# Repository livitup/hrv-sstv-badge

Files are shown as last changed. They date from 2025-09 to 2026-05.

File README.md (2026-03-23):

# DEFCON SSTV Badge






An open-source SSTV (Slow Scan Television) badge designed for DEFCON and the broader badgelife community. This badge combines amateur radio, digital imaging, and social interaction into a wearable electronic art piece shaped like a Simpsons-style retro TV with rabbit ear antennas.

## Project Overview

The DEFCON SSTV Badge enables users to:
- **Capture photos** with an integrated 2MP OV2640 camera
- **Encode images** into SSTV format with callsign overlay
- **Transmit images** via VHF/UHF radio using the SA818 transceiver
- **Receive SSTV signals** from other badges and stations
- **Store and browse** images on microSD card
- **Interact socially** through visual radio communication

Perfect for ham radio operators, makers, and anyone interested in digital modes and RF experimentation.

## Features

### Hardware Capabilities
- **RP2350B Dual-Core MCU** - QFN-80, 48 GPIOs, dedicated cores for UI and signal processing
- **SA818 VHF/UHF Transceiver** - 1W output on swappable carrier board (see below)
- **OV2640 2MP Camera** - Parallel DVP interface with 15-20 FPS live viewfinder via PIO
- **2.4" ILI9341 TFT Display** - 320x240 landscape, SPI interface
- **PCM5102A DAC + RP2350 ADC** - I2S DAC for TX audio, internal ADC for RX audio
- **MicroSD Storage** - Standalone SD socket (J10), shared SPI bus with display
- **2000mAh LiPo Battery** - 8-10 hours operation with USB-C charging
- **2x SAO Connectors** - Standard Shitty Add-On expansion ports
- **26x WS2812B LEDs** - Animated blinky chain across rabbit ears and display border

### Radio Features
- **Dual-Band Support** - VHF (134-174 MHz) and UHF (400-480 MHz) via carrier board swap
- **Multiple SSTV Modes** - Martin, Scottie, Robot modes with auto-detection
- **Automatic Operation** - No manual PTT required
- **Airplane Mode** - Physical slide switch to disable RF
- **SMA Antenna Port** - On carrier board, right-angle connector with antenna pointing up

### User Interface
- **5-Way D-Pad** - Navigation, menu selection, and photo capture (center button doubles as shutter)
- **Airplane Mode Switch** - Slide switch for RF enable/disable
- **PWR LED** - Traditional RGB LED for battery and system status
- **Blinky LEDs** - 26x WS2812B chain with animated TX/RX/idle patterns
- **Customizable Settings** - Callsign, frequency, SSTV mode, and more

## SA818 Carrier Board System

The SA818 transceiver has 2mm pitch castellated pads that are incompatible with user-swappable sockets. Instead of mounting the SA818 directly on the main badge, the design uses a full-width carrier board system.

### How It Works

The carrier board is a separate PCB (full badge width, ~120mm) that overlays the top portion of the main badge. The SA818 module, SMA connector, and antenna are ALL on the carrier board -- the main badge has zero RF traces.

**Mounting:** 4-point connection via 2x 1x8 signal headers (bottom edge) + 2x 1x3 mechanical headers (top corners, grounded for RF shielding).

**Band detection:** Each carrier has an ID resistor (0 ohm for VHF, DNP for UHF) read by the RP2350B on startup. The firmware automatically detects which carrier is installed and configures frequency limits accordingly. No DIP switches or manual configuration needed.

### Carrier Variants

- **SA818-V Carrier** - VHF (134-174 MHz) with matched VHF stubby antenna
- **SA818-U Carrier** - UHF (400-480 MHz) with matched UHF stubby antenna

### Swapping Carriers

1. Power down the badge
2. Unplug the current carrier board from the headers
3. Plug in the replacement carrier (VHF or UHF)
4. Power on -- firmware auto-detects the band and configures itself

Each carrier includes a band-matched stubby antenna, so users do not need to source separate antennas.

### Design Benefits

- Main badge PCB has no RF routing, simplifying layout and potentially enabling 2-layer PCB
- Carrier board has proper 50-ohm microstrip trace from SA818 to SMA
- Ground stitching around RF trace on carrier for shielding
- SA818 is factory-assembled onto carrier (2mm pitch not user-solderable)

## Power System

The SA818 draws up to 1.7A during TX, which would overwhelm a standard 3.3V regulator. The power system separates the radio from the digital rail:

```
LiPo (3.0-4.2V) --+---> TPS63001 (buck-boost) ---> 3.3V Rail (RP2350B, display, camera, etc.)
                   |
                   +---> TPS22919 (load switch) ---> SA818 (3.5-5.5V direct from LiPo)
```

- **TPS63001**: Buck-boost regulator, 3.3V output, handles full LiPo voltage range (3.0-4.2V)
- **TPS22919**: Load switch controls SA818 power (enables airplane mode and sleep)
- **MCP73871**: Battery charging controller with USB-C input
- **LC709203F**: Battery fuel gauge (I2C)

## Amateur Radio License Verification System

To comply with FCC Part 97 regulations, the badge includes a software-based license verification system.

### Operating Modes

- **Receive-Only Mode**: Default for unlicensed users. Can receive and decode SSTV images but cannot transmit.
- **Licensed Mode**: Full TX/RX for verified amateur radio operators.

### Verification Process

During initial setup, users enter their amateur radio callsign. The badge generates a unique unlock code from the callsign and the device's hardware serial number using SHA-256 hashing. This ensures each unlock code is specific to one badge-callsign combination, preventing casual code sharing between devices.

Licensed operators get full transmit capability with automatic callsign overlay on transmitted images (FCC requirement). Unlicensed users can still receive and view SSTV images -- all reception features work normally.

This system encourages proper amateur radio operation. It is not intended as absolute copy protection.

## Project Status

**Current Phase: PCB Layout**

| Milestone | Status |
|---|---|
| System architecture and block diagram | Complete |
| Schematic design (all sheets) | Complete, ERC clean |
| KiCad schematic entry | Complete (all sheets) |
| SA818 carrier board PCBs (VHF + UHF) | Complete |
| Bill of materials and sourcing | Complete |
| Main badge PCB layout | In progress |
| Firmware development | Not started |
| Prototype assembly and testing | Pending PCB fabrication |

## Repository Structure

```
hrv-sstv-badge/
├── CLAUDE.md                       # AI context file (project specs)
├── CMakeLists.txt                  # Build system
├── CONTRIBUTING.md                 # Contribution guidelines
├── LICENSE                         # MIT license
├── README.md                       # This file
├── docs/                           # Documentation
│   ├── block-diagram.png           # System overview diagram
│   ├── electrical-design.md        # Circuit schematics and component specs
│   ├── firmware-architecture.md    # Detailed software design
│   ├── bom.md                      # Bill of materials with costs
│   ├── bom-raw.md                  # Raw BOM data
│   ├── project-status.md           # Design status tracker
│   └── engineers-notebook/         # Design decisions and rationale
├── firmware/                       # RP2350B embedded firmware (not yet started)
├── hardware/                       # KiCad PCB design files
│   ├── main_badge/                 # Main badge KiCad project
│   ├── sa818-v-carrier/            # VHF carrier board KiCad project
│   ├── sa818-u-carrier/            # UHF carrier board KiCad project
│   ├── footprints.pretty/          # Custom KiCad footprints
│   ├── symbols/                    # Custom KiCad symbols
│   ├── pcb-design.md               # PCB layout guidelines
│   └── README.md                   # Hardware design notes
├── mechanical/                     # Badge accessories and mounting
└── src/                            # Source scaffolding
```

## Technical Specifications

| Parameter | Specification |
|---|---|
| **MCU** | Raspberry Pi RP2350B (QFN-80), Dual ARM Cortex-M33 |
| **Radio** | SA818 VHF/UHF on carrier board, 1W output |
| **Frequency Range** | VHF: 134-174 MHz, UHF: 400-480 MHz |
| **Camera** | OV2640, 2MP, parallel DVP (8-bit), QVGA for SSTV |
| **Display** | 2.4" ILI9341 TFT LCD, 320x240 landscape, SPI |
| **Audio TX** | PCM5102A DAC via I2S |
| **Audio RX** | RP2350B internal ADC with anti-alias filter |
| **Storage** | MicroSD via standalone SD socket J10 (shared SPI bus) |
| **Battery** | 2000mAh LiPo, USB-C charging (MCP73871) |
| **Regulator** | TPS63001 buck-boost, 3.3V output |
| **Operating Time** | 8-10 hours typical use |
| **LEDs** | 26x WS2812B (10x 5050 on ears, 16x 2020 on border) + RGB PWR LED |
| **Expansion** | 2x SAO (Shitty Add-On) connectors |
| **Dimensions** | ~120mm x 120mm body, ~190mm total height with ears and feet |
| **Form Factor** | Retro TV shape with rabbit ear antennas, wearable badge (no enclosure) |

## Software Architecture

The firmware uses a bare-metal dual-core design on the RP2350B for deterministic SSTV timing:

- **Core 0**: User interface, file system, system management, display updates
- **Core 1**: SSTV encoding/decoding, audio DSP, camera control, radio management

PIO state machines handle hardware-timed signals (camera capture, WS2812B data, audio clocking). DMA transfers move data without CPU intervention. No RTOS -- bare metal for microsecond-precision SSTV timing.

### Development Environment
- **Language**: C11 (ISO/IEC 9899:2011)
- **Compiler**: GCC ARM Embedded (arm-none-eabi-gcc)
- **Build System**: CMake with Raspberry Pi Pico SDK
- **Debugger**: OpenOCD + GDB via SWD (Tag-Connect)

## Assembly Model

This badge uses a production kit approach:

- **Factory-assembled**: All SMD components on main badge, SA818 onto carrier boards
- **User-assembled at conference**: Through-hole parts (switches, connectors, pin headers)
- **User-configured**: Plug in VHF or UHF carrier board, insert battery, insert SD card

## Getting Started

### Prerequisites
- **Amateur Radio License** - Required for transmit operation (receive works without)
- **Basic Soldering Skills** - Through-hole soldering for final assembly

### Firmware Installation
1. Download the latest firmware release
2. Connect via USB-C while holding BOOTSEL
3. Copy the UF2 file to the mounted drive
4. Configure callsign, frequency, and SSTV mode

### Build from Source
```bash
mkdir build && cd build
cmake .. -DCMAKE_BUILD_TYPE=Debug
make -j4

# Flash via UF2 bootloader
cp defcon_sstv_badge.uf2 /Volumes/RPI-RP2/

# Or flash via SWD
openocd -f interface/cmsis-dap.cfg -f target/rp2350.cfg
```

## Badgelife Integration

- **SAO Compatibility** - 2x standard Shitty Add-On connectors (I2C + 2 GPIOs each)
- **Badge-to-Badge Communication** - SSTV image exchange over the air
- **Retro TV Aesthetic** - PCB shaped like a classic TV with rabbit ear antennas
- **Animated LEDs** - 26 WS2812B LEDs with TX/RX/idle animations across ears and display border
- **Open Source** - Hardware and software fully open for hacking and modification

## Legal and Compliance

### Amateur Radio Requirements
- Valid amateur radio license required for transmit operation
- Operate only within licensed frequency allocations
- Follow local RF exposure and power limitations
- Respect band plans and operating procedures

### Regulatory
- FCC Part 97 (United States)
- IC RSS (Canada)
- CE marking (Europe)
- Consult local regulations for other countries

### Safety
- RF radiation exposure -- use appropriate antenna and power levels
- LiPo battery safety -- follow proper charging and storage procedures
- ESD precautions during assembly

## Contributing

Contributions from the badgelife and amateur radio communities are welcome.

### How to Contribute
- **Report Issues** - Found a bug? Open a GitHub issue
- **Submit Pull Requests** - Code improvements, documentation fixes
- **Share Ideas** - Feature requests and enhancement suggestions
- **Test Hardware** - Help validate designs and assembly procedures

### Development Areas
- **Hardware**: PCB layout, carrier board design
- **Firmware**: SSTV algorithms, UI, power management
- **Documentation**: Assembly guides, user manuals, tutorials

## License

- **Hardware**: [CERN-OHL-S v2](https://cern-ohl.web.cern.ch/)
- **Software**: [MIT License](LICENSE)
- **Documentation**: [CC BY-SA 4.0](https://creativecommons.org/licenses/by-sa/4.0/)

## Support and Community

- **Documentation** - See the `docs/` directory
- **Issues** - Open a GitHub issue for bugs or questions
- **Discussions** - Use GitHub Discussions for general topics
- **DEFCON** - Hardware Hacking Village and Ham Radio Village

---

**Made for the badgelife and amateur radio communities. See you at DEFCON!**

**73s!**

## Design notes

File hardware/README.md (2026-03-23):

# DEFCON SSTV Badge — Hardware Design

This directory contains all KiCad design files for the DEFCON SSTV Badge.

## Directory Structure

```
hardware/
├── main_badge/                    # Main badge KiCad project
│   ├── defcon-sstv-badge.kicad_pro    # Project file
│   ├── defcon-sstv-badge.kicad_sch    # Top-level schematic
│   ├── defcon-sstv-badge.kicad_pcb    # PCB layout (in progress)
│   ├── power.kicad_sch                # Power: TPS63001, TPS22919, MCP73871, LC709203F
│   ├── audio.kicad_sch                # Audio: PCM5102A DAC, TX/RX filters
│   ├── camera-display.kicad_sch       # Display (ILI9341) + Camera (OV2640)
│   ├── mcu.kicad_sch                  # RP2350B, crystal, flash, USB-C
│   ├── switches.kicad_sch             # D-pad, airplane switch, PWR LED, WS2812B chain
│   └── connectors.kicad_sch           # SAO×2, carrier headers, SD card, Tag-Connect
├── sa818-v-carrier/               # VHF carrier board (134-174 MHz)
│   ├── sa818-v-carrier.kicad_pro
│   ├── sa818-v-carrier.kicad_sch
│   └── sa818-v-carrier.kicad_pcb      # PCB layout complete
├── sa818-u-carrier/               # UHF carrier board (400-480 MHz)
│   ├── sa818-u-carrier.kicad_pro
│   ├── sa818-u-carrier.kicad_sch
│   └── sa818-u-carrier.kicad_pcb      # PCB layout complete
├── symbols/                       # Custom KiCad symbol libraries
├── footprints.pretty/             # Custom KiCad footprint libraries
├── fp-lib-table                   # Footprint library table
├── sym-lib-table                  # Symbol library table
├── pcb-design.md                  # PCB outline, dimensions, and layout zones
└── README.md                      # This file
```

## Design Overview

### Main Badge
- **PCB shape**: Simpsons-style retro TV with rabbit ear antennas and stubby feet
- **Body dimensions**: 120mm × 120mm
- **Total height**: ~190mm (ears + body + feet)
- **Layer count**: Targeting 4-layer (signal/ground/power/signal)
- **Thickness**: 1.6mm standard FR4
- **Soldermask**: Purple with white silkscreen (Simpsons TV aesthetic)

### Carrier Boards
- **Size**: Full badge width (~120mm), overlays top of main badge
- **Purpose**: SA818 module + SMA connector + antenna — all RF on carrier, none on main badge
- **Variants**: VHF (SA818-V) and UHF (SA818-U), identical PCB with different module population
- **PCB layout**: Complete for both variants

### Key Design Decisions
- **No RF on main badge** — all RF routing is on the carrier board
- **Carrier is front-mounted** — overlays the top portion of the main badge, top edges flush
- **4-point mounting** — 2× 1×8 signal headers + 2× 1×3 mechanical headers (GND for RF shielding)
- **Band auto-detect** — carrier ID resistor (0Ω = VHF, DNP = UHF) read by firmware on startup

## KiCad Version

This project uses **KiCad 8**. Custom symbols and footprints are included in the repository.

## Schematic Status

All schematic sheets are complete and ERC clean:
- Power, Audio, Display/Camera, MCU, Switches, Connectors (main badge)
- SA818-V Carrier, SA818-U Carrier

## PCB Layout Status

- **Carrier boards**: Complete (VHF and UHF)
- **Main badge**: Board outline complete (TV shape with ears and feet), component placement and routing in progress

## Related Documentation

- [PCB Design](pcb-design.md) — Board outline, dimensions, component placement zones
- [Electrical Design](../docs/electrical-design.md) — Circuit schematics and component specs
- [BOM](../docs/bom.md) — Bill of materials with costs and sourcing
- [Project Status](../docs/project-status.md) — Design and implementation tracker

---

*73 de HRV*

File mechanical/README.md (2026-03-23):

# DEFCON SSTV Badge Mechanical Design

This directory contains mechanical design files and accessories for the DEFCON SSTV Badge.

## 🎯 Badge Design Philosophy

As a DEFCON badge, this device is designed to be worn **without a traditional enclosure**. The PCB itself is the final product, optimized for:
- **Comfortable neck wearing** - Balanced weight distribution and rounded edges
- **Visual appeal** - Retro TV aesthetic with visible components as art
- **Durability** - Robust PCB design to withstand conference handling
- **Accessibility** - All user controls and connectors easily accessible

## 📐 Physical Specifications

### Dimensions and Weight
| Parameter | Value | Notes |
|---|---|---|
| **PCB Size** | 120mm × 120mm body, ~190mm total height | TV-shaped outline with rabbit ear antennas and stubby feet |
| **Thickness** | ~15mm max | Including tallest components |
| **Weight** | ~150g | Including 2000mAh battery |
| **Balance Point** | Center-bottom | Optimized for comfortable wearing |

### Wearability Features
- **Rounded PCB edges** - No sharp corners that could snag or poke
- **Component placement** - Heavy components (battery, SA818) positioned for balance
- **Smooth back side** - Minimal components on reverse for comfort against clothing
- **Lanyard mounting** - Centered oval slot for easy lanyard attachment

## 📁 Directory Structure

```
mechanical/
└── assembly/              # Assembly-related mechanical files
    ├── alignment-jigs/    # 3D printable assembly aids
    ├── test-fixtures/     # Programming and testing jigs  
    ├── protective-accessories/ # Optional protective items
    └── mounting-solutions/     # Lanyard and wearing accessories
```

## 🛠️ Assembly Considerations

### PCB as Final Product
- **No case required** - The PCB is designed to be worn directly
- **Component protection** - Critical components positioned away from edges
- **Connector accessibility** - USB-C, SMA, and microSD easily accessible
- **Button placement** - Optimized for thumb operation when worn

### Weight Distribution
The badge is designed with weight balance in mind:
- **Battery placement** - Center-bottom for stability when hanging
- **Display position** - Upper area for easy viewing when worn
- **Heavy components** - SA818 and camera positioned to minimize swing

## 🔧 Assembly Aids and Jigs

### Recommended Assembly Tools
While not required, these mechanical aids can improve assembly quality:

#### Soldering Alignment Jig
- **Purpose**: Hold PCB steady during component placement
- **Material**: 3D printed PLA or PETG
- **Features**: Cutouts for component access, stable base

#### Programming Test Fixture  
- **Purpose**: Secure connection for firmware updates
- **Features**: Pogo pin contacts, consistent positioning
- **Benefit**: Reduces wear on debug connectors

#### Component Placement Guide
- **Purpose**: Ensure correct component orientation
- **Material**: Laser-cut acrylic or 3D printed
- **Features**: Component outlines, polarity indicators

*Note: 3D files for these jigs will be added as the design matures and assembly experience is gained.*

## 🎒 Wearing and Transportation

### Lanyard Attachment
- **Mounting**: Single oval slot at top center (~20mm × 5mm)
- **Hardware**: None required - lanyard threads directly through slot
- **Lanyard types**: Standard conference lanyards compatible
- **Load rating**: PCB designed for >2kg static load

### Protective Considerations
While no enclosure is used, consider these protective measures:

#### Display Protection
- **Screen protector**: Standard phone screen protector can be cut to fit
- **Material**: Tempered glass or PET film
- **Application**: Clean installation prevents air bubbles

#### Component Guards (Optional)
- **Button protection**: 3D printed caps prevent accidental activation
- **Antenna guard**: Protective cover for SMA connector during transport
- **Camera lens**: Clear protective cover to prevent scratches

#### Storage and Transport
- **Anti-static bag**: Prevents ESD damage during storage
- **Foam padding**: Custom-cut foam for shipping protection
- **Component covers**: Protect delicate parts during assembly

## 📏 Mechanical Testing

### Durability Requirements
The badge must withstand typical conference conditions:

#### Drop Testing
- **Height**: 1 meter drop onto concrete
- **Orientations**: Face-down, back-down, edge impact
- **Criteria**: No component damage, continued operation

#### Wear Testing  
- **Duration**: 12+ hours continuous wearing
- **Comfort**: No pressure points or sharp edges
- **Balance**: Minimal swinging or rotation when walking

#### Environmental
- **Temperature**: 0°C to 40°C operation
- **Humidity**: Up to 80% relative humidity  
- **Vibration**: Walking, dancing, general conference activity

## 🔄 Design Evolution

### Feedback Integration
As badges are built and worn, mechanical improvements may include:
- **Comfort optimization** - Edge radius adjustments
- **Weight reduction** - Component selection and placement
- **Durability improvements** - Reinforcement of stress points
- **Accessory development** - Community-requested add-ons

### Version Tracking
- **Rev A**: Initial design (current)
- **Rev B+**: Incorporate user feedback and lessons learned

## 🤝 Community Contributions

### Accessory Development
The community is encouraged to develop and share:
- **Custom lanyards** - Themed designs for different cons
- **Mounting solutions** - Belt clips, magnetic mounts, stands
- **Protective gear** - Cases for specific use scenarios
- **Display stands** - For showcasing badges when not worn

### Sharing Guidelines
- **File formats**: STL for 3D printing, DXF for laser cutting
- **Documentation**: Include print settings, material recommendations
- **Testing**: Verify fit and function before sharing
- **Licensing**: Use compatible open-source licenses

## 📚 Reference Documents

For detailed design information, see:
- **[Electrical Design](../docs/electrical-design.md)** - Circuit schematics and component specs
- **[Hardware Design](../hardware/README.md)** - PCB specifications and design files
- **[BOM](../docs/bom.md)** - Complete parts list including mechanical hardware

## ⚠️ Safety Considerations

### Electrical Safety
- **Battery protection** - LiPo safety circuit prevents overcharge
- **RF exposure** - Amateur radio compliance with FCC Part 97
- **Component protection** - ESD precautions during handling

### Mechanical Safety  
- **Sharp edges** - All PCB edges rounded and smooth
- **Component security** - All parts firmly attached, no loose items
- **Lanyard slot** - Centered slot rated for safety loads
- **Material safety** - Lead-free solder, RoHS compliant components

---

**The badge IS the product - no assembly required beyond electronics!** 

*Ready to wear your radio on your sleeve (or around your neck)? 📡*

*73 de [Your Callsign]*

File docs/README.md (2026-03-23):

# Documentation

This directory contains technical documentation for the DEFCON SSTV Badge project.

## System Overview

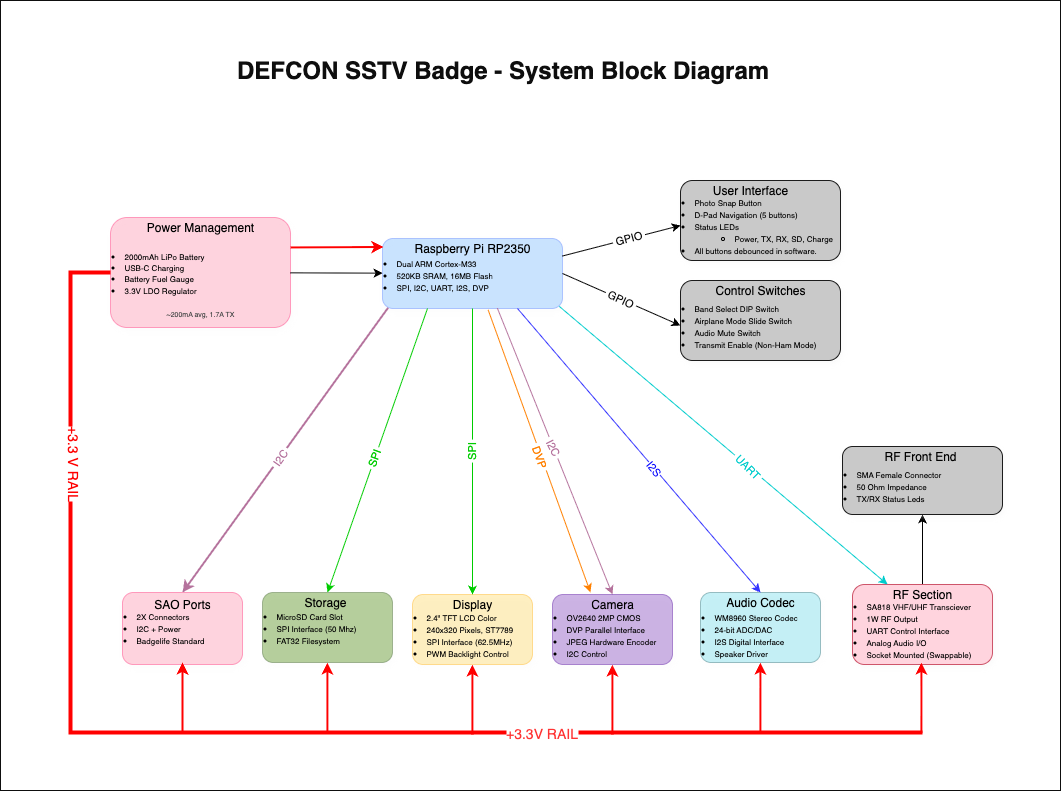
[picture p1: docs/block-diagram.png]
System Block Diagram


The DEFCON SSTV Badge combines amateur radio, digital imaging, and embedded systems into a wearable electronic badge for the badgelife community. The system uses a dual-core RP2350B microcontroller with SA818 radio transceiver to capture, encode, transmit, and receive SSTV (Slow Scan Television) images.

## Documentation Files

### Hardware Design

**[electrical-design.md](electrical-design.md)**
Complete electrical design with circuit schematics, component specifications, GPIO assignments, and pin connections for all subsystems.

**[bom.md](bom.md)**
Bill of materials with part numbers, quantities, cost estimates, and sourcing recommendations.

**[bom-raw.md](bom-raw.md)**
Raw BOM data exported from KiCad.

**[project-status.md](project-status.md)**
Design and implementation status tracker for all subsystems.

### Software Architecture

**[firmware-architecture.md](firmware-architecture.md)**
Dual-core firmware design, real-time constraints, SSTV signal processing, and embedded C API design.

### Engineer's Notebook

**[engineers-notebook/](engineers-notebook/)**
Design decisions, trade-off analyses, and educational background material. These documents explain *why* the design is what it is.

## Technical Specifications

| Parameter | Specification |
|---|---|
| **Microcontroller** | Raspberry Pi RP2350B (Dual ARM Cortex-M33, QFN-80) |
| **Radio** | SA818 VHF/UHF transceiver, 1W output (on carrier board) |
| **Camera** | OV2640 2MP, parallel DVP interface |
| **Display** | 2.4" ILI9341 TFT LCD, 320x240 pixels |
| **Audio** | PCM5102A DAC (TX) + RP2350 ADC (RX) |
| **Storage** | MicroSD card (user supplied) |
| **Power** | 2000mAh LiPo, USB-C charging, TPS63001 buck-boost |
| **Battery Life** | 8-10 hours typical use |
| **Dimensions** | ~120mm x 120mm TV-shaped PCB + rabbit ear antennas with ball tips |
| **Interfaces** | SMA antenna (on carrier), 2x SAO expansion ports |

## Signal Flow

### Transmit Mode
Photo capture → Image processing → Callsign overlay → SSTV encoding → PCM5102A DAC → SA818 radio → Antenna

### Receive Mode
Antenna → SA818 radio → RP2350 ADC → SSTV decoding → Image reconstruction → Display → SD card storage

### User Interface
D-pad controls → RP2350 Core 0 → Menu navigation → Display updates → Status feedback

---

*This documentation is continuously updated as the project evolves. Check the git history for the latest changes and improvements.*

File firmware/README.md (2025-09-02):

# DEFCON SSTV Badge Firmware

This directory contains all firmware source code for the DEFCON SSTV Badge running on the Raspberry Pi RP2350 microcontroller.

## 🏗️ Architecture

The firmware uses a dual-core architecture:
- **Core 0**: User Interface, file system, system management
- **Core 1**: SSTV processing, audio DSP, camera control

See [../docs/firmware-architecture.md](../docs/firmware-architecture.md) for detailed design information.

## 📁 Directory Structure

```
firmware/
├── src/                    # Main source code
│   ├── main.c             # Application entry point
│   ├── core0_main.c       # Core 0 user interface tasks
│   ├── core1_main.c       # Core 1 signal processing tasks
│   ├── hardware/          # Hardware abstraction layer
│   ├── drivers/           # Device drivers
│   ├── sstv/              # SSTV encoding/decoding
│   ├── ui/                # User interface system
│   └── utils/             # Utility functions
├── lib/                    # External libraries
│   ├── pico-sdk/          # Raspberry Pi Pico SDK (submodule)
│   └── third-party/       # Third-party libraries
├── examples/               # Example programs and tests
│   ├── blink/             # Basic LED blink test
│   ├── display/           # Display driver test
│   ├── camera/            # Camera interface test
│   └── sstv/              # SSTV algorithm tests
├── build/                  # Build output directory (auto-generated)
└── CMakeLists.txt         # Build configuration
```

## 🛠️ Development Setup

### Prerequisites

1. **Raspberry Pi Pico SDK**
   ```bash
   git clone https://github.com/raspberrypi/pico-sdk.git
   cd pico-sdk
   git submodule update --init
   export PICO_SDK_PATH=$(pwd)
   ```

2. **Build Tools**
   ```bash
   # Ubuntu/Debian
   sudo apt update
   sudo apt install cmake gcc-arm-none-eabi libnewlib-arm-none-eabi build-essential

   # macOS  
   brew install cmake gcc-arm-embedded

   # Windows - Install via MSYS2 or use WSL
   ```

3. **Optional Tools**
   - **OpenOCD**: For debugging with SWD probe
   - **picotool**: For UF2 file manipulation
   - **minicom/screen**: For serial console debugging

### Building the Firmware

1. **Clone this repository**
   ```bash
   git clone https://github.com/[username]/defcon-sstv-badge.git
   cd defcon-sstv-badge/firmware
   ```

2. **Create build directory**
   ```bash
   mkdir build
   cd build
   ```

3. **Configure build**
   ```bash
   cmake .. -DCMAKE_BUILD_TYPE=Release
   ```

4. **Compile**
   ```bash
   make -j4
   ```

5. **Output files**
   - `defcon_sstv_badge.uf2` - Main firmware for drag-and-drop install
   - `defcon_sstv_badge.elf` - ELF file for debugging
   - `defcon_sstv_badge.bin` - Binary for direct flash programming

### Flashing the Firmware

#### Method 1: UF2 Bootloader (Easiest)
1. Hold BOOTSEL button while connecting USB
2. RP2350 appears as USB drive
3. Drag `defcon_sstv_badge.uf2` to the drive
4. Device automatically reboots with new firmware

#### Method 2: SWD Programming (For Development)
```bash
# Using OpenOCD with Raspberry Pi Debug Probe
openocd -f interface/cmsis-dap.cfg -f target/rp2040.cfg -c "program defcon_sstv_badge.elf verify reset exit"
```

#### Method 3: picotool (Command Line)
```bash
# Put device in bootloader mode, then:
picotool load defcon_sstv_badge.uf2
picotool reboot
```

## 🧪 Testing and Development

### Running Examples

Each example in the `examples/` directory can be built independently:

```bash
cd examples/blink
mkdir build && cd build
cmake .. 
make
# Flash the resulting .uf2 file
```

### Debug Console

The firmware provides a debug console over USB CDC (virtual serial port):

```bash
# Linux/macOS
screen /dev/ttyACM0 115200

# Windows
# Use PuTTY or similar terminal program
# Connect to COMx port at 115200 baud
```

Debug commands available:
- `status` - Show system status
- `test-camera` - Test camera functionality  
- `test-sstv` - Test SSTV encoding/decoding
- `freq <MHz>` - Set radio frequency
- `mem` - Show memory usage

### Debugging with GDB

```bash
# Start OpenOCD in one terminal
openocd -f interface/cmsis-dap.cfg -f target/rp2040.cfg

# In another terminal, start GDB
arm-none-eabi-gdb defcon_sstv_badge.elf
(gdb) target extended-remote localhost:3333
(gdb) load
(gdb) monitor reset init
(gdb) break main
(gdb) continue
```

## ⚙️ Configuration

### Build Options

Configure build options in `CMakeLists.txt` or via command line:

```bash
# Enable debug output
cmake .. -DCMAKE_BUILD_TYPE=Debug -DENABLE_DEBUG=ON

# Disable specific features  
cmake .. -DENABLE_CAMERA=OFF -DENABLE_AUDIO=OFF

# Set frequency band
cmake .. -DDEFAULT_BAND=VHF
```

### Runtime Configuration

The badge stores configuration in `config/settings.ini` on the microSD card:

```ini
[radio]
callsign = N0CALL
frequency = 145500000
mode = martin1
power = 1

[display]
brightness = 128
timeout = 30000

[system]
auto_save = true
debug_log = false
```

## 🐛 Troubleshooting

### Common Issues

**Build Errors:**
- Ensure `PICO_SDK_PATH` environment variable is set
- Check that all git submodules are initialized
- Verify cross-compiler is installed and in PATH

**Flash/Programming Issues:**
- Try different USB cable (data-capable, not power-only)
- Ensure device is in bootloader mode (BOOTSEL button)
- Check permissions on Linux (`sudo usermod -a -G dialout $USER`)

**Runtime Issues:**
- Check debug console for error messages
- Verify all hardware connections match schematic
- Test with minimal configuration (disable non-essential features)

**Radio Issues:**
- Verify amateur radio license and frequency allocations
- Check antenna connection and SWR
- Ensure SA818 module is properly seated

### Getting Help

1. **Check the debug console** for error messages
2. **Review the documentation** in `docs/` directory
3. **Search existing issues** on GitHub
4. **Create a new issue** with:
   - Hardware revision
   - Firmware version
   - Debug console output
   - Steps to reproduce

## 🤝 Contributing

See [../CONTRIBUTING.md](../CONTRIBUTING.md) for detailed contribution guidelines.

### Code Style

- **Indentation**: 4 spaces (no tabs)
- **Naming**: `snake_case` for functions/variables, `UPPER_CASE` for constants
- **Comments**: Doxygen format for functions, inline for complex logic
- **Line length**: Maximum 100 characters

### Testing Requirements

- All new features must include example code
- Hardware-dependent code should have simulation/mock alternatives
- Performance-critical code should include benchmarks
- Breaking changes require migration guide

## 📊 Performance Metrics

Current firmware performance on RP2350 @ 125MHz:

| Function | Execution Time | CPU Usage | Memory |
|---|---|---|---|
| SSTV Line Encode | 15ms | 65% Core 1 | 32KB |
| Display Update | 8ms | 25% Core 0 | 76KB |
| Camera Capture | 200ms | 80% Core 1 | 150KB |
| SD Card Write | Variable | 10% Core 0 | 8KB |

## 📜 License

This firmware is released under the MIT License. See [../LICENSE](../LICENSE) for details.

---

**Ready to start coding? Check out the examples directory and dive in!** 🚀

*73 de [Your Callsign]* 📡

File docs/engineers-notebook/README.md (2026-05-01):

# Engineer's Notebook

This directory contains design decisions, trade-off analyses, and educational background material for the DEFCON SSTV Badge project.

**These documents explain *why* the design is what it is.** The main documentation files describe *what* the design is.

---

## Contents

### Design Decisions

- **[electrical-design-decisions.md](electrical-design-decisions.md)** — Power system redesign rationale, buck-boost regulator selection, audio codec selection (PCM5102A vs WM8960), carrier board rationale, MCU variant selection (RP2350B), display/camera interface decisions, alternate part options

### Trade-Off Analyses

- **[rda1846-vs-sa818-analysis.md](rda1846-vs-sa818-analysis.md)** — Detailed comparison of using the bare RDA1846S transceiver IC vs the SA818 module (which contains the RDA1846S internally). Covers engineering effort, cost, SSTV audio compatibility, assembly, sourcing risk, and carrier board implications. **Decision: Stay with SA818.**

- **[harmonic-filter-design.md](harmonic-filter-design.md)** — Why both SA818 carriers need a low-pass filter for FCC Part 97 compliance, why a discrete 7-pole Chebyshev was chosen over a single ceramic chip filter, calculated component values for VHF (fc=155 MHz) and UHF (fc=470 MHz), component selection rules, layout requirements, and validation strategy for tune-once production runs. **Decision: Add discrete LPF to both VHF and UHF carriers.**

### PCB Layout Optimization

- **[gpio-optimization.md](gpio-optimization.md)** — Complete GPIO reassignment to minimize trace crossings. Maps each peripheral group to one physical side of the QFN-80 package: display+camera on left, controls on bottom, SA818 on right, audio on top. Includes RP2350B pin layout diagram, peripheral mux verification, carrier header matching, and I2S pin-order matching to PCM5102A. Reduced trace crossings from ~8-12 to 1.

- **[gpio-rewiring-checklist.md](gpio-rewiring-checklist.md)** — Step-by-step checklist used to rewire U1 in the KiCad schematic. Groups signals by dependency order to avoid conflicts (especially SA818 which has overlapping old/new GPIOs). Includes post-rewiring verification steps. **Completed 2026-03-31, all 48 GPIOs verified programmatically.**

### Educational Background

- **[audio-concepts-explained.md](audio-concepts-explained.md)** — Beginner-friendly explanation of filtering, bias, DC blocking, anti-aliasing, and other audio concepts used in the badge's RX/TX circuits

---

## How to Use This Notebook

1. **New contributors**: Read these documents to understand *why* design decisions were made
2. **Design changes**: Document new decisions here before implementing them
3. **Troubleshooting**: Understanding the rationale helps diagnose issues

---

*Last updated: 2026-04-30*

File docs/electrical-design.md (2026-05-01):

# Electrical Design

This document describes the electrical design of the DEFCON SSTV Badge, including circuit schematics, component specifications, and pin assignments.

*For design rationale and trade-off analyses, see [Engineer's Notebook: Electrical Design Decisions](engineers-notebook/electrical-design-decisions.md).*

---

## Power System

### Architecture

The SA818 runs directly from the LiPo battery (via load switch), not through the 3.3V regulator. This separates the 1.7A TX current spikes from the main digital rail.

```
                    ┌───────────────────┐
    USB-C 5V ──────►│   MCP73871        │
                    │ Charge Controller │
                    └────────┬──────────┘
                             │
                             ▼
                    ┌─────────────────┐
                    │  2000mAh LiPo   │
                    │   3.0V - 4.2V   │
                    └───────┬─────────┘
                            │
              ┌─────────────┼─────────────┐
              │             │             │
              ▼             ▼             ▼
        ┌──────────┐  ┌──────────┐  ┌──────────┐
        │ LC709203 │  │ TPS63001 │  │ TPS22919 │
        │Fuel Gauge│  │Buck-Boost│  │ Load SW  │
        └──────────┘  └────┬─────┘  └────┬─────┘
                           │             │
                      3.3V Rail      SA818 Direct
                           │         (3.5-5.5V)
                           ▼             │
                    ┌──────────────┐     │
                    │ RP2350       │     │
                    │ Display      │     ▼
                    │ Camera       │  ┌──────────┐
                    │ SD Card      │  │  SA818   │
                    │ Codec        │  │ 1W Radio │
                    └──────────────┘  └──────────┘
```

### Load Analysis

**3.3V Rail loads (excluding SA818):**

| Subsystem | Current | Notes |
|---|---|---|
| RP2350 | ~50mA | Varies with clock/activity |
| Display + backlight | ~50-80mA | Backlight dominates |
| Camera (active) | ~50mA | Only when capturing |
| SD card (active) | ~50mA | Burst during write |
| PCM5102A DAC | ~10mA | |
| Misc (LEDs, etc.) | ~20mA | |
| **Total typical** | **~250mA** | |
| **Peak** | **~400mA** | All subsystems active |

**SA818 power (separate rail):**

| Mode | Current |
|---|---|
| Standby | ~20mA |
| RX active | ~50mA |
| TX (1W) | ~1.5-1.7A |

---

## Buck-Boost Converter (TPS63001)

*See [Engineer's Notebook](engineers-notebook/electrical-design-decisions.md#buck-boost-regulator-selection) for regulator selection rationale.*

### TPS63001 Specifications

| Spec | Value |
|---|---|
| Input | 1.8V - 5.5V |
| Output | Fixed 3.3V |
| Max Current | 1.2A |
| Peak Efficiency | ~93% |
| Package | 3x3mm QFN-10 |

### External Components

| Ref | Value | Package | Notes |
|-----|---|---|---|
| L1 | 1µH | 3x3mm | Coilcraft XAL3030 or similar |
| C_IN1 | 10µF | 0805 | X5R/X7R, 10V |
| C_IN2 | 10µF | 0805 | X5R/X7R, 10V |
| C_OUT1 | 10µF | 0805 | X5R/X7R, 10V |
| C_OUT2 | 10µF | 0805 | X5R/X7R, 10V |
| R_PS | 1MΩ | 0402 | Power save threshold (optional) |

---

## SA818 Load Switch

### Purpose

The TPS22919 load switch provides:
- MCU control over SA818 power (airplane mode, sleep)
- Isolation of 1.7A TX current spikes from main rail
- Clean power sequencing

### TPS22919 Specifications

| Parameter | Value |
|---|---|
| Input voltage | 1.0V - 5.5V |
| Continuous current | 1.5A |
| Peak current | 3A |
| On resistance | 90mΩ typical |
| Package | SOT-23-5 |
| Price | ~$0.50 |

### Implementation

```
    VBAT (from LiPo) ──────┬──────────────────────►  To TPS63001
                           │
                           │
                      ┌────┴────┐
                      │         │
                VIN ──┤ TPS22919├── VOUT ──┬──► To SA818 VCC
                      │         │          │
              GPIO ──►┤ ON/EN   │     C1 ══╪══ 100µF (bulk)
                      │         │          │
                GND ──┤ GND     │     C2 ══╪══ 10µF (bypass)
                      │         │          │
                      └─────────┘         GND
```

### Control Logic

| GPIO State | TPS22919 | SA818 | Mode |
|---|---|---|---|
| HIGH | ON | Powered | Normal operation |
| LOW | OFF | Unpowered | Airplane mode / sleep |

---

## USB-C Interface

### Overview

The USB-C connector provides two functions:
1. **Power input** — 5V from USB to MCP73871 battery charger
2. **Data** — D+/D- to RP2350 for programming and UF2 bootloader

### Circuit Design

```
                                          ┌─────────────────────┐
                                          │   USB-C Receptacle  │
                                          │   (Through-hole)    │
                                          │                     │
    To MCP73871 VBUS ◄────────┬───────────┤ VBUS (A4,B4,A9,B9)  │
                              │           │                     │
                         ┌────┴────┐      │                     │
                         │PESD5V0  │      │                     │
                         │(TVS)    │      │                     │
                         └────┬────┘      │                     │
                              │           │                     │
                             GND          │                     │
                                          │                     │
                         ┌─────────────┐  │                     │
    To RP2350 USB_DP ◄───┤ USBLC6-2SC6 │◄─┤ D+ (A6,B6)          │
    To RP2350 USB_DM ◄───┤ (ESD TVS)   │◄─┤ D- (A7,B7)          │
                         └─────────────┘  │                     │
                                          │                     │
                              ┌───────────┤ CC1 (A5)            │
                              │           │                     │
                         5.1kΩ resistor   │                     │
                              │           │                     │
                              ├───────────┤ CC2 (B5)            │
                              │           │                     │
                         5.1kΩ resistor   │                     │
                              │           │                     │
                             GND          │                     │
                                          │                     │
                             GND ─────────┤ GND (A1,B1,A12,B12) │
                                          │                     │
                                          │ SBU1, SBU2 (NC)     │
                                          │ TX1/RX1 pairs (NC)  │
                                          │ TX2/RX2 pairs (NC)  │
                                          └─────────────────────┘
```

### Component Selection

| Component | Part Number | Package | Purpose | Est. Cost |
|---|---|---|---|---|
| USB-C Receptacle | USB4105-GF-A (GCT) | SMT+TH hybrid | Power + data connector (USB 2.0) | ~$1.00 |
| VBUS TVS | PESD5V0S1BL | SOD-323 | Surge/ESD protection on 5V | ~$0.10 |
| Data ESD | USBLC6-2SC6 | SOT-23-6 | TVS array for D+/D- | ~$0.20 |
| CC Resistors | 2× 5.1kΩ | 0402 | UFP (sink) identification | ~$0.02 |
| Bulk Capacitor | 10µF ceramic | 0603 | VBUS decoupling | ~$0.05 |
| **Total** | | | | **~$1.17** |

### Design Notes

**CC Resistors (5.1kΩ):**
- Required on both CC1 and CC2 to identify as a USB sink (UFP)
- Tells USB-C sources to provide 5V at up to 1.5A (default USB-C power)
- No USB-PD negotiation needed — simple 5V charging is sufficient

**ESD Protection:**
- USBLC6-2SC6 protects D+/D- with fast TVS diodes
- PESD5V0S1BL on VBUS protects against surges from cheap chargers and ESD
- Both are cheap insurance for a badge that gets plugged into random USB ports

**RP2350 USB Connection:**
- RP2350 has dedicated USB_DP and USB_DM pins (not GPIO)
- Built-in USB 1.1 Full Speed PHY
- Handles cable orientation automatically (symmetric D+/D- routing)
- Supports UF2 bootloader for drag-and-drop firmware updates

**Through-hole Connector:**
- More robust than SMD for a wearable badge
- Withstands repeated plug/unplug cycles better
- Easier hand-soldering for kit assembly

**VBUS Routing:**
- Direct to MCP73871 VBUS input
- 10µF bulk capacitor near connector
- MCP73871 handles charge current limiting and battery management

### USB-C Pinout (16-pin)

| Pin | Name | Connection |
|-----|---|---|
| A1, B1, A12, B12 | GND | Ground |
| A4, B4, A9, B9 | VBUS | To MCP73871 + TVS |
| A5 | CC1 | 5.1kΩ to GND |
| B5 | CC2 | 5.1kΩ to GND |
| A6, B6 | D+ | To USBLC6-2 → RP2350 USB_DP |
| A7, B7 | D- | To USBLC6-2 → RP2350 USB_DM |
| A2, A3, B2, B3 | TX/RX | NC (USB 2.0 only) |
| A8, B8 | SBU | NC |

*See [Engineer's Notebook](engineers-notebook/electrical-design-decisions.md#usb-c-interface) for alternate part options.*

---

## Battery Management

### Overview

The battery system provides portable power with USB charging and accurate state-of-charge monitoring.

| Component | Part | Function |
|---|---|---|
| Battery | 2000mAh LiPo pouch cell | Energy storage |
| Charger | MCP73871-2CCI/ML | Charge control + load sharing |
| Fuel Gauge | LC709203FQH-01TWG | State-of-charge monitoring |
| Connector | JST-PH 2-pin | Battery connection |

### System Block Diagram

```
                                    ┌─────────────────────────────┐
    USB-C VBUS ────────────────────►│        MCP73871             │
    (5V from host)                  │   Charge Controller         │
                                    │                             │
                                    │  IN ──────► VBAT ──────► OUT│
                                    │             │               │
                                    │  STAT1  STAT2  PG           │
                                    └───┬───────┬────┬────────────┘
                                        │       │    │        │
                                   (to MCU for  │    │        │
                                    status LEDs)│    │        ▼
                                                │    │   ┌─────────┐
                      ┌─────────────────────────┼────┼───┤  LiPo   │
                      │                         │    │   │ 2000mAh │
                      │                         │    │   └────┬────┘
                      │   ┌─────────────────────┘    │        │
                      │   │                          │        │
                      ▼   ▼                          │        │
                  ┌───────────┐                      │        │
                  │ LC709203F │◄─────────────────────┼────────┘
                  │Fuel Gauge │  (monitors battery)  │
                  └─────┬─────┘                      │
                        │ I2C                        │
                        ▼                            ▼
                    RP2350                    To TPS63001 + TPS22919
                  (SoC reading)                  (power rails)
```

### MCP73871 Charge Controller

*See [Engineer's Notebook](engineers-notebook/electrical-design-decisions.md#why-mcp73871) for selection rationale.*

#### MCP73871 Circuit

```
                                   MCP73871-2CCI/ML
                                  ┌────────────────────┐
                                  │                    │
    USB VBUS (5V) ───┬───[C1]────►│ IN          VBAT   ├───┬──► To Battery +
                     │            │                    │   │
                   [C2]           │              PROG  ├───┼──[R_PROG]──► GND
                     │            │                    │   │
                    GND           │              THERM ├───┼──► Thermistor (NTC)
                                  │                    │   │
    System Load ◄────────────────►│ OUT          STAT1 ├───┼──► To RP2350 (Charging)
    (to TPS63001)                 │                    │   │
                                  │              STAT2 ├───┼──► To RP2350 (Charged/Fault)
                                  │                    │   │
                                  │                PG  ├───┼──► To RP2350 (Power Good)
                                  │                    │   │
                                  │          SEL/TIMER ├───┼──[R_SEL]──► GND or VCC
                                  │                    │   │
                                  │       PROG2/TE_N   ├───┼──► VCC (disable timer)
                                  │                    │   │
                                  │              CE_N  ├───┴──► GND (always enabled)
                                  │                    │
                                  │               VSS  ├──────► GND
                                  │                    │
                                  └────────────────────┘
```

#### Key Component Values

| Ref | Value | Purpose | Calculation |
|-----|---|---|---|
| R_PROG | 2kΩ | Sets charge current | I_CHG = 1000V / R_PROG = 500mA |
| R_SEL | 0Ω to GND | Selects USB input mode | USB 500mA mode |
| C_IN | 10µF | Input decoupling | X5R/X7R, 10V min |
| C_VBAT | 10µF | Battery decoupling | X5R/X7R, 10V min |
| C_OUT | 10µF | Output decoupling | X5R/X7R, 10V min |
| R_THERM | 10kΩ NTC | Battery temperature | Standard 10K NTC, B=3380 |

**Charge current selection:**
- R_PROG = 2kΩ → 500mA charge current (safe for 2000mAh, ~0.25C)
- Charge time: ~4-5 hours from empty
- Could use 1kΩ for 1A charging (~2.5 hours) if faster charging needed

#### Status Outputs

| STAT1 | STAT2 | Meaning |
|---|---|---|
| LOW | HIGH | Charging in progress |
| HIGH | LOW | Charge complete |
| HIGH | HIGH | No battery / Sleep / Disabled |
| LOW | LOW | Fault (over-temp, timer, etc.) |

| PG | Meaning |
|----|---|
| LOW | Input power good (USB connected) |
| HIGH | No input power (battery only) |

**Note:** Status pins are active-low open-drain. Use internal pullups on RP2350 GPIOs.

#### MCP73871 BOM

| Ref | Qty | Value | Package | Notes |
|-----|-----|---|---|---|
| U_CHG | 1 | MCP73871-2CCI/ML | QFN-20 (4×4mm) | Charge controller |
| C_IN | 1 | 10µF | 0805 | Input cap, X5R 10V |
| C_VBAT | 1 | 10µF | 0805 | Battery cap, X5R 10V |
| C_OUT | 1 | 10µF | 0805 | Output cap, X5R 10V |
| R_PROG | 1 | 2kΩ | 0603 | Charge current (500mA) |
| R_SEL | 1 | 0Ω | 0402 | USB 500mA mode |
| R_THERM | 1 | 10kΩ NTC | 0603 | Battery temp sensor |

**Subtotal:** ~$3.00

### LC709203F Fuel Gauge

*See [Engineer's Notebook](engineers-notebook/electrical-design-decisions.md#why-lc709203f) for selection rationale.*

#### LC709203F Circuit

```
                               LC709203F
                              ┌───────────────┐
                              │               │
    Battery + ────────────────┤ VCC      ALRM ├───► To RP2350 (optional alert)
                              │               │
    Battery - (GND) ──────────┤ VSS      SDA  ├───► I2C SDA (GPIO0)
                              │               │
    NTC Thermistor ───────────┤ THERMISTOR    │
         │                    │          SCL  ├───► I2C SCL (GPIO1)
        [10kΩ NTC]            │               │
         │                    │       TSENSE  ├───► GND (internal temp sense)
        GND                   │               │
                              └───────────────┘
```

#### LC709203F Configuration

| Parameter | Setting | Notes |
|---|---|---|
| I2C Address | 0x0B | Fixed |
| Battery Profile | APA = 0x0036 | For 2000mAh LiPo (adjust per datasheet) |
| Thermistor B | 0x0D34 | For 10K NTC, B=3380 |
| Change of Parameter | 0x0001 | 1-cell, 3.7V nominal |

**Firmware initialization:**
1. Write APA (Adjustment Pack Application) for battery capacity
2. Write thermistor B value
3. Set Change of Parameter for cell configuration
4. Read RSOC (Relative State of Charge) register for battery %

#### Key Registers

| Register | Address | Description |
|---|---|---|
| RSOC | 0x0D | Relative State of Charge (0-100%) |
| Cell Voltage | 0x09 | Battery voltage in mV |
| Cell Temp | 0x08 | Temperature (via thermistor) |
| Alarm RSOC | 0x13 | Low battery threshold |
| IC Version | 0x11 | Chip version (verify communication) |

#### LC709203F BOM

| Ref | Qty | Value | Package | Notes |
|-----|-----|---|---|---|
| U_FUEL | 1 | LC709203FQH-01TWG | WDFN-8 (2×2.5mm) | Fuel gauge |
| C_FUEL | 1 | 100nF | 0402 | Decoupling |
| R_NTC | 1 | 10kΩ NTC | 0603 | Shared with MCP73871 |

**Subtotal:** ~$2.50

**Note:** The 10K NTC thermistor is shared between MCP73871 and LC709203F. Both ICs read the same temperature sensor.

### Battery Connector

| Ref | Value | Notes |
|-----|---|---|
| J_BAT | JST-PH 2-pin | Standard LiPo connector |

**Polarity:** Red (+) on pin 1, Black (-) on pin 2. Match common LiPo battery wiring.

### Thermistor Placement

The NTC thermistor should be placed:
- Close to the battery (within 10mm if possible)
- On the main PCB near the battery pad/connector
- Away from heat sources (buck-boost inductor, SA818)

For pouch cells, the thermistor can be taped directly to the battery surface for better accuracy.

### Complete Battery Schematic

```
    USB VBUS (5V)                          ┌────────────────────────────────────────┐
         │                                 │                                        │
         │                                 │        MCP73871                        │
         │                                 │       ┌──────────┐                     │
         └─────────────────────────────────┼──────►│ IN       │                     │
                                           │       │          │                     │
                                           │   ┌───┤ OUT      ├──────────────────►  │
                                           │   │   │          │   To TPS63001       │
                                           │   │   │    VBAT  ├───┬──────────────►  │
                                           │   │   │          │   │  To TPS22919    │
              ┌────────────────────────────┼───┼───┤ STAT1    │   │                 │
              │                            │   │   │          │   │   ┌─────────┐   │
              │  ┌─────────────────────────┼───┼───┤ STAT2    │   └───┤  LiPo   │   │
              │  │                         │   │   │          │       │ 2000mAh │   │
              │  │  ┌──────────────────────┼───┼───┤ PG       │       └────┬────┘   │
              │  │  │                      │   │   │          │            │        │
              │  │  │                      │   │   │   THERM  ├────────────┼───┐    │
              │  │  │                      │   │   └──────────┘            │   │    │
              │  │  │                      │   │                           │   │    │
              ▼  ▼  ▼                      │   │                           │   │    │
           RP2350                          │   │   LC709203F               │   │    │
           GPIO                            │   │  ┌──────────┐             │   │    │
        (status)                           │   │  │          │             │   │    │
                                           │   └──┤ VCC      │◄────────────┘   │    │
              ┌────────────────────────────┼──────┤ SDA      ├──► I2C SDA      │    │
              │                            │      │          │                 │    │
              └────────────────────────────┼──────┤ SCL      ├──► I2C SCL      │    │
                                           │      │          │                 │    │
                                           │      │THERMISTOR├─────────────────┤    │
                                           │      └──────────┘                 │    │
                                           │                               ┌───┴───┐│
                                           │                               │10K NTC││
                                           │                               └───┬───┘│
                                           │                                   │    │
                                           └───────────────────────────────────┴────┘
                                                                              GND
```

### GPIO Usage for Battery Status

| GPIO | Function | Notes |
|---|---|---|
| TBD | STAT1 | Charging indicator (active low) |
| TBD | STAT2 | Charge complete (active low) |
| TBD | PG | Power good (active low) |
| 0 | I2C SDA | LC709203F fuel gauge (shared) |
| 1 | I2C SCL | LC709203F fuel gauge (shared) |

**Note:** STAT1/STAT2/PG are not connected to GPIOs. Charge state is inferred from LC709203F I2C readings. See [Engineer's Notebook](engineers-notebook/electrical-design-decisions.md#skipping-dedicated-status-gpios) for rationale.

### Battery Selection

**Requirements:**
- Capacity: 2000mAh (target runtime: 10+ hours idle)
- Chemistry: Li-Po (single cell, 3.7V nominal)
- Form factor: Pouch cell, fits badge footprint
- Connector: JST-PH 2-pin
- Protection: Built-in PCM (protection circuit module) preferred

**Recommended dimensions:** ~50mm × 35mm × 8mm (typical 2000mAh pouch)

**Common part numbers:**
- 503759 (50mm × 37mm × 5.9mm, 2000mAh)
- 103450 (10mm × 34mm × 50mm, 1800-2000mAh)

### Safety Considerations

1. **Over-discharge protection:** MCP73871 + battery PCM
2. **Over-charge protection:** MCP73871 (4.2V cutoff) + battery PCM
3. **Over-current protection:** Battery PCM
4. **Thermal protection:** MCP73871 thermal regulation + NTC monitoring
5. **Reverse polarity:** Add reverse protection diode or MOSFET (optional, increases cost)

**Recommendation:** Use batteries with built-in protection circuit (PCM). This is standard for quality LiPo cells and provides a second layer of safety.

---

## Audio Interface

### Overview

The audio interface uses a PCM5102A DAC for transmit and the RP2350 internal ADC for receive.

*See [Engineer's Notebook](engineers-notebook/electrical-design-decisions.md#why-pcm5102a--adc-not-wm8960-codec) for codec selection rationale.*

### Audio Signal Flow

```
    ┌─────────────────────────────────────────────────────────────────────────┐
    │                              MAIN BADGE                                 │
    │                                                                         │
    │   RP2350                              PCM5102A                          │
    │  ┌───────┐                           ┌─────────┐                        │
    │  │       │ GPIO(BCK)  ──────────────→│ BCK     │                        │
    │  │       │ GPIO(LRCK) ──────────────→│ LRCK    │                        │
    │  │       │ GPIO(DIN)  ──────────────→│ DIN     │    TX                  │
    │  │       │                           │         │   Filter    To SA818   │
    │  │       │                           │  VOUTL ─┼────────────→ MIC+/MIC- │
    │  │       │                           └─────────┘              (carrier) │
    │  │       │                                                              │
    │  │       │                              RX                   From SA818 │
    │  │       │ ADC GPIO ←──────────────── Filter ←───────────── SPK+/SPK-   │
    │  │       │                                                   (carrier)  │
    │  └───────┘                                                              │
    │                                                                         │
    └─────────────────────────────────────────────────────────────────────────┘
```

### Signal Levels

| Signal | Level | Notes |
|---|---|---|
| PCM5102A output | ~3V peak-to-peak | Full-scale DAC output |
| SA818 MIC input | ~10-50mV | Needs ~40dB attenuation |
| SA818 SPK output | ~300-500mV | AC coupled |
| RP2350 ADC input | 0-3.3V | Needs DC bias at 1.65V |

---

## TX Path: PCM5102A DAC Circuit

### PCM5102A Connections

```
                                        VCC (3.3V)
                                            │
                              ┌─────────────┼─────────────┐
                              │             │             │
                         C1 ══╪══ 10µF  C2 ══╪══ 100nF    │
                              │             │             │
    RP2350                    │             │             │
    ──────────────────────────┼─────────────┼─────────────┼──────────
                              │             │             │
    GPIO (BCK)  ──────────────┼──→ BCK      │             │
                              │             │             │
    GPIO (LRCK) ──────────────┼──→ LRCK     │             │
                              │      ┌──────┴──────┐      │
    GPIO (DIN)  ──────────────┼──→ DIN             │      │
                              │      │  PCM5102A   │      │
                              │      │             │      │
                         VCC ─┼──→ VCC    AVDD ←── ┼── VCC
                              │      │             │
                         VCC ─┼──→ DVDD            │
                              │      │             │
                        3.3V ─┼──→ CPVDD           │
                              │      │             │
                         GND ─┼──→ GND             │
                              │      │             │
                              │      │   VOUTL ─── ┼──→ To TX Filter
                              │      │             │
                              │      │   VOUTR ─── ┼──→ NC
                              │      │             │
    Config pins (directly):   │      │             │
                              │      │             │
                         GND ─┼──→ FMT             │      (I2S format)
                         GND ─┼──→ DEMP            │      (de-emphasis off)
                         GND ─┼──→ FLT             │      (normal filter)
                         VCC ─┼──→ XSMT            │      (soft mute off)
                              │      │             │
                              │      └─────────────┘
                              │
    ──────────────────────────┴──────────────────────────────────────
```

**Key points:**
- No I2C needed — configuration is via pin strapping
- FMT, DEMP, FLT tied to GND; XSMT tied to VCC
- Only using left channel output (VOUTL)

### TX Output Filter & Attenuator

The PCM5102A outputs ~3V peak-to-peak. The SA818 MIC input wants ~30mV. We need:
1. **Attenuation** (~100:1 = -40dB)
2. **Low-pass filtering** (remove DAC high-frequency artifacts)
3. **DC blocking** (only pass AC audio)

```
    PCM5102A                                                    To SA818
    VOUTL (~3Vpp)                                               MIC+ (~30mVpp)
       │                                                            │
       │      R1              R2              C4                    │
       ├────[47kΩ]────┬────[470Ω]────┬──────┤├──────────────────────┤
       │              │              │     100nF                    │
       │         C3 ══╪══ 10nF       │     (DC block)               │
       │              │              │                              │
       │             GND            GND                             │
       │                                                            │
      GND ──────────────────────────────────────────────────────── MIC-
```

**How it works:**

| Component | Function | Value |
|---|---|---|
| R1 + R2 | Voltage divider: 470/(47k+470) ≈ 1/100 | -40dB attenuation |
| C3 | Filter cap with R2, blocks high frequencies | fc ≈ 34kHz |
| C4 | DC blocking, only passes AC audio | 100nF |

**Output level:** 3Vpp × 0.01 = 30mVpp ✓

---

## RX Path: RP2350 ADC Circuit

### Anti-Alias Filter + Bias Network

The SA818 SPK output is ~300-500mV AC centered at 0V. The RP2350 ADC needs:
1. **DC blocking** (remove any offset from SA818)
2. **Anti-alias filtering** (block frequencies above ~7kHz)
3. **Bias** (shift signal to 1.65V center)

```
    From SA818                                              To RP2350
    SPK+ (~400mVpp)                                         ADC GPIO
       │                                                       │
       │     C5            R3             R4                   │
       ├────┤├────────────[4.7kΩ]───┬────[4.7kΩ]───────────────┤
       │   1µF                      │                          │
       │   (DC block)          C6 ══╪══ 4.7nF                  │
       │                            │  (anti-alias)            │
       │                           GND                         │
       │                                                       │
       │                      R5 [47kΩ]──── VCC (3.3V)         │
       │                            │                          │
       │                            ├──────────────────────────┘
       │                            │  (bias = 1.65V)
       │                      R6 [47kΩ]
       │                            │
       │                           GND
       │
      SPK- ─────────────────────────────────────────────────── GND
```

**How it works:**

| Component | Function | Value |
|---|---|---|
| C5 | DC block — removes SA818 offset, passes audio | 1µF |
| R3 + R4 + C6 | Anti-alias filter, fc ≈ 7.2kHz | Blocks frequencies that cause aliasing |
| R5 + R6 | Bias divider, creates 1.65V center point | Shifts AC into ADC range |

**Anti-alias cutoff:** fc = 1/(2π × 4.7k × 4.7nF) ≈ 7.2kHz

This is above the SSTV maximum (~2.3kHz) but below the Nyquist limit for a ~20kHz sample rate.

---

## Complete Audio Schematic

```
    ┌─────────────────────────────────────────────────────────────────────────┐
    │                                                                         │
    │   RP2350                              PCM5102A                          │
    │  ┌───────┐                           ┌─────────┐                        │
    │  │       │ GPIO(BCK)  ──────────────→│ BCK     │                        │
    │  │       │ GPIO(LRCK) ──────────────→│ LRCK    │                        │
    │  │       │ GPIO(DIN)  ──────────────→│ DIN     │                        │
    │  │       │                           │         │                        │
    │  │       │                           │  VOUTL ─┼──┐                     │
    │  │       │                           └─────────┘  │                     │
    │  │       │                                        │                     │
    │  │       │          ┌─────────────────────────────┘                     │
    │  │       │          │                                                   │
    │  │       │          │    R1          R2         C4                      │
    │  │       │          └──[47kΩ]──┬──[470Ω]──┬────┤├─────────────→ MIC+    │
    │  │       │                     │          │   100nF            (to J1)  │
    │  │       │                C3 ══╪══       GND                            │
    │  │       │                    10nF                                      │
    │  │       │                     │                                        │
    │  │       │                    GND                              MIC- ←GND│
    │  │       │                                                     (to J1)  │
    │  │       │                                                              │
    │  │       │                                                              │
    │  │       │          ┌───────────────────────────────────────── SPK+     │
    │  │       │          │                                         (from J1) │
    │  │       │          │    C5         R3          R4                      │
    │  │       │          └───┤├───────[4.7kΩ]──┬──[4.7kΩ]──┬────────────┐    │
    │  │       │             1µF                │           │            │    │
    │  │       │                           C6 ══╪══        ─┼─ Bias      │    │
    │  │       │                              4.7nF        ┌┴┐           │    │
    │  │       │                                │     R5   │ │ 47kΩ      │    │
    │  │       │                               GND   VCC───┤ │           │    │
    │  │       │                                           └┬┘           │    │
    │  │       │                                            ├────────────┘    │
    │  │       │                                           ┌┴┐                │
    │  │       │ ADC GPIO ←────────────────────────────────┤ │ R6 47kΩ        │
    │  │       │                                           └┬┘                │
    │  └───────┘                                           GND                │
    │                                                                         │
    │                                                       SPK- ← GND        │
    │                                                       (from J1)         │
    └─────────────────────────────────────────────────────────────────────────┘
```

---

## Audio BOM

| Ref | Value | Package | Assembly | Notes |
|-----|---|---|---|---|
| U_DAC | PCM5102A | TSSOP-20 | Fab/hot air | I2S DAC |
| C1 | 10µF | 0805 | Fab/hot air | DVDD decoupling |
| C2 | 100nF | 0603 | Fab/hot air | AVDD decoupling |
| R1 | 47kΩ | 0603 | User | TX attenuator |
| R2 | 470Ω | 0603 | User | TX attenuator |
| C3 | 10nF | 0603 | User | TX filter |
| C4 | 100nF | 0603 | User | TX DC block |
| C5 | 1µF | 0603 | User | RX DC block |
| R3 | 4.7kΩ | 0603 | User | RX filter |
| R4 | 4.7kΩ | 0603 | User | RX filter |
| C6 | 4.7nF | 0603 | User | RX anti-alias |
| R5 | 47kΩ | 0603 | User | RX bias |
| R6 | 47kΩ | 0603 | User | RX bias |

**Total cost:** ~$2.05 (PCM5102A ~$1.75 + passives ~$0.30)

**User-solderable:** All 0603 resistors and capacitors (R1-R6, C3-C6).

**Fab/hot air:** PCM5102A (TSSOP-20) and its decoupling caps (C1, C2).

---

## SA818 Carrier Board Design

### Overview

The carrier board is a full-width PCB that overlays the top portion of the main badge. It contains the SA818 module, SMA connector, and antenna — keeping **all RF circuitry on the carrier** and completely off the main badge.

*See [Engineer's Notebook](engineers-notebook/electrical-design-decisions.md#why-a-separate-carrier-board) for carrier board rationale.*

### Physical Arrangement

```
    FRONT VIEW (worn on chest, looking at badge)

    ┌────────────────────────────────────────┐ ─┬─ Top edge
    │┌──────────────────────────────────────┐│  │  (both boards flush)
    ││           CARRIER BOARD              ││  │
    ││  (SA818, SMA, antenna - visible)     ││  │  ~25mm carrier height
    │└──────────────────────────────────────┘│  │
    │                                        │ ─┴─
    │                                        │
    │           MAIN BADGE                   │
    │    (display, buttons, etc - visible)   │
    │                                        │
    │                                        │
    └────────────────────────────────────────┘

    SIDE VIEW (cross-section)

                        antenna
                           ↑
                      ┌────┴───┐
         CARRIER  ════╪════════╪════  ← In FRONT of main badge
                      │        │
         MAIN     ════╪════════╪════  ← Behind carrier
                      └────────┘
                    headers connect
                    (pointing backward)
```

### SA818 Pinout Reference

| Pin | Name | Function |
|-----|---|---|
| 1 | VCC | Power 3.5-5.5V |
| 2 | GND | Ground |
| 3 | MIC+ | Audio input + |
| 4 | MIC- | Audio input - |
| 5 | SPK+ | Audio output + |
| 6 | SPK- | Audio output - |
| 7 | PTT | Push-to-talk (active low) |
| 8 | PD | Power down (active low) |
| 9 | HL | High/Low power select |
| 10 | SQ | Squelch detect output |
| 11 | TXD | UART TX (module → MCU) |
| 12 | RXD | UART RX (MCU → module) |
| 13-15 | NC | Not connected |
| 16 | GND | Ground |

### Carrier Board Layout

```
                              ← 120mm (full badge width) →

    ┌──────────────────────────────────────────────────────────────────┐
    │○ ○ ○                                                        ○ ○ ○│ ─┬─
    │J3 (GND)                                                  J4 (GND)│  │
    │mechanical           ┌──────┐                              mech   │  │
    │                     │ SMA  │ ← right-angle connector             │  │
    │                     │  ↑   │   antenna points UP                 │  │
    │                     └──┬───┘   (tilt awat slightly at assembly)  │ ~25mm
    │                        │                                         │  │
    │  ┌─────────────────────┴───────────────┐                         │  │
    │  │            50Ω trace                │                         │  │
    │  │   ┌───────────────────────────┐     │    C1 ▪ 100nF           │  │
    │  │   │                           │     │    C2 ▪ 10µF            │  │
    │  │   │       SA818-V/U           │     │                         │  │
    │  │   │      (horizontal)         │     │    R_ID ▪ (band select) │  │
    │  │   │                           │     │                         │  │
    │  │   └───────────────────────────┘     │                         │  │
    │  │            GND via fence            │                         │  │
    │  └─────────────────────────────────────┘                         │  │
    │                                                                  │ ─┴─
    │  ○ ○ ○ ○ ○ ○ ○ ○                            ○ ○ ○ ○ ○ ○ ○ ○      │
    │  J1 (1x8)                                    J2 (1x8)            │
    │  signal header                              signal header        │
    └──────────────────────────────────────────────────────────────────┘
                  │                                      │
                  ▼                                      ▼
    ════════════════════════════════════════════════════════════════════
                         MAIN BADGE (top edge, behind carrier)

    Component side faces FORWARD (visible when worn)
    Headers point BACKWARD into main badge sockets
```

### Connector Placement (for mechanical stability)

| Element | Position from left edge | Purpose |
|---|---|---|
| J3 (top-left) | 5-13mm | 1x3 mechanical, GND (KiCad: J16/J21) |
| J1 (bottom-left) | 10-30mm | 1x8 signal (power + audio) (KiCad: J14/J18) |
| SMA connector | ~55-65mm | Center-right (KiCad: J13/J19) |
| J2 (bottom-right) | 90-110mm | 1x8 signal (control + data) (KiCad: J15/J20) |
| J4 (top-right) | 107-115mm | 1x3 mechanical, GND (KiCad: J17/J22) |

The 4-point mounting (J1, J2 at bottom + J3, J4 at top corners) prevents wobble and keeps the carrier securely attached.

### Carrier Header Pinouts

**J1 (Left, 1x8) — Power and Audio:**
*(KiCad: J14 on VHF carrier, J18 on UHF carrier; main board socket J7)*

| Pin | Signal | Notes |
|-----|---|---|
| 1 | VCC | From TPS22919 on main board |
| 2 | GND | Ground |
| 3 | GND | Ground |
| 4 | MIC+ | TX audio input to SA818 |
| 5 | GND | Ground |
| 6 | SPK+ | RX audio output from SA818 |
| 7 | GND | Ground |
| 8 | GND | Ground |

**J2 (Right, 1x8) — Control and Data:**
*(KiCad: J15 on VHF carrier, J20 on UHF carrier; main board socket J8)*

| Pin | Signal | Notes |
|-----|---|---|
| 1 | RXD (UART) | UART RX from SA818 TXD (main badge net: SA818_RX) |
| 2 | TXD (UART) | UART TX to SA818 RXD (main badge net: SA818_TX) |
| 3 | PTT | Push-to-talk (active low) |
| 4 | PD | Power down (active low; also enables TPS22919 load switch) |
| 5 | HL | High/low power select |
| 6 | SQ | Squelch detect |
| 7 | ID | Band detect (GND=VHF, float=UHF) |
| 8 | GND | Ground |

> **Locked pinout note:** these pin assignments reflect the **current state of the main badge schematic and PCB** (PCB routing complete, design locked). The earlier carrier schematics use a different pin order — see [carrier-rewiring-checklist.md](engineers-notebook/carrier-rewiring-checklist.md) for the rewiring work needed to bring the carriers in line.

**J3, J4 (Top corners, 1x3 each) — Mechanical:**

All pins connected to GND for RF shielding and mechanical stability.

### Band Auto-Detection

Instead of a DIP switch, the carrier includes a band ID resistor:

| Module | ID Pin State | Implementation |
|---|---|---|
| SA818-V (VHF) | LOW | 0Ω resistor to GND on carrier |
| SA818-U (UHF) | Float | No resistor populated (DNP) |
| No module | Float | MCU pulldown, detect via UART timeout |

Firmware reads ID pin on startup and configures frequency limits accordingly.

### RF Section (On Carrier)

All RF design is contained on the carrier board:

**50Ω Trace:**
- SA818 ANT pin to SMA connector
- Keep as short as possible (~15-20mm)
- 0.36mm (14 mil) width for 50Ω on standard 4-layer stackup
- Or calculate for 2-layer if carrier is simpler

**Ground Via Stitching:**
```
    SA818 ANT
         │
    ○  ○ ┃ ○  ○      ← Via fence on both sides
         ┃
    ○  ○ ┃ ○  ○        0.3mm drill, 1mm spacing
         ┃
    ○  ○ ┃ ○  ○
         ┃
      ┌──┴──┐
      │ SMA │
      └─────┘
```

**SMA Connector:**
- Right-angle, PCB mount
- Position at top edge, center-right
- Antenna points UP when badge is worn
- Slight backward tilt (~10-15°) achieved during assembly by not fully seating top header pins

### Included Antenna

Each carrier ships with a matched stubby antenna:

| Carrier | Antenna | Approximate Length |
|---|---|---|
| SA818-V (VHF) | 2m stubby whip | 15-20cm (6-8") |
| SA818-U (UHF) | 70cm stubby whip | 8-10cm (3-4") |

User receives a complete, band-matched RF assembly. No antenna selection confusion.

### Carrier BOM

| Ref | Value | Package | Notes |
|-----|---|---|---|
| U1 | SA818-V or SA818-U | Module | 2mm pitch castellated |
| J_SMA | SMA right-angle | PCB mount | Female, 50Ω |
| C1 | 100nF | 0402/0603 | Decoupling |
| C2 | 10µF | 0603/0805 | Bulk |
| R_ID | 0Ω | 0402 | To GND (VHF); DNP on UHF (float = UHF) |
| J1 | 1x8 male header | 0.1" pitch | Through-hole, pointing backward |
| J2 | 1x8 male header | 0.1" pitch | Through-hole, pointing backward |
| J3 | 1x3 male header | 0.1" pitch | Through-hole, all pins GND (KiCad: J16/J21) |
| J4 | 1x3 male header | 0.1" pitch | Through-hole, all pins GND (KiCad: J17/J22) |
| ANT | Stubby antenna | SMA male | VHF or UHF matched |

**Per-carrier cost:** ~$15-20 (SA818 ~$10, SMA ~$1-2, antenna ~$3-5, PCB + passives ~$2)

### Mechanical Stack

```
Side view (assembled):

                     antenna (~15-20cm VHF, ~8-10cm UHF)
                         ↑
                    ┌────┴────┐
                    │   SMA   │
    CARRIER   ══════╪═════════╪══════  ← ~1.6mm PCB + ~5mm SA818 height
                    │         │
              ┌─────┴───┐ ┌───┴─────┐
              │ headers │ │ headers │   ← ~8-11mm pin length
              └─────┬───┘ └───┬─────┘
    MAIN      ══════╪═════════╪══════  ← Main badge PCB
                    sockets on
                    front of main

    Gap between boards: ~5-8mm (header pin length minus insertion depth)
    Total stack: ~12-15mm thick at carrier area
```

---

## Main Board — Carrier Interface

### No RF on Main Board

With all RF contained on the carrier, the main badge PCB:
- Has **NO 50Ω traces**
- Has **NO RF via stitching requirements**
- Has **NO SMA connector**
- Only needs 4 female header sockets at the top edge

This dramatically simplifies the main board design. A 2-layer PCB may be feasible depending on RP2350 routing density.

### Socket Placement (Main Board Top Edge)

```
    MAIN BADGE - TOP EDGE (front side, looking at badge)

     ┌─────────────────────────────────────────────────────────────┐
     │                                                             │
     │  □ □ □                                               □ □ □  │ ← J3, J4 (J11, J12)
     │  (J3)                                                 (J4)  │   1x3, GND
     │                                                             │
    ...                                                           ...
     │                                                             │
     │                                                             │
     │  □ □ □ □ □ □ □ □                           □ □ □ □ □ □ □ □  │ ← J1, J2 (J7, J8)
     │  (J1 socket)                                 (J2 socket)    │   1x8, sig
     │                                                             │
     │                                                             │
     │               ┌─────────────────────────┐                   │
     │               │                         │                   │
     │               │        DISPLAY          │                   │
     │               │                         │                   │
     │               └─────────────────────────┘                   │
     │                                                             │
     │                    (rest of badge...)                       │
     │                                                             │
     └─────────────────────────────────────────────────────────────┘
```

### Main Board Socket Connections

**J1 Socket (1x8, KiCad: J7) — Power and Audio:**

| Pin | Signal | Connects To |
|-----|---|---|
| 1 | VCC | TPS22919 output |
| 2 | GND | Ground plane |
| 3 | MIC+ | TX audio filter output |
| 4 | GND | Ground plane |
| 5 | SPK+ | RX audio filter input |
| 6 | GND | Ground plane |
| 7 | GND | Ground plane |
| 8 | GND | Ground plane |

**J2 Socket (1x8, KiCad: J8) — Control and Data:**

| Pin | Signal | Connects To |
|-----|---|---|
| 1 | PTT | RP2350 GPIO (SA818_PTT) |
| 2 | PD | RP2350 GPIO (SA818_PD / TPS22919 EN) |
| 3 | HL | RP2350 GPIO (SA818_HL) |
| 4 | SQ | RP2350 GPIO (SA818_SQ) |
| 5 | TXD | RP2350 UART TX (SA818_TX) |
| 6 | RXD | RP2350 UART RX (SA818_RX) |
| 7 | ID | RP2350 GPIO (SA818_ID, with internal pulldown) |
| 8 | GND | Ground plane |

**J3, J4 Sockets (1x3 each) — Mechanical:**

All pins connected to GND for RF shielding and mechanical stability.

*See [Engineer's Notebook](engineers-notebook/electrical-design-decisions.md#main-board-pcb-layers-2-vs-4) for PCB layer discussion.*

---

## Display Interface

### Overview

The display shows SSTV images, menus, and status information.

**Specifications:**
- **Module:** 2.4" ILI9341-based TFT LCD breakout
- **Resolution:** 320×240 pixels (landscape orientation)
- **Interface:** SPI (up to 62.5 MHz)
- **Backlight:** PWM dimming via GPIO + MOSFET
- **Touch:** None (D-pad navigation instead)
- **SD Card:** Standalone SD socket (J10), shared SPI bus with display

*See [Engineer's Notebook](engineers-notebook/electrical-design-decisions.md#why-320x240) for resolution selection rationale.*

### ILI9341 Module Pinout

| Module Pin | Signal | RP2350 Connection | Notes |
|---|---|---|---|
| VCC | Power | 3.3V rail | Module has onboard regulator if 5V tolerant |
| GND | Ground | GND | |
| CS | Chip Select | GPIO | directly |
| RESET | Reset | GPIO | Software reset capability |
| DC/RS | Data/Command | GPIO | Directly driven |
| SDI/MOSI | SPI Data In | SPI TX GPIO | Directly driven |
| SCK | SPI Clock | SPI SCK GPIO | |
| LED/BLK | Backlight | GPIO via MOSFET | PWM dimming |
| SDO/MISO | SPI Data Out | SPI RX GPIO | Optional, for read-back |
| SD_CS | SD Card Select | GPIO | For standalone SD socket (J10) |

### SPI Configuration

| Parameter | Value |
|---|---|
| SPI Mode | Mode 0 (CPOL=0, CPHA=0) |
| Max Clock | 62.5 MHz |
| Data Width | 8-bit or 16-bit |
| Full Frame | 320×240×16bpp = 153,600 bytes |
| Frame Time | ~20ms at 62.5 MHz → ~50 FPS capable |

For static SSTV images, even 10 FPS is more than sufficient.

### SD Card (Shared SPI Bus)

The standalone SD card socket (J10) shares the SPI bus with the display. This means:
- Only one device active at a time (display OR SD card)
- Must manage separate CS pins for each device
- May need to adjust SPI clock when switching (SD cards are pickier)

**This is fine for SSTV** because operations are naturally sequential:
- Load image from SD → then display it
- Receive SSTV → decode to RAM → display → optionally save to SD

No workflow requires simultaneous display update and SD access.

### Backlight PWM Circuit

Most modules wire the backlight LED directly to VCC. To add PWM dimming, we switch the LED ground path:

```
    RP2350                                          Display Module
    ┌───────┐                                       LED/BLK pin
    │       │                                            │
    │  GPIO ├────┐                                       │
    │  (BL) │    │                                       │
    │       │   [1kΩ] R_BL                               │
    └───────┘    │                                       │
                 └──┤ G                                  │
                    │      ┌─────────────────────────────┘
                    │ 2N7002
                    ├ S    │ D
                    │      │
                   GND    GND

    PWM HIGH → MOSFET ON → Backlight ON
    PWM LOW  → MOSFET OFF → Backlight OFF
    PWM duty cycle controls brightness
```

**PWM Frequency:** 1-10 kHz (higher = no visible flicker)

**Note:** Some modules have the LED anode on the BLK pin (switch high side). Check your specific module. The 2N7002 circuit above assumes LED cathode on BLK pin (more common).

### Complete Display Schematic

```
    RP2350                                              ILI9341 Module
    ┌───────┐                                          ┌─────────────┐
    │       │                                          │             │
    │  3.3V ├──────────────────────────────────────────┤ VCC         │
    │       │                                          │             │
    │   GND ├──────────────────────────────────────────┤ GND         │
    │       │                                          │             │
    │  GPIO ├──────────────────────────────────────────┤ CS          │
    │(DISP_CS)                                         │             │
    │       │                                          │             │
    │  GPIO ├──────────────────────────────────────────┤ RESET       │
    │(DISP_RST)                                        │             │
    │       │                                          │             │
    │  GPIO ├──────────────────────────────────────────┤ DC          │
    │(DISP_DC)                                         │             │
    │       │                                          │             │
    │  SPI  ├──────────────────────────────────────────┤ SDI (MOSI)  │
    │  TX   │                                          │             │
    │       │                                          │             │
    │  SPI  ├──────────────────────────────────────────┤ SCK         │
    │  SCK  │                                          │             │
    │       │                                          │             │
    │  SPI  ├──────────────────────────────────────────┤ SDO (MISO)  │
    │  RX   │                                          │  (optional) │
    │       │                                          │             │
    │  GPIO ├──────────────────────────────────────────┤ SD_CS       │
    │(SD_CS)│                                          │  (SD card)  │
    │       │                                          │             │
    │  GPIO ├────┐                                     │             │
    │(DISP_BL)   │                                     │             │
    │       │   [1kΩ]                                  │             │
    └───────┘    │                                     │             │
                 └──┤ G                                │             │
                    │      ┌───────────────────────────┤ LED (BLK)   │
               2N7002│ D ←─┘                           │             │
                    ├ S                                │             │
                    │                                  │             │
                   GND                                 └─────────────┘
```

### GPIO Summary for Display

| Function | GPIO | Notes |
|---|---|---|
| SPI SCK | GPIO6 | Shared SPI clock (SPI0 F0) |
| SPI TX (MOSI) | GPIO7 | Shared SPI data out (SPI0 F0) |
| SPI RX (MISO) | GPIO4 | Shared SPI data in (SPI0 F0) |
| DISP_CS | GPIO5 | Display chip select |
| DISP_DC | GPIO19 | Data/Command select |
| DISP_RST | GPIO20 | Display reset |
| DISP_BL | GPIO29 | Backlight PWM |
| SD_CS | GPIO26 | SD card chip select |

**Total: 6-7 dedicated GPIOs** (plus SPI bus which may be shared with other peripherals)

### Display BOM

| Ref | Value | Package | Assembly | Notes |
|-----|---|---|---|---|
| U_DISP | ILI9341 2.4" module | Breakout | User | 320×240, SPI, w/ SD slot |
| Q_BL | 2N7002 | SOT-23 | Fab | Backlight MOSFET |
| R_BL | 1kΩ | 0603 | User | Gate resistor |

**Cost:** ~$8-12 for module + ~$0.10 for MOSFET/resistor

### Orientation and Mounting

- **Orientation:** Landscape (320 wide × 240 tall)
- **Mounting:** Module breakout board, likely with pin headers or direct solder
- **Position:** Center of main badge, below the carrier board area

The display is the main visual element — position it prominently for the "retro TV" aesthetic.

---

## Camera Interface

### Overview

The camera captures images for SSTV transmission and provides live viewfinder preview.

**Specifications:**
- **Sensor:** OV2640 2MP CMOS
- **Module:** Pre-assembled breakout with 2.54mm 2×9 pin header (user-solderable)
- **Interface:** Parallel DVP (8-bit) + SCCB (I2C) for control
- **Resolution:** QVGA (320×240) for SSTV, up to UXGA (1600×1200) if needed
- **Output:** RGB565 or YUV422 (for viewfinder), JPEG (for storage)

*See [Engineer's Notebook](engineers-notebook/electrical-design-decisions.md#why-parallel-dvp-not-spi) for interface selection rationale.*

### OV2640 DVP Pinout

| Pin | Signal | Direction | RP2350 Connection | Notes |
|-----|---|---|---|---|
| 3V3 | Power | — | 3.3V rail | ~50mA active |
| GND | Ground | — | GND | |
| SIOC | I2C Clock | ← | Shared I2C SCL | SCCB (I2C-compatible) |
| SIOD | I2C Data | ↔ | Shared I2C SDA | SCCB (I2C-compatible) |
| VSYNC | Frame sync | → | GPIO | High during vertical blank |
| HREF | Line valid | → | GPIO | High when pixel data valid |
| PCLK | Pixel clock | → | GPIO | Clock from camera |
| XCLK | Master clock | ← | GPIO (PWM) | ~20MHz clock to camera |
| D0-D7 | Pixel data | → | 8 GPIOs | 8-bit parallel data |
| RESET | Reset | ← | GPIO | Active low (or tie to 3.3V via 10K) |
| PWDN | Power down | ← | GPIO | Active high (or tie to GND) |

### DVP Timing

```
    VSYNC ────┐                                              ┌────
              │             Frame N                          │
              └──────────────────────────────────────────────┘

    HREF      ┌──┐  ┌──┐  ┌──┐  ┌──┐  ┌──┐  ┌──┐  ┌──┐  ┌──┐
           ───┘  └──┘  └──┘  └──┘  └──┘  └──┘  └──┘  └──┘  └───
              Line0  Line1 Line2  ...                    Line239

    PCLK      ┌┐┌┐┌┐┌┐┌┐┌┐┌┐┌┐┌┐┌┐┌┐┌┐┌┐┌┐┌┐┌┐┌┐┌┐┌┐┌┐┌┐┌┐┌┐┌┐
           ───┘└┘└┘└┘└┘└┘└┘└┘└┘└┘└┘└┘└┘└┘└┘└┘└┘└┘└┘└┘└┘└┘└┘└┘└───
              Each rising edge = one pixel byte

    D[7:0]    ═══╦═══╦═══╦═══╦═══╦═══╦═══╦═══╦═══╦═══╦═══╦═══╦═══
                 P0   P1   P2   P3   ...                    P639
              (RGB565 = 2 bytes per pixel, so 640 bytes per line for 320 pixels)
```

### PIO Implementation

The RP2350's PIO (Programmable I/O) is ideal for DVP capture:

1. **PIO program** watches HREF and PCLK
2. **On PCLK rising edge** (when HREF high), shift in D0-D7
3. **DMA** transfers data directly to RAM buffer
4. **CPU is free** to process previous frame / update display

This enables zero-copy capture with minimal CPU involvement.

### XCLK Generation

The camera needs a master clock input (XCLK), typically 20-24 MHz.

**Option A: PWM output**
- Configure RP2350 PWM for 20MHz, 50% duty cycle
- Simple, uses one GPIO

**Option B: PIO clock output**
- PIO can generate precise clocks
- More flexible frequency control

**Recommendation:** PWM is simpler and sufficient.

```
    RP2350 PWM GPIO ─────────────────────────────→ OV2640 XCLK

    PWM config:
    - System clock: 150MHz (typical)
    - Divider: 7.5 → 20MHz output
    - Duty: 50%
```

### Camera Module Selection

For user-solderable assembly, use an OV2640 module with 2.54mm pin headers.

**Recommended:** Generic "OV2640 DVP module" with 2×9 pin header (Conn_02x09_Socket)

```
    ┌───────────────────────────────┐
    │    ┌─────────────────────┐    │
    │    │     ░░░░░░░░░░░     │    │  ← Lens
    │    │     ░ OV2640  ░     │    │
    │    │     ░ Sensor  ░     │    │
    │    │     ░░░░░░░░░░░     │    │
    │    └─────────────────────┘    │
    │                               │
    │  ┌───────────────────────┐    │
    │  │ Supporting circuitry  │    │  ← Voltage reg, crystal, etc.
    │  └───────────────────────┘    │
    │                               │
    │  ○ ○ ○ ○ ○ ○ ○ ○ ○           │  ← 2×9 (2.54mm) through-hole pins
    │  ○ ○ ○ ○ ○ ○ ○ ○ ○           │     (user-solderable)
    └───────────────────────────────┘

    Typical size: ~25mm × 25mm
```

**J4 Camera Connector Pin Mapping (2×9, Conn_02x09_Socket):**

| Pin | Signal | Pin | Signal |
|-----|---|-----|---|
| 1 | GND | 2 | +3.3V |
| 3 | I2C_SCL | 4 | CAM_VSYNC |
| 5 | I2C_SDA | 6 | CAM_HREF |
| 7 | CAM_D0 | 8 | RST (10k pull-up to +3.3V) |
| 9 | CAM_D2 | 10 | CAM_D1 |
| 11 | CAM_D4 | 12 | CAM_D3 |
| 13 | CAM_D6 | 14 | CAM_D5 |
| 15 | CAM_PCLK | 16 | CAM_D7 |
| 17 | PWDN (10k pull-down to GND) | 18 | NC |

**Search terms:** "OV2640 camera module DVP" or "OV2640 module for STM32/ESP32"

**Price:** ~$5-8

### Camera Schematic

```
    RP2350B                                            OV2640 Module
    ┌───────┐                                         ┌─────────────┐
    │       │                                         │             │
    │  3.3V ├─────────────────────────────────────────┤ 3V3         │
    │       │                                         │             │
    │   GND ├─────────────────────────────────────────┤ GND         │
    │       │                                         │             │
    │  I2C  ├─────────────────────────────────────────┤ SIOC (SCL)  │
    │  SCL  │              (shared bus)               │             │
    │       │                                         │             │
    │  I2C  ├─────────────────────────────────────────┤ SIOD (SDA)  │
    │  SDA  │              (shared bus)               │             │
    │       │                                         │             │
    │  GPIO ├──────────────────────────(PWM 20MHz)────┤ XCLK        │
    │(CAM_XCLK)                                       │             │
    │       │                                         │             │
    │  GPIO ├─────────────────────────────────────────┤ PCLK        │
    │(CAM_PCLK)                                       │             │
    │       │                                         │             │
    │  GPIO ├─────────────────────────────────────────┤ VSYNC       │
    │(CAM_VSYNC)                                      │             │
    │       │                                         │             │
    │  GPIO ├─────────────────────────────────────────┤ HREF        │
    │(CAM_HREF)                                       │             │
    │       │                                         │             │
    │  GPIO ├─────────────────────────────────────────┤ D0          │
    │(CAM_D0)│                                        │             │
    │   :   │                                         │     :       │
    │   :   │            (8 data lines)               │     :       │
    │  GPIO ├─────────────────────────────────────────┤ D7          │
    │(CAM_D7)│                                        │             │
    │       │                                         │             │
    │  GPIO ├────────┬────────────────────────────────┤ RESET       │
    │(CAM_RST)       │                                │             │
    │       │   [10kΩ] (pullup to 3.3V)               │             │
    │       │        │                                │             │
    │       │       3.3V                              │             │
    │       │                                         │             │
    │  GPIO ├────────┬────────────────────────────────┤ PWDN        │
    │(CAM_PWDN)      │                                │             │
    │       │   [10kΩ] (pulldown to GND)              │             │
    │       │        │                                │             │
    └───────┘       GND                               └─────────────┘

    Note: RESET and PWDN can be directly driven or tied via resistors
    if GPIO control isn't needed. Driving them allows power-saving sleep.
```

### GPIO Summary for Camera

| Function | GPIO | Notes |
|---|---|---|
| I2C SCL | GPIO1 | SCCB clock (shared with SAO, fuel gauge) |
| I2C SDA | GPIO0 | SCCB data (shared with SAO, fuel gauge) |
| CAM_XCLK | GPIO19 | PWM output, ~20MHz |
| CAM_PCLK | GPIO16 | Pixel clock input (PIO) |
| CAM_VSYNC | GPIO17 | Frame sync input |
| CAM_HREF | GPIO18 | Line valid input |
| CAM_D0-D7 | GPIO8-15 | 8× parallel data (PIO), consecutive for PIO |
| CAM_RST | — | Tied HIGH via 10kΩ pullup (not GPIO controlled) |
| CAM_PWDN | — | Tied LOW via 10kΩ pulldown (not GPIO controlled) |

**Dedicated GPIOs: 10-12** (depending on whether RST/PWDN are GPIO-controlled)

### Viewfinder Performance

| Parameter | Value |
|---|---|
| Resolution | QVGA (320×240) |
| Color format | RGB565 |
| Frame size | 153,600 bytes |
| DVP capture rate | 30+ FPS (PIO + DMA) |
| Display update rate | ~50 FPS max (SPI limited) |
| **Effective viewfinder** | **15-20 FPS** (capture + display) |

15-20 FPS is smooth enough for a viewfinder experience.

### Camera BOM

| Ref | Value | Package | Assembly | Notes |
|-----|---|---|---|---|
| U_CAM | OV2640 DVP module | Breakout (2×9 header) | User | 2.54mm 2×9 pin header, ~$5-8 |
| R_CAM_RST | 10kΩ | 0603 | Fab | Reset pullup (optional if GPIO controlled) |
| R_CAM_PWDN | 10kΩ | 0603 | Fab | PWDN pulldown (optional if GPIO controlled) |

**Cost:** ~$5-8 for module + ~$0.02 for resistors

### Camera Mounting

Position the camera for the "take a picture" use case:
- **Front-facing** (same side as display) — selfie/badge-to-badge photos
- Near top of badge, possibly integrated into the "TV antenna" aesthetic
- Ensure lens isn't blocked by carrier board or antenna

---

## MCU: RP2350B

*See [Engineer's Notebook](engineers-notebook/electrical-design-decisions.md#why-rp2350b-qfn-80) for MCU selection rationale.*

### RP2350B Specifications

| Parameter | Value |
|---|---|
| Package | QFN-80 (10×10mm) |
| GPIOs | 48 (GPIO0-GPIO47) |
| CPU | Dual ARM Cortex-M33 @ 150MHz |
| SRAM | 520KB |
| Flash | External SPI (16MB in BOM) |
| PIO | 3× PIO blocks, 12 state machines |
| ADC | 8-channel 12-bit (GPIO40-47) |
| PWM | 12 channels |

### GPIO Pin Assignment

47 of 48 GPIOs are allocated (GPIO47 spare). Camera RST/PWDN are tied with resistors to free pins for SAO. GPIOs are organized by physical side of the QFN-80 package to minimize trace crossings. See `docs/engineers-notebook/gpio-optimization.md` for rationale.

**Top Side — Audio + LED (pins 61-64, face carrier headers):**

| GPIO | Function | Notes |
|---|---|---|
| 0 | LED_DATA | WS2812B chain (PIO), routes to ear base |
| 1 | I2S_LRCK | Word select to PCM5102A (PIO) |
| 2 | I2S_DIN | Data to PCM5102A (PIO) |
| 3 | I2S_BCK | Bit clock to PCM5102A (PIO) |

**Left Side — Display SPI (pins 1-4, face display center):**

| GPIO | Function | Notes |
|---|---|---|
| 4 | SPI0_RX | MISO from SD |
| 5 | DISP_CS | Display chip select (directly driven) |
| 6 | SPI0_SCK | Clock |
| 7 | SPI0_TX | MOSI to display and SD |

**Left Side — Camera DVP (pins 6-20, face display/camera):**

| GPIO | Function | Notes |
|---|---|---|
| 8 | CAM_D0 | Parallel data bit 0 |
| 9 | CAM_D1 | Parallel data bit 1 |
| 10 | CAM_D2 | Parallel data bit 2 |
| 11 | CAM_D3 | Parallel data bit 3 |
| 12 | CAM_D4 | Parallel data bit 4 |
| 13 | CAM_D5 | Parallel data bit 5 |
| 14 | CAM_D6 | Parallel data bit 6 |
| 15 | CAM_D7 | Parallel data bit 7 |
| 16 | CAM_PCLK | Pixel clock input (PIO) |
| 17 | CAM_VSYNC | Frame sync |
| 18 | CAM_HREF | Line valid |
| 19 | DISP_DC | Data/Command select (toggles every SPI txn) |
| 20 | DISP_RST | Display reset (infrequent toggle) |

Note: CAM_RST tied HIGH via 10kΩ, CAM_PWDN tied LOW via 10kΩ (not GPIO controlled).

**Bottom Side — Controls + SAO1 (pins 21-28, face bottom edge):**

| GPIO | Function | Notes |
|---|---|---|
| 21 | DPAD_UP | Active low, internal pullup |
| 22 | DPAD_DOWN | Active low, internal pullup |
| 23 | DPAD_LEFT | Active low, internal pullup |
| 24 | DPAD_RIGHT | Active low, internal pullup |
| 25 | DPAD_CENTER | Active low, internal pullup |
| 26 | SD_CS | SD card chip select |
| 27 | SAO1_GPIO1 | SAO connector 1, pin 5 (left edge) |
| 28 | SAO1_GPIO2 | SAO connector 1, pin 6 (left edge) |

**Bottom Side — Display Misc + PWR LED (pins 37-40):**

| GPIO | Function | Notes |
|---|---|---|
| 29 | DISP_BL | Backlight PWM (via 2N7002) |
| 30 | PWR_R | PWR LED red channel (PWM) |
| 31 | PWR_G | PWR LED green channel (PWM) |
| 32 | PWR_B | PWR LED blue channel (PWM) |

**Right Side — SA818 Interface (pins 42-48, face carrier headers):**

| GPIO | Function | Notes |
|---|---|---|
| 33 | SA818_PTT | Push-to-talk (active low) |
| 34 | SA818_PD | Power down / TPS22919 enable |
| 35 | SA818_HL | High/Low power select |
| 36 | SA818_TX | UART1_TX → SA818 RXD |
| 37 | SA818_RX | UART1_RX ← SA818 TXD |
| 38 | SA818_SQ | Squelch detect input |
| 39 | SA818_ID | Band ID from carrier |

**Right Side — ADC + SAO2 + I2C (pins 49-57):**

| GPIO | Function | Notes |
|---|---|---|
| 40 | RX_AUDIO | ADC input from SA818 SPK (ADC0) |
| 41 | SAO2_GPIO1 | SAO connector 2, pin 5 (right edge) |
| 42 | SAO2_GPIO2 | SAO connector 2, pin 6 (right edge) |
| 43 | AIRPLANE | Airplane mode slide switch |
| 44 | I2C0_SDA | Camera SCCB, LC709203, SAO1, SAO2 |
| 45 | I2C0_SCL | Camera SCCB, LC709203, SAO1, SAO2 |
| 46 | (spare) | Unallocated |
| 47 | (spare) | Unallocated |

**Note:** RP2350B ADC channels are on GPIO40-47 (not GPIO26-29 like RP2040). SAO I2C shared on GPIO44/45. VCC=3.3V, GND from power rails.

### GPIO Assignment Summary

```
GPIO 0-1:   I2C (shared bus)
GPIO 2-4:   SPI (display + SD)
GPIO 5-7:   Display control (CS, DC, RST)
GPIO 8-19:  Camera DVP (D0-D7, PCLK, VSYNC, HREF, XCLK)
GPIO 20-21: SAO1 GPIOs
GPIO 22-23: Display BL + SD_CS
GPIO 24-25: Audio I2S (BCK, LRCK)
GPIO 26:    DPAD_RIGHT (moved here to free GPIO40 for ADC)
GPIO 27-28: SAO2 GPIOs
GPIO 29:    Audio I2S (DIN)
GPIO 30-36: SA818 (UART + control)
GPIO 37-39: User controls (DPAD UP/DOWN/LEFT)
GPIO 40:    RX Audio ADC (ADC0)
GPIO 41:    User controls (DPAD CENTER)
GPIO 42:    Spare (unallocated)
GPIO 43:    User controls (AIRPLANE)
GPIO 44-46: PWR LED (RGB)
GPIO 47:    LED_DATA (WS2812B blinky)

Total: 47/48 GPIOs allocated (1 spare)
```

### I2C Bus (Shared)

The I2C bus on GPIO0 (SDA) and GPIO1 (SCL) is shared by multiple devices:

| Device | I2C Address | Function |
|---|---|---|
| OV2640 | 0x30 (SCCB) | Camera configuration |
| LC709203F | 0x0B | Battery fuel gauge |
| SAO1 | (varies) | Shitty Add-On 1 |
| SAO2 | (varies) | Shitty Add-On 2 |

**Pullup Resistors:**

```
    3.3V ─────┬─────────────┬─────────────────────────────────►
              │             │
             [R]           [R]
            4.7kΩ         4.7kΩ
              │             │
    GPIO0 ────┴── SDA ──────┼──► OV2640, LC709203F, SAO1, SAO2
                            │
    GPIO1 ──────── SCL ─────┴──► OV2640, LC709203F, SAO1, SAO2
```

| Ref | Value | Package | Notes |
|-----|---|---|---|
| R_SDA | 4.7kΩ | 0603 | I2C SDA pullup |
| R_SCL | 4.7kΩ | 0603 | I2C SCL pullup |

**Notes:**
- 4.7kΩ is suitable for 400kHz I2C (Fast Mode)
- Camera SCCB is compatible with I2C
- If SAO devices have their own pullups, total resistance may be lower (acceptable)
- For 1MHz I2C (Fast Mode Plus), use 2.2kΩ pullups instead

### PIO Allocation

| PIO | State Machines | Function |
|-----|---|---|
| PIO0 | SM0-SM1 | Camera DVP capture (D0-D7 + PCLK) |
| PIO1 | SM0 | WS2812B LED driver |
| PIO2 | (available) | Future use |

### PWM Usage

| GPIO | PWM Slice | Function |
|---|---|---|
| 20 | — | (DISP_RST, not PWM) |
| 29 | PWM6B | DISP_BL (1-10kHz) |
| 30 | PWM7A | PWR_R |
| 31 | PWM7B | PWR_G |
| 32 | PWM8A | PWR_B |

### Crystal Oscillator

*See [Engineer's Notebook](engineers-notebook/electrical-design-decisions.md#why-a-crystal-is-required) for crystal requirement rationale and part recommendations.*

**Crystal Circuit:**

```
                    RP2350B
                   ┌────────────────┐
                   │                │
                   │    XIN  ●──────┼────┬────[Y1 12MHz]────┬────●  XOUT
                   │                │    │                  │
                   │                │   [C1]               [C2]
                   │                │   15pF               15pF
                   │                │    │                  │
                   │                │   GND                GND
                   └────────────────┘
```

**Component Selection:**

| Ref | Value | Package | Notes |
|-----|---|---|---|
| Y1 | 12MHz | 3215 (3.2×1.5mm) | ±20ppm, 10pF load, fundamental |
| C1, C2 | 15pF | 0402 | Load capacitors (2 × CL - C_stray = 2×10 - 5 = 15pF) |

**Layout notes:**
- Keep crystal close to XIN/XOUT pins (<5mm trace length)
- Ground plane under crystal
- No high-speed signals routed near crystal
- Load caps close to crystal, directly to ground

### External Flash

The RP2350 boots from external QSPI flash. This stores firmware and can also store user data (images, settings).

**Flash Circuit:**

```
                    RP2350B                          W25Q128
                   ┌────────────────┐               ┌─────────────┐
                   │                │               │             │
                   │  QSPI_SS  ●────┼───────────────┤ /CS         │
                   │                │               │             │
                   │  QSPI_SCK ●────┼───────────────┤ CLK         │
                   │                │               │             │
                   │  QSPI_SD0 ●────┼───────────────┤ DI (IO0)    │
                   │                │               │             │
                   │  QSPI_SD1 ●────┼───────────────┤ DO (IO1)    │
                   │                │               │             │
                   │  QSPI_SD2 ●────┼───────────────┤ /WP (IO2)   │
                   │                │               │             │
                   │  QSPI_SD3 ●────┼───────────────┤ /HOLD (IO3) │
                   │                │               │             │
                   └────────────────┘               │        VCC  ├───► 3.3V
                                                    │             │
                                                    │        GND  ├───► GND
                                                    └─────────────┘
                                                          │
                                                         [C] 100nF
                                                          │
                                                         GND
```

**Component Selection:**

| Ref | Value | Package | Notes |
|-----|---|---|---|
| U_FLASH | W25Q128JVSIQ | SOIC-8 | 16MB, QSPI, 133MHz |
| C_FLASH | 100nF | 0402 | Decoupling, close to VCC |

*See [Engineer's Notebook](engineers-notebook/electrical-design-decisions.md#why-16mb-flash) for flash size rationale and alternatives.*

**Layout notes:**
- Keep traces short (<25mm total)
- Match trace lengths for high-speed operation
- 100nF decoupling cap close to flash VCC
- Ground plane under flash

### BOOTSEL Button

The BOOTSEL button allows entering the RP2350 USB bootloader (UF2 mass storage mode) for firmware updates.

**How it works:**
1. Hold BOOTSEL button
2. Plug in USB (or press reset while holding BOOTSEL)
3. RP2350 appears as USB mass storage device
4. Drag-and-drop .uf2 firmware file
5. Device automatically reboots with new firmware

**Circuit:**

```
    RP2350B
   ┌────────────────┐
   │                │
   │  QSPI_SS  ●────┼────┬────────► To Flash /CS
   │                │    │
   └────────────────┘    │
                         │
                    ┌────┴────┐
                    │         │
                    │ BOOTSEL │  ← Small tactile switch
                    │  (SW)   │
                    │         │
                    └────┬────┘
                         │
                        GND
```

**Notes:**
- QSPI_SS is a dedicated pin (not GPIO) — doesn't affect GPIO count
- When button pressed, QSPI_SS is pulled LOW
- At boot, if QSPI_SS is LOW, RP2350 enters USB bootloader
- Small switch is fine — only pressed during firmware updates
- Place on back of PCB or recessed to prevent accidental activation

**Component:**

| Ref | Value | Package | Assembly | Notes |
|-----|---|---|---|---|
| SW_BOOT | Tactile 3×4mm or 4×4mm | SMD | Fab | BOOTSEL, recessed placement |

**Alternatives to physical button:**
- Use `picotool reboot -f` command (requires working firmware)
- Use SWD via Tag-Connect (always works)
- Double-tap reset (if firmware implements it)

For a production badge, the physical button provides a reliable recovery method if firmware is corrupted.

### RP2350 Internal Voltage Regulator

The RP2350 contains an internal switching regulator that converts the 3.3V input to 1.1V for the CPU core. This regulator requires an external inductor.

**Power Architecture:**
```
+3.3V ──► VREG_VIN ──► [Internal Switcher] ──► VREG_LX ──┬──► L2 (3.3µH) ──┬──► DVDD (1.1V core)
                                                         │                  │
                                                         └──────────────────┘
                                                                            │
                                                                           ┴ C_DVDD (1µF)
                                                                            │
                                                                          GND
```

**Power Pin Connections:**

| Pin | Function | Connection |
|-----|---|---|
| VREG_VIN | Regulator input (3.3V) | +3V3 via 10µF decoupling |
| VREG_AVDD | Regulator analog supply | +3V3 via 100nF decoupling |
| VREG_LX | Switching node output | To inductor L2 |
| VREG_FB | Feedback (internal) | No external connection required |
| VREG_PGND | Regulator power ground | GND |
| DVDD | Core voltage output (1.1V) | From inductor L2, 1µF to GND |
| IOVDD | I/O power (×6 internal) | +3V3 via 100nF decoupling |
| USB_OTP_VDD | USB/OTP power | +3V3 via 100nF decoupling |
| ADC_AVDD | ADC analog power | +3V3 via 100nF decoupling |
| QSPI_IOVDD | Flash I/O power | +3V3 via 100nF decoupling |

**Inductor Selection:**
- Value: 3.3µH (recommended by Raspberry Pi)
- DCR: <100mΩ
- Saturation current: >500mA
- Package: 3×3mm or similar
- Example: Murata LQH3NPN3R3MM0, Bourns SRN3015-3R3M

### MCU BOM

| Ref | Qty | Value | Package | Assembly | Notes |
|-----|-----|---|---|---|---|
| U_MCU | 1 | RP2350B | QFN-80 (10×10mm) | Fab | Dual Cortex-M33, 48 GPIO |
| L2 | 1 | 3.3µH | 3×3mm | Fab | Internal regulator inductor |
| Y1 | 1 | 12MHz | 3215 | Fab | ±20ppm, CL=10pF |
| C_Y1, C_Y2 | 2 | 15pF | 0402 | Fab | Crystal load caps |
| U_FLASH | 1 | W25Q128JVSIQ | SOIC-8 | Fab | 16MB QSPI flash |
| C_FLASH | 1 | 100nF | 0402 | Fab | Flash decoupling |
| C_MCU | 6 | 100nF | 0402 | Fab | MCU decoupling (one per VDD) |
| C_MCU_BULK | 2 | 10µF | 0603 | Fab | MCU bulk caps |
| C_DVDD | 1 | 1µF | 0402 | Fab | DVDD decoupling |
| SW_BOOT | 1 | Tactile 3×4mm | SMD | Fab | BOOTSEL for UF2 bootloader |

**Subtotal:** ~$3.85

---

## Debug Interface (Tag-Connect)

### Overview

Programming and debugging uses a Tag-Connect pogo-pin interface instead of a traditional header. This provides a professional appearance with no visible connector while still allowing easy programming and debugging.

### Tag-Connect TC2030-CTX-NL

| Parameter | Value |
|---|---|
| Connector | TC2030-CTX-NL (6-pin, no legs) |
| Footprint | 0.34" × 0.10" (8.6mm × 2.5mm) |
| Interface | ARM SWD |
| Mating cable | TC2030-CTX-NL-ARM (Digi-Key) |
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

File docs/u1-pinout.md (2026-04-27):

# U1 Pinout — RP2350B (QFN-80)

Complete pin-to-net mapping for U1 as routed on the main badge PCB.
GPIOs are organized by physical side to minimize trace crossings.
See `docs/engineers-notebook/gpio-optimization.md` for rationale.

**Note:** The pin numbers in this document come from the KiCad symbol, which uses a different numbering scheme than the RP2350B datasheet. This is cosmetic — KiCad's symbol and footprint are internally consistent, so all nets route to the correct physical pads. Just don't cross-reference these pin numbers directly against the datasheet.
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

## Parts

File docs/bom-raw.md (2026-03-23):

# DEFCON SSTV Badge — Raw BOM for Ordering

**Version:** 1.0
**Date:** 2026-02-15
**For:** One complete badge (main board + one carrier)

---

## ICs

| Part | Value/Type | Qty |
|---|---|-----|
| RP2350B | QFN-80 MCU | 1 |
| W25Q128JVS | 16MB QSPI Flash | 1 |
| TPS63001DRCR | Buck-Boost Regulator | 1 |
| TPS22919DCKT | Load Switch | 1 |
| MCP73871 | Battery Charger | 1 |
| LC709203FQH-01TWG | Fuel Gauge | 1 |
| PCM5102A | I2S DAC | 1 |
| USBLC6-2SC6 | USB ESD Protection | 1 |
| SA818V *or* SA818U | VHF/UHF Transceiver | 1 |

## Discrete Semiconductors

| Part | Value/Type | Qty |
|---|---|-----|
| 2N7002 | N-MOSFET SOT-23 | 1 |
| PESD5V0S1BL | TVS Diode | 1 |
| APFA3010 | RGB LED (common-anode) | 1 |
| WS2812B (5050) | Addressable LED | 10 |
| WS2812B-2020 | Addressable LED | 16 |

## Capacitors

| Value | Qty | Notes |
|---|-----|---|
| 15pF | 2 | Crystal load caps |
| 4.7nF | 1 | RX anti-alias filter |
| 10nF | 1 | TX low-pass filter |
| 100nF | 38 | Decoupling (MCU, LEDs, ICs, carrier) |
| 1µF | 2 | DVDD, RX DC block |
| 2.2µF | 2 | DAC charge pump |
| 10µF | 14 | Bulk caps throughout |
| 100µF | 1 | Load switch output |

## Resistors

| Value | Qty | Notes |
|---|-----|---|
| 0 | 1 | Band ID (VHF carrier only) |
| 100 | 2 | PWR LED G/B |
| 220 | 1 | PWR LED R |
| 470 | 1 | TX attenuator |
| 1k | 1 | Backlight gate pulldown |
| 2k | 1 | Charge current (PROG1) |
| 4.7k | 4 | I2C pullups, RX filter |
| 5.1k | 2 | USB CC resistors |
| 10k | 3 | Pullups/pulldowns |
| 15k | 1 | Pre-charge/term (PROG3) |
| 47k | 3 | TX attenuator, RX bias |

## Thermistor

| Value | Qty | Notes |
|---|-----|---|
| NTC 10k (B=3380) | 1 | Battery temperature |

## Inductors

| Value | Qty | Notes |
|---|-----|---|
| 1µH | 1 | TPS63001 buck-boost |
| 3.3µH | 1 | RP2350 internal regulator |

## Crystal

| Value | Qty | Notes |
|---|-----|---|
| 12MHz | 1 | 3215 package, 15pF load |

## Connectors

| Type | Qty | Notes |
|---|-----|---|
| USB4105-GF-A | 1 | USB-C connector |
| JST-PH 2-pin | 1 | Battery connector |
| 2x3 header (2.54mm) | 2 | SAO connectors |
| 1x8 socket (2.54mm) | 2 | Carrier signal (main board) |
| 1x3 socket (2.54mm) | 2 | Carrier mechanical (main board) |
| 1x8 pin header (2.54mm) | 2 | Carrier signal (carrier board) |
| 1x3 pin header (2.54mm) | 2 | Carrier mechanical (carrier board) |
| SMA right-angle female | 1 | Antenna connector (carrier) |
| Micro SD card socket | 1 | Storage |
| Tag-Connect TC2030-NL | — | Pads only, no component |

## Switches

| Type | Qty | Notes |
|---|-----|---|
| Tactile 6x6mm | 5 | D-pad (center doubles as photo capture) |
| Slide SPDT | 1 | Airplane mode |
| Tactile 3x4mm SMD | 1 | BOOTSEL |

## Modules

| Type | Qty | Notes |
|---|-----|---|
| ILI9341 2.4" TFT | 1 | 320x240 SPI display |
| OV2640 DVP | 1 | Camera module |
| Stubby antenna | 1 | VHF or UHF matched |

## Battery

| Type | Qty | Notes |
|---|-----|---|
| LiPo 2000mAh | 1 | 3.7V, JST-PH connector |

---

## Quick Counts

| Category | Total |
|---|---|
| ICs | 9 |
| Capacitors | 63 |
| Resistors | 19 |
| LEDs | 27 |
| Connectors | 13 |
| Switches | 7 |
| Modules | 3 |

---

*Note: For UHF carrier, omit the 0Ω resistor (R18 DNP).*

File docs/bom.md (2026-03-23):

# DEFCON SSTV Badge — Bill of Materials

**Version:** 3.2
**Last Updated:** 2026-03-22
**Source:** KiCad schematic export, verified against `docs/electrical-design.md`

This is the consolidated BOM for the DEFCON SSTV badge. Components are organized by subsystem and assembly method.

---

## Quick Summary

| Category | Est. Cost | Notes |
|---|---|---|
| Power System | ~$4.00 | TPS63001 buck-boost, TPS22919 load switch |
| USB-C Interface | ~$1.20 | Connector + ESD protection |
| Battery System | ~$11.50 | MCP73871, LC709203F, 2000mAh LiPo |
| Audio | ~$2.10 | PCM5102A DAC + filter passives |
| Display | ~$10.00 | ILI9341 module + backlight circuit |
| Camera | ~$6.00 | OV2640 DVP module + resistors |
| User Controls | ~$1.30 | Switches, PWR LED, resistors |
| Blinky LEDs | ~$2.28 | 10× WS2812B-5050 + 16× WS2812B-2020 + bypass caps |
| MCU + Support | ~$3.90 | RP2350B, crystal, flash, regulator inductor, passives |
| Connectors | ~$2.00 | SAO, carrier sockets, SD card, debug |
| **Main Badge Total** | **~$64** | Without carrier |
| SA818 Carrier | ~$17.00 | SA818, SMA, antenna, headers |
| **Complete Kit** | **~$81** | Main + one carrier |

*PCB fabrication adds ~$3-5/board at quantity.*

---

## Assembly Legend

| Code | Meaning |
|---|---|
| **Fab** | Factory assembled (requires reflow/hot air) |
| **User** | User-solderable at conference (through-hole or large pads) |
| **Module** | Pre-assembled breakout, user installs |

---

## Power System

### Buck-Boost Regulator (TPS63001)

| Ref | Qty | Value | Package | Assembly | Notes |
|-----|-----|---|---|---|---|
| U5 | 1 | TPS63001DRCR | QFN-10 (3×3mm) | Fab | Fixed 3.3V output |
| L1 | 1 | 1µH | 3×3mm | Fab | Coilcraft XAL3030-102 or equiv |
| C_IN, C_OUT1 | 2 | 10µF | 0805 | Fab | X5R/X7R, 10V, input/output |

*Note: PS/SYNC resistor intentionally omitted — forced PWM mode provides cleaner audio with minimal ripple. Power save mode would reduce idle current but risks noise coupling into SSTV audio path.*

**Subtotal:** ~$2.50

### Load Switch (TPS22919)

| Ref | Qty | Value | Package | Assembly | Notes |
|-----|-----|---|---|---|---|
| U6 | 1 | TPS22919DCKT | SOT-23-5 | Fab | SA818 power control |
| C17 | 1 | 100µF | 1206 | Fab | Output bulk capacitor |
| C18 | 1 | 10µF | 0603 | Fab | Output bypass |

**Subtotal:** ~$0.80

---

## USB-C Interface

| Ref | Qty | Value | Package | Assembly | Notes |
|-----|-----|---|---|---|---|
| J2 | 1 | USB4105-GF-A | SMT+TH hybrid | Fab | GCT USB-C with D+/D- (USB 2.0) |
| U3 | 1 | USBLC6-2SC6 | SOT-23-6 | Fab | D+/D- ESD protection |
| D_VBUS1 | 1 | TVS (PESD5V0S1BL) | SOD-323 | Fab | VBUS surge protection |
| R_CC1, R_CC2 | 2 | 5.1kΩ | 0402 | Fab | USB sink identification (to GND) |
| C_USB1 | 1 | 10µF | 0603 | Fab | VBUS decoupling |

**Subtotal:** ~$1.20

---

## Battery System

### Charger (MCP73871)

| Ref | Qty | Value | Package | Assembly | Notes |
|-----|-----|---|---|---|---|
| U4 | 1 | MCP73871-2CCI/ML | QFN-20 (4×4mm) | Fab | Li-Po charge controller |
| R3 | 1 | 2kΩ | 0603 | Fab | PROG1: Charge current = 1000/R = 500mA |
| R4 | 1 | 15kΩ | 0603 | Fab | PROG3: Pre-charge/termination = ~67mA |
| C8, C10, C11 | 3 | 10µF | 0805 | Fab | Input/battery/output caps, X5R 10V |

**Subtotal:** ~$3.00

### Fuel Gauge (LC709203F)

| Ref | Qty | Value | Package | Assembly | Notes |
|-----|-----|---|---|---|---|
| U7 | 1 | LC709203FQH-01TWG | WDFN-8 (2×2.5mm) | Fab | Battery SoC monitor, I2C |
| C16 | 1 | 100nF | 0402 | Fab | Decoupling |

**Subtotal:** ~$2.50

### Shared Thermistor

| Ref | Qty | Value | Package | Assembly | Notes |
|-----|-----|---|---|---|---|
| TH1 | 1 | NTC 10k | 0603 | Fab | B=3380, shared by MCP73871 (THERM) + LC709203F (TSENSE) |

*Place near battery for accurate temperature reading.*

### Battery + Connector

| Ref | Qty | Value | Package | Assembly | Notes |
|-----|-----|---|---|---|---|
| BAT1 | 1 | 2000mAh LiPo | Pouch ~50×35×8mm | User | JST-PH connector, 3.7V, with PCM |
| J_BAT | 1 | JST-PH 2-pin | Through-hole | User | Battery connector |

**Subtotal:** ~$6.50

---

## Audio Interface

| Ref | Qty | Value | Package | Assembly | Notes |
|-----|-----|---|---|---|---|
| U8 | 1 | PCM5102A | TSSOP-20 | Fab | I2S stereo DAC for TX |
| C20 | 1 | 10µF | 0805 | Fab | DVDD decoupling |
| C19 | 1 | 100nF | 0603 | Fab | AVDD decoupling |
| C21, C22 | 2 | 2.2µF | 0603 | Fab | Charge pump caps (CAPP, CAPM) |
| R5 | 1 | 47kΩ | 0603 | User | TX attenuator (high) |
| R6 | 1 | 470Ω | 0603 | User | TX attenuator (low) |
| C24 | 1 | 10nF | 0603 | User | TX low-pass filter |
| C25 | 1 | 100nF | 0603 | User | TX DC blocking |
| C26 | 1 | 1µF | 0603 | User | RX DC blocking |
| R7, R8 | 2 | 4.7kΩ | 0603 | User | RX anti-alias filter |
| C27 | 1 | 4.7nF | 0603 | User | RX anti-alias filter |
| R9 | 1 | 47kΩ | 0603 | User | RX bias to 3.3V |
| R10 | 1 | 47kΩ | 0603 | User | RX bias to GND |

**Subtotal:** ~$2.10

---

## Display Interface

| Ref | Qty | Value | Package | Assembly | Notes |
|-----|-----|---|---|---|---|
| J3 | 1 | ILI9341 2.4" module | Breakout | Module | 320×240 SPI display |
| Q1 | 1 | 2N7002 | SOT-23 | Fab | Backlight control MOSFET |
| R11 | 1 | 1kΩ | 0603 | User | Gate pull-down |

**Subtotal:** ~$10.00

---

## Camera Interface

| Ref | Qty | Value | Package | Assembly | Notes |
|-----|-----|---|---|---|---|
| J4 | 1 | OV2640 DVP module | Breakout | Module | 2×9 socket (PinSocket_2x09_P2.54mm_Vertical), parallel DVP |
| R12, R13 | 2 | 10kΩ | 0603 | Fab | RESET pullup / PWDN pulldown |

**Subtotal:** ~$6.00

---

## User Controls

### Switches

| Ref | Qty | Value | Package | Assembly | Notes |
|-----|-----|---|---|---|---|
| SW1-SW5 | 5 | Tactile 6×6mm | TH | User | D-pad (up/down/left/right/center); center doubles as photo capture |
| SW7 | 1 | Slide SPDT | TH | User | Airplane mode toggle |

### PWR Status LED (Traditional RGB)

| Ref | Qty | Value | Package | Assembly | Notes |
|-----|-----|---|---|---|---|
| D1 | 1 | APFA3010 | PLCC-4 (3.0×1.0mm) | Fab | Kingbright RGB LED, **common-anode** |
| R14 | 1 | 220Ω | 0603 | Fab | Red cathode current limit |
| R15, R16 | 2 | 100Ω | 0603 | Fab | Green/Blue cathode current limit |

**Note:** Common-anode LED — anode connects to +3.3V, cathodes through resistors to GPIOs. Firmware uses inverted logic: GPIO LOW = LED on.

**Subtotal:** ~$1.30

---

## Blinky LED Matrix

| Ref | Qty | Value | Package | Assembly | Notes |
|-----|-----|---|---|---|---|
| D2–D11 | 10 | WS2812B | 5050 (5.0×5.0mm) | Fab | Rabbit ear antennas (5 per ear) |
| D12–D27 | 16 | WS2812B-2020 | 2020 (2.0×2.0mm) | Fab | Display border (3×5×3×5 layout) |
| C28–C53 | 26 | 100nF | 0402 | Fab | Bypass caps (one per LED) |

**Subtotal:** ~$2.28
*(10× WS2812B-5050 @ ~$0.08 = $0.80, 16× WS2812B-2020 @ ~$0.06 = $0.96, 26× caps @ ~$0.02 = $0.52)*

---

## MCU and Support

| Ref | Qty | Value | Package | Assembly | Notes |
|-----|-----|---|---|---|---|
| U1 | 1 | RP2350B | QFN-80 (10×10mm) | Fab | 48 GPIO variant required |
| L2 | 1 | 3.3µH | 3×3mm | Fab | Internal regulator inductor (VREG_LX to DVDD) |
| Y1 | 1 | 12MHz | 3215 | Fab | ±20ppm, CL=10pF (required for USB) |
| C_Y1, C_Y2 | 2 | 15pF | 0402 | Fab | Crystal load caps |
| U2 | 1 | W25Q128JVS | SOIC-8 | Fab | 16MB QSPI flash |
| C9 | 1 | 100nF | 0402 | Fab | Flash decoupling |
| C3-C7 | 5 | 100nF | 0402 | Fab | MCU VDD decoupling |
| C2 | 1 | 10µF | 0603 | Fab | MCU bulk cap |
| C1 | 1 | 1µF | 0402 | Fab | DVDD (core voltage) decoupling |
| SW_BOOT1 | 1 | Tactile 3×4mm | SMD | Fab | BOOTSEL for UF2 bootloader |
| R1, R2 | 2 | 4.7kΩ | 0603 | Fab | I2C SDA/SCL pullups (to +3V3) |
| R17 | 1 | 10kΩ | 0603 | Fab | RUN pin pullup |

**Subtotal:** ~$3.90

*Notes:*
- *Crystal is required — RP2350 internal oscillator is too inaccurate for USB (needs ±0.25%, ROSC is ±2-5%).*
- *L2 is required for the RP2350's internal switching regulator (converts 3.3V → 1.1V core voltage).*
- *I2C pullups MUST connect to +3V3 (IOVDD level), NOT to DVDD (1.1V core).*

---

## Connectors (Main Board)

| Ref | Qty | Value | Package | Assembly | Notes |
|-----|-----|---|---|---|---|
| J1 | 1 | JST-PH 2-pin | Through-hole | User | Battery connector |
| J5 | 1 | 2×3 header | 2.54mm | User | SAO connector 1 |
| J6 | 1 | 2×3 header | 2.54mm | User | SAO connector 2 |
| J7, J8 | 2 | 1×8 socket | 2.54mm | User | Carrier signal headers |
| J9 | 1 | TC2030-CTX-NL | Pads only | Fab | Tag-Connect SWD (no component, excluded from BOM) |
| J10 | 1 | Micro SD Card | SMD | Fab | Standalone SD card socket |
| J11, J12 | 2 | 1×3 socket | 2.54mm | User | Carrier mechanical (GND) |

**Subtotal:** ~$2.50

*Note: Debug interface is Tag-Connect pogo pads only — no installed header. Developer needs TC2030-CTX-NL cable (~$40 one-time) for programming/debug.*

---

## SA818 Carrier Boards

*Assembled separately — one per frequency band. Two variants with identical PCB, different module and resistor population.*

### SA818-V Carrier (VHF, 134-174 MHz)

| Ref | Qty | Value | Package | Assembly | Notes |
|-----|-----|---|---|---|---|
| U9 | 1 | SA818V | Module (2mm pitch) | Fab | VHF transceiver |
| J13 | 1 | SMA right-angle | PCB mount | Fab | Female, 50Ω, to ANT |
| J14 | 1 | 1×8 male header | 2.54mm | User | Power/Audio |
| J15 | 1 | 1×8 male header | 2.54mm | User | Control/Data |
| J16 | 1 | 1×3 male header | 2.54mm | User | Mechanical (GND) |
| J17 | 1 | 1×3 male header | 2.54mm | User | Mechanical (GND) |
| C54 | 1 | 100nF | 0402 | Fab | Decoupling |
| C55 | 1 | 10µF | 0603 | Fab | Bulk capacitor |
| R18 | 1 | 0Ω | 0402 | Fab | Band ID → GND (VHF) |
| ANT | 1 | VHF stubby antenna | SMA male | Included | 144 MHz band |

### SA818-U Carrier (UHF, 400-480 MHz)

| Ref | Qty | Value | Package | Assembly | Notes |
|-----|-----|---|---|---|---|
| U10 | 1 | SA818U | Module (2mm pitch) | Fab | UHF transceiver |
| J19 | 1 | SMA right-angle | PCB mount | Fab | Female, 50Ω, to ANT |
| J18 | 1 | 1×8 male header | 2.54mm | User | Power/Audio |
| J20 | 1 | 1×8 male header | 2.54mm | User | Control/Data |
| J21 | 1 | 1×3 male header | 2.54mm | User | Mechanical (GND) |
| J22 | 1 | 1×3 male header | 2.54mm | User | Mechanical (GND) |
| C56 | 1 | 100nF | 0402 | Fab | Decoupling |
| C57 | 1 | 10µF | 0603 | Fab | Bulk capacitor |
| — | — | DNP | — | — | R18 equivalent - Band ID floating (UHF) |
| ANT | 1 | UHF stubby antenna | SMA male | Included | 430 MHz band |

### Carrier Header Pinouts

**J14 (Power/Audio):**
| Pin | Signal | Description |
|-----|---|---|
| 1 | SA818_VCC | Power from main board load switch |
| 2 | GND | Ground |
| 3 | MIC+ | TX audio input |
| 4 | GND | Ground |
| 5 | SPK+ | RX audio output |
| 6 | GND | Ground |
| 7 | GND | Ground |
| 8 | GND | Ground |

**J15 (Control/Data):**
| Pin | Signal | Description |
|-----|---|---|
| 1 | SA818_PTT | Push-to-talk (active low) |
| 2 | SA818_PD | Power down (active low) |
| 3 | SA818_HL | High/Low power select |
| 4 | SA818_SQ | Squelch output |
| 5 | SA818_TX | UART TX (MCU→SA818) |
| 6 | SA818_RX | UART RX (SA818→MCU) |
| 7 | SA818_ID | Band ID (GND=VHF, float=UHF) |
| 8 | GND | Ground |

**J16, J17 (Mechanical):** All pins → GND (extra ground connections for RF)

**Subtotal (per carrier):** ~$17.00
*(SA818 ~$10, SMA ~$2, antenna ~$4, PCB+parts ~$1)*

---

## Passive Component Totals

### Resistors

| Value | Qty | Package | Use |
|---|-----|---|-----|
| 0Ω | 1 | 0402 | VHF carrier band ID (R18) |
| 100Ω | 2 | 0603 | PWR LED G/B (R15, R16) |
| 220Ω | 1 | 0603 | PWR LED R (R14) |
| 470Ω | 1 | 0603 | TX attenuator (R6) |
| 1kΩ | 1 | 0603 | Backlight gate (R11) |
| 2kΩ | 1 | 0603 | Charge current PROG1 (R3) |
| 4.7kΩ | 4 | 0603 | RX filter (R7, R8), I2C pullups (R1, R2) |
| 5.1kΩ | 2 | 0402 | USB CC (R_CC1, R_CC2) |
| 10kΩ | 3 | 0603 | Camera RST/PWDN (R12, R13), RUN pullup (R17) |
| 15kΩ | 1 | 0603 | Pre-charge/termination PROG3 (R4) |
| 47kΩ | 3 | 0603 | TX attenuator (R5), RX bias (R9, R10) |

### Thermistor

| Value | Qty | Package | Use |
|---|-----|---|-----|
| NTC 10k | 1 | 0603 | Temperature sensing, B=3380 (TH1) |

### Capacitors

| Value | Qty | Package | Use |
|---|-----|---|-----|
| 15pF | 2 | 0402 | Crystal load (C_Y1, C_Y2) |
| 4.7nF | 1 | 0603 | RX anti-alias (C27) |
| 10nF | 1 | 0603 | TX filter (C24) |
| 100nF | 38 | 0402/0603 | Decoupling: MCU (C3-C7, C9), LEDs (C28-C53), ICs, carriers (C54, C56) |
| 1µF | 2 | 0402/0603 | DVDD (C1), RX DC block (C26) |
| 2.2µF | 2 | 0603 | PCM5102A charge pump (C21, C22) |
| 10µF | 14 | 0603/0805 | Bulk caps throughout, carriers (C55, C57) |
| 100µF | 1 | 1206 | Load switch bulk (C17) |

### Inductors

| Value | Qty | Package | Use |
|---|-----|---|-----|
| 1µH | 1 | 3×3mm | TPS63001 buck-boost (L1) |
| 3.3µH | 1 | 3×3mm | RP2350 internal regulator (L2) |

---

## Sourcing Notes

### Recommended Suppliers

| Supplier | Best For | Lead Time |
|---|---|---|
| **LCSC** | Passives, WS2812B, common ICs | 1-2 weeks |
| **Digi-Key** | TI/Microchip ICs, precision parts | 2-3 days |
| **Mouser** | Alternative to Digi-Key | 2-3 days |
| **AliExpress** | Display, camera, SA818 modules | 2-4 weeks |
| **Amazon** | LiPo battery, lanyard, misc | 1-2 days |
| **JLCPCB** | PCB fab, SMT assembly | 1-2 weeks |

### Long Lead-Time Items (Order Early!)

- **SA818 modules** — 2-4 weeks from China
- **Custom PCBs** — 1-2 weeks from fab
- **OV2640 camera modules** — 1-3 weeks
- **ILI9341 display modules** — 1-3 weeks

### Kit Packaging Suggestions

- Group user-solderable parts in labeled bags by subsystem
- Include 2-3 spare 0603 resistors/caps (easy to lose)
- Print assembly instructions with component placement diagram
- Include test procedure checklist

---

## Cost Breakdown by Assembly Type

| Assembly | Component Cost | Notes |
|---|---|---|
| **Fab (SMT)** | ~$25 | ICs, small passives, LEDs |
| **User (TH)** | ~$11 | Switches, modules, headers |
| **Modules** | ~$16 | Display, camera |
| **Battery** | ~$6 | LiPo cell |
| **Carrier** | ~$17 | Separate board |
| **PCB** | ~$5 | Main + carrier at qty |
| **Total** | **~$81** | Complete kit with carrier |

---

## Revision History

| Version | Date | Changes |
|---|---|---|
| 1.0 | 2024-XX | Initial BOM (outdated design) |
| 2.0 | 2025-02 | Complete rewrite: TPS63001, PCM5102A, ILI9341, WS2812B blinky, USB-C with ESD |
| 2.1 | 2025-02 | Debug interface changed to Tag-Connect TC2030-CTX-NL (pads only) |
| 2.2 | 2025-02 | Battery system detailed: MCP73871 charger, LC709203F fuel gauge, shared NTC |
| 2.3 | 2025-02 | MCU support: 12MHz crystal (required for USB), W25Q128 16MB flash |
| 2.4 | 2025-02 | Added BOOTSEL button for UF2 bootloader |
| 2.5 | 2025-02 | Added L2 (3.3µH) and C_DVDD (1µF) for RP2350 internal regulator |
| 3.0 | 2026-02 | **Synchronized with KiCad schematic**: Updated all ref designators to match KiCad, added R4 (15k PROG3), added C21/C22 (2.2µF charge pump), added J10 (SD card), fixed TH1 as NTC, removed PS/SYNC resistor (intentional), added I2C pullup warning |
| 3.1 | 2026-02 | **Added SA818 carrier boards**: VHF (U9, J13-J17, C54-C55, R18) and UHF (U10, J18-J22, C56-C57) schematics complete with header pinout tables, mechanical headers connected to GND |
| 3.2 | 2026-03 | **LED split**: WS2812B-5050 for ears (D2-D11), WS2812B-2020 for display border (D12-D27). **Removed SW6** (12mm photo button) — D-pad center doubles as capture. Camera connector J4 updated to 2×9 socket. |

---

*This BOM is generated from KiCad schematic and verified against `docs/electrical-design.md`.*

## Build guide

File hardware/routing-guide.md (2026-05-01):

# Main Badge PCB Routing Guide

**For:** defcon-sstv-badge.kicad_pcb
**Board:** 4-layer, 1.6mm FR4, 1oz copper
**Design rules:** 6/6 mil trace/space, 0.3mm min drill

---

## Layer Assignment

| Layer | Name | Purpose |
|---|---|---|
| F.Cu | Signal | Components, high-speed signals, most routing |
| In1.Cu | GND | Solid ground plane — protect this, minimize cuts |
| In2.Cu | PWR | 3.3V power plane + VBAT zone |
| B.Cu | Signal | Secondary routing, Tag-Connect (J9), battery pads |

**Rule of thumb:** Route on F.Cu and B.Cu, pour on In1.Cu and In2.Cu. Every signal has a ground reference directly below it on In1.Cu.

---

## Power Plane Strategy (In2.Cu)

The power plane has two distinct zones:

```
┌─────────────────────────────────────────────┐
│              VBAT ZONE                      │  ← Direct from LiPo, feeds TPS63001 + TPS22919
│   (TPS63001 input, TPS22919 input,          │
│    MCP73871 battery rail, LC709203F)         │
├─────────────────────────────────────────────┤
│              +3V3 ZONE                      │  ← TPS63001 output, feeds everything else
│   (RP2350B, display, camera, PCM5102A,      │
│    WS2812B chain, SAO connectors)           │
└─────────────────────────────────────────────┘
```

- Keep the two zones clearly separated with a gap
- Connect each zone to its source with fat traces or fills on F.Cu/B.Cu as well
- TPS22919 output goes to carrier header J7 pin 1 — route on F.Cu with wide trace (0.5mm+), NOT through the power plane

---

## Routing Priority Order

Route these first — they have the tightest constraints and set the placement of everything else.

### Priority 1: RP2350B Power + Internal Regulator

**Do this before any signal routing.** Get all decoupling caps placed and connected.

| Component | Value | Placement Rule |
|---|---|---|
| C3-C7 | 5× 100nF (0402) | One per IOVDD pin, <3mm from pin, via straight to GND plane |
| C2 | 10µF (0603) | MCU bulk cap, within 5mm of any VDD pin |
| C1 | 1µF (0402) | DVDD decoupling, <2mm from DVDD pin, via straight to GND |
| L2 | 3.3µH (3×3mm) | Between VREG_LX and DVDD — keep this loop TIGHT and short |

**VREG inductor loop (L2) is critical:**
```
    RP2350B                    L2 (3.3µH)
    ┌──────┐                  ┌──────┐
    │VREG_LX├─── short! ──────┤      ├─── short! ───┐
    │       │                  └──────┘               │
    │ DVDD  ├─── short! ───── C1 (1µF) ──────────────┘
    │       │                     │
    │VREG_PGND├── via ──── GND plane
    └──────┘
```
- Keep L2 within 5mm of RP2350B
- The loop area (LX → L2 → DVDD → C1 → GND → PGND) must be as small as possible
- VREG_PGND should via directly to the ground plane

### Priority 2: Crystal (Y1)

| Rule | Spec |
|---|---|
| Distance from XIN/XOUT | <5mm trace length |
| Load caps (C_Y1, C_Y2) | 15pF, place between crystal and GND, <3mm from crystal pads |
| Ground plane | Solid, unbroken In1.Cu under crystal — no signal routing underneath |
| Keep-out | No high-speed signals within 5mm of crystal |
| Guard pour | Optional F.Cu ground pour ring around crystal area |

```
    RP2350B          Y1 (12MHz)
    ┌──────┐        ┌────────┐
    │  XIN ├────────┤        │
    │      │   C_Y1 │        │  <5mm traces
    │ XOUT ├────────┤        │
    └──────┘   C_Y2 └────────┘
                │  │
               GND GND (via to In1.Cu)
```

### Priority 3: QSPI Flash (U2 — W25Q128JVS)

| Rule | Spec |
|---|---|
| Distance from RP2350B | As close as possible, <15mm traces |
| Trace length matching | Match all 6 signals within ±2mm of each other |
| Trace width | 8 mil (0.2mm) minimum |
| Spacing | 8 mil between QSPI signals |
| Ground plane | Solid In1.Cu under all QSPI traces |
| C9 (100nF) | <3mm from U2 VCC pin |

**Signals (dedicated RP2350B pins, not GPIO):**
- QSPI_SS (directly from RP2350B, also to SW_BOOT1)
- QSPI_SCK
- QSPI_SD0, SD1, SD2, SD3

**Tip:** Place U2 directly adjacent to the QSPI pins on the RP2350B (usually one corner of the QFN-80). Route all 6 signals on F.Cu, no vias if possible.

### Priority 4: USB (J2 → U3 → RP2350B)

| Rule | Spec |
|---|---|
| D+/D- impedance | 90Ω differential (not critical at Full Speed, but good practice) |
| Length matching | D+ and D- within ±2mm |
| Trace width | ~12 mil (0.3mm) for 90Ω diff on 1.6mm 4-layer |
| Spacing | 6 mil between D+ and D- |
| ESD protection | U3 (USBLC6-2SC6) inline, as close to J2 as possible |
| CC resistors | R_CC1, R_CC2 (5.1kΩ) close to J2 |
| VBUS cap | C_USB1 (10µF) close to J2 |
| TVS | D_VBUS1 close to J2 |

**Route order:** J2 → U3 (ESD) → RP2350B USB_DP/USB_DM

USB is Full Speed (12 Mbps) so impedance control is nice-to-have, not mandatory. Keep the traces short and matched and you'll be fine.

### Priority 5: Camera DVP Bus (GPIO8-19 → J4)

| Rule | Spec |
|---|---|
| Data bus (D0-D7) | GPIO8-15, must be consecutive for PIO capture |
| Length matching | Match D0-D7 within ±5mm (QVGA speed is forgiving) |
| PCLK (GPIO16) | Treat as clock — slightly shorter than data, or matched |
| XCLK (GPIO19) | 20MHz output — route away from analog audio signals |
| Trace width | 8 mil (0.2mm) minimum |
| Ground plane | Solid In1.Cu reference under DVP traces |
| Bus routing | Keep D0-D7 as a group, parallel routing preferred |

**Camera connector J4** is a 2×9 through-hole socket. Place it where the camera module will sit (lower-right area per pcb-design.md). Route the DVP bus as a group from the RP2350B GPIO8-19 cluster to J4.

**Pin mapping at J4 connector (watch the pin order):**
| J4 Pin | Signal | GPIO |
|---|---|---|
| 7 | CAM_D0 | 8 |
| 10 | CAM_D1 | 9 |
| 9 | CAM_D2 | 10 |
| 12 | CAM_D3 | 11 |
| 11 | CAM_D4 | 12 |
| 14 | CAM_D5 | 13 |
| 13 | CAM_D6 | 14 |
| 16 | CAM_D7 | 15 |
| 15 | CAM_PCLK | 16 |
| 4 | CAM_VSYNC | 17 |
| 6 | CAM_HREF | 18 |
| (XCLK from MCU) | CAM_XCLK | 19 |

**Note:** R12 (10kΩ pullup on RST, pin 8) and R13 (10kΩ pulldown on PWDN, pin 17) should be placed close to J4.

### Priority 6: I2S Audio (GPIO24-25, 29 → U8)

| Rule | Spec |
|---|---|
| Trace length | Keep short, <50mm |
| Separation | Route I2S signals away from TPS63001 inductor (L1) — >10mm clearance |
| Ground plane | Solid In1.Cu under I2S traces and PCM5102A |
| Analog output | PCM5102A VOUTL is sensitive — route TX filter components (R5, R6, C24, C25) with short traces, away from digital noise |

**PCM5102A (U8) placement tip:** Put it between the RP2350B and the carrier header J7 (which carries MIC+ audio to the SA818). This minimizes the analog audio trace length to the carrier.

**PCM5102A decoupling — place close to U8:**
| Cap | Value | Pin |
|-----|---|-----|
| C19 | 100nF | AVDD |
| C20 | 10µF | DVDD |
| C21 | 2.2µF | CAPP |
| C22 | 2.2µF | CAPM |

**TX audio path routing (analog — keep short and clean):**
```
U8 VOUTL → R5 (47k) → node → R6 (470Ω) to GND
                         ↓
                    C24 (10nF) to GND
                         ↓
                    C25 (100nF) DC block
                         ↓
                    J7 pin 3 (MIC+)
```

**RX audio path routing (analog — keep short and clean):**
```
J7 pin 5 (SPK+) → C26 (1µF) DC block → R7 (4.7k) → node → R8 (4.7k) → bias
                                                        ↓
                                                   C27 (4.7nF) to GND
                                                        ↓
                                                   GPIO40 (ADC0)
```

Route RX audio on the opposite side of the board from the TPS63001 switching regulator if possible.

---

## Lower Priority (Route After the Above)

### SPI Bus (GPIO2-4 → J3 Display + J10 SD Card)

Not speed-critical at these frequencies. Standard 8 mil traces, no length matching needed.

| Signal | GPIO | Goes To |
|---|---|---|
| SPI_SCK | 2 | J3 + J10 |
| SPI_MOSI | 3 | J3 + J10 |
| SPI_MISO | 4 | J10 (display doesn't use) |
| DISP_CS | 5 | J3 only |
| DISP_DC | 6 | J3 only |
| DISP_RST | 7 | J3 only |
| DISP_BL | 22 | Q1 gate (MOSFET for backlight) |
| SD_CS | 23 | J10 only |

Route SPI as a bus from the RP2350B, branching to both J3 and J10. The bus can use vias to B.Cu if needed.

### I2C Bus (GPIO0-1)

Shared by 4 devices: camera (J4), fuel gauge (U7), SAO1 (J5), SAO2 (J6).

- Route as a bus with stubs to each device
- R1, R2 (4.7kΩ pullups to +3V3) should be near the RP2350B, not at the far end
- Standard traces, no constraints

### SA818 Control Signals (GPIO30-36 → J8)

All low-speed digital (UART 9600 baud, GPIO). Route with standard traces to carrier header J8. No constraints.

### User Controls (GPIO26, 37-39, 41, 43)

All switches with internal pullups. Route with any convenient path. Switches are through-hole, so traces can run on B.Cu underneath them.

### WS2812B LED Chain (GPIO47)

Single-wire protocol at 800kHz. Route as a daisy chain:

```
GPIO47 → D2(L0) → D3(L1) → D4(L2) → D5(L3) → D6(L4)  ← Left ear, up
                                                    ↓
         D11(R4) → D10(R3) → D9(R2) → D8(R1) → D7(R0)  ← Right ear, up
            ↓
         D12(B0) → D13(B1) → ... → D27(B15)              ← Display border, clockwise
```

**Routing tips:**
- Ear LEDs (D2-D11): Route data along the ear PCB outline, single trace
- The jump from D6 (left ear tip) to D7 (right ear base) is the longest run — route across the carrier overlap zone on B.Cu
- Border LEDs (D12-D27): Route around the display area
- **Each LED needs its 100nF bypass cap (C28-C53)** placed within 3mm of the LED's VDD/VSS pins
- 3.3V power to WS2812B chain needs decent trace width (0.3mm+) — 26 LEDs × ~12mA = ~310mA idle, peaks higher
- Consider a second 3.3V power injection point halfway through the chain (at D12, border start) to prevent voltage drop

### PWR LED (D1 — APFA3010)

GPIO30/31/32 through R14/R15/R16 to D1 cathodes. D1 anode to +3V3. Place near bottom edge per pcb-design.md. Standard routing.

---

## Power Distribution Routing

### TPS63001 (U5) — Buck-Boost Layout

**This is the noisiest part of the board.** Keep it compact and away from analog audio.

```
    C_IN (10µF)          L1 (1µH)           C_OUT1 (10µF)
    ┌────────┐          ┌──────┐           ┌────────┐
    │        │          │      │           │        │
VBAT────┤        ├──VIN  SW├──┤      ├──VOUT──┤        ├── +3V3
    │        │          │      │           │        │
    └───┬────┘          └──────┘           └───┬────┘
        │              U5 (TPS63001)           │
       GND              ┌──────┐              GND
                         │ PGND │
                         └──┬───┘
                           GND
```

**Layout rules:**
- Input cap (C_IN) close to VIN, <5mm
- Output cap (C_OUT1) close to VOUT, <5mm
- L1 close to SW pin, <5mm
- PGND (power ground pad) → via directly to GND plane
- Keep the VIN→SW→L1→VOUT loop area small
- Place U5 away from crystal (Y1), camera, and audio analog traces — >15mm separation recommended

### TPS22919 (U6) — Load Switch

- C17 (100µF 1206) close to output — this is a big cap, plan board space
- C18 (10µF) also close to output
- Route output to J7 pin 1 with wide trace (0.5mm minimum, 1mm preferred for 1.7A TX peaks)

### MCP73871 (U4) — Battery Charger

- Place near USB-C connector (J2) and battery connector (J1)
- R3, R4 close to PROG1/PROG3 pins
- TH1 (thermistor) close to battery area, away from L1/U5

---

## Carrier Header Placement

These set the mechanical interface with the carrier board. Place precisely:

```
    ┌─────────────────────────────────────────────────────────────┐
    │  J11(1×3,GND)                              J12(1×3,GND)    │  ← Top edge
    │  ~5-13mm from left                         ~107-115mm       │
    │                                                             │
    │                    CARRIER OVERLAP ZONE                      │
    │                    (~25mm deep from top)                     │
    │                                                             │
    │  J7(1×8,pwr/audio)                    J8(1×8,ctrl/data)    │  ← ~25mm from top
    │  ~10-30mm from left                   ~90-110mm from left   │
    └─────────────────────────────────────────────────────────────┘
```

All four headers are **female sockets on the main badge front side**, receiving male pins from the carrier.

**J7 pinout (power/audio), pins 1→8:** SA818_VCC, GND, GND, MIC+, GND, SPK+, GND, GND
**J8 pinout (control/data), pins 1→8:** SA818_RX, SA818_TX, SA818_PTT, SA818_PD, SA818_HL, SA818_SQ, SA818_ID, GND

> **Note:** these are the **locked** main-badge pin assignments (PCB routing complete). The carriers must be wired to match — see [carrier-rewiring-checklist.md](../docs/engineers-notebook/carrier-rewiring-checklist.md).

---

## Ground Plane (In1.Cu) Protection

The ground plane is your most important routing asset. Protect it:

- **Never** route signals on In1.Cu — it's a dedicated ground plane
- Minimize via count in critical areas (under crystal, QSPI, camera bus)
- If you must break the plane, ensure return current paths aren't disrupted
- Pour ground on F.Cu and B.Cu in empty areas for additional shielding and thermal relief

**Critical unbroken zones:**
1. Under Y1 crystal and load caps
2. Under U2 QSPI flash
3. Under camera DVP bus routing
4. Under U8 PCM5102A and analog audio traces
5. Under USB D+/D- traces

---

## Thermal Considerations

- **RP2350B exposed pad:** Connect to GND plane with multiple vias (9+ thermal vias in a 3×3 grid)
- **TPS63001 power pad:** Connect to GND plane with thermal vias
- **MCP73871 power pad:** Connect to GND plane with thermal vias

---

## DRC Settings for KiCad

Set these in Board Setup → Design Rules:

| Rule | Value |
|---|---|
| Minimum trace width | 0.15mm (6 mil) |
| Minimum clearance | 0.15mm (6 mil) |
| Minimum via drill | 0.3mm |
| Minimum via diameter | 0.6mm |
| Copper to edge clearance | 0.25mm |

**Net classes to define:**

| Net Class | Trace Width | Clearance | Via Size | Use |
|---|---|---|---|-----|
| Default | 0.2mm | 0.15mm | 0.6/0.3mm | General signals |
| Power | 0.4mm | 0.2mm | 0.8/0.4mm | 3.3V, VBAT, VBUS |
| USB | 0.3mm | 0.15mm | 0.6/0.3mm | USB D+/D- |
| HighCurrent | 0.8mm | 0.2mm | 0.8/0.4mm | SA818 VCC (to J7 pin 1) |

---

## Checklist Before Starting

- [ ] Board setup: 4 layers configured (F.Cu, In1.Cu/GND, In2.Cu/PWR, B.Cu)
- [ ] Design rules entered (trace/space, via sizes, net classes)
- [ ] Board outline complete (TV shape with ears and feet) — already done
- [ ] All footprints assigned and imported
- [ ] Netlisted from schematic (Update PCB from Schematic)
- [ ] Component placement done (see pcb-design.md for zones)
- [ ] Ground plane poured on In1.Cu
- [ ] Power plane zones defined on In2.Cu (VBAT + 3V3)

## Suggested Routing Order Checklist

- [ ] Place and connect all RP2350B decoupling caps (C1-C7)
- [ ] Route VREG inductor loop (L2, C1)
- [ ] Place and route crystal (Y1, C_Y1, C_Y2)
- [ ] Place and route QSPI flash (U2, C9)
- [ ] Route USB (J2 → U3 → RP2350B)
- [ ] Route camera DVP bus (RP2350B → J4)
- [ ] Place and route TPS63001 (U5, L1, C_IN, C_OUT1)
- [ ] Place and route TPS22919 (U6, C17, C18)
- [ ] Place and route MCP73871 (U4, R3, R4, C8/C10/C11)
- [ ] Route I2S audio (RP2350B → U8)
- [ ] Route TX audio filter chain (U8 → R5/R6/C24/C25 → J7 pin 3)
- [ ] Route RX audio filter chain (J7 pin 5 → C26/R7/R8/C27/R9/R10 → GPIO40)
- [ ] Route SPI bus (RP2350B → J3 display → J10 SD card)
- [ ] Route I2C bus (RP2350B → J4, U7, J5, J6)
- [ ] Route SA818 control signals (RP2350B → J8)
- [ ] Route carrier power (VBAT → U6 → J7 pin 1)
- [ ] Route WS2812B LED chain (GPIO47 → D2...D27)
- [ ] Route user controls (switches → RP2350B)
- [ ] Route PWR LED (RP2350B → R14/R15/R16 → D1)
- [ ] Fill ground pours on F.Cu and B.Cu
- [ ] Run DRC — zero errors
- [ ] Visual inspection of ground plane continuity on In1.Cu

---

*Good luck. No RF on this board — you've got this.*

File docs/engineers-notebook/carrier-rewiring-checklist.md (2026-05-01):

# Carrier Connector Rewiring Checklist

**Status:** Pending — both carriers need this work before fabrication.

Both SA818 carrier boards (VHF and UHF) currently have J14/J18 (Power/Audio) and J15/J20 (Control/Data) pin assignments that **do not match** the main badge J7/J8 pin assignments. When a carrier is plugged into the main badge, every signal except VCC, GND, and ID lands on the wrong pin.

The main badge pinout is **locked** (routing complete). The carriers must be rewired to match.

For background and how this happened, see [carrier connector mismatch findings](#why-this-needs-doing) at the bottom of this doc.

---

## Source of Truth: Main Badge J7 and J8

These are the locked pin assignments that the carriers must mate with.

### J7 — Power/Audio (main badge)

| Pin | Net |
|-----|-----|
| 1 | SA818_VCC |
| 2 | GND |
| 3 | GND |
| 4 | MIC+ |
| 5 | GND |
| 6 | SPK+ |
| 7 | GND |
| 8 | GND |

### J8 — Control/Data (main badge)

| Pin | Net |
|-----|-----|
| 1 | SA818_RX |
| 2 | SA818_TX |
| 3 | SA818_PTT |
| 4 | SA818_PD |
| 5 | SA818_HL |
| 6 | SA818_SQ |
| 7 | SA818_ID |
| 8 | GND |

> **UART naming convention:** "SA818_RX" is the main badge's UART RX line — data flows FROM the SA818's TXD pin INTO the main badge. "SA818_TX" is the main badge's UART TX — data flows FROM the main badge INTO the SA818's RXD pin. Carrier-side wiring must connect SA818 TXD to J15/J20 pin 1 (mates with SA818_RX) and SA818 RXD to J15/J20 pin 2 (mates with SA818_TX).

---

## Required Carrier Pinouts (after rewiring)

These are the **target** pin assignments. Both carriers (VHF and UHF) get the same changes — different connector references but same logic.

### J14 (VHF) / J18 (UHF) — Power/Audio

| Pin | Connect to | Currently | Change required |
|-----|---|---|---|
| 1 | U9/U10 VDD (pad 8) | VDD | ✓ no change |
| 2 | GND | GND | ✓ no change |
| 3 | **GND** | MIC_IN | **disconnect MIC_IN from pin 3, connect GND** |
| 4 | **U9/U10 MIC_IN (pad 18)** | GND | **disconnect GND, connect MIC_IN** |
| 5 | **GND** | AF_OUT | **disconnect AF_OUT from pin 5, connect GND** |
| 6 | **U9/U10 AF_OUT (pad 3)** | GND | **disconnect GND, connect AF_OUT** |
| 7 | GND | GND | ✓ no change |
| 8 | GND | GND | ✓ no change |

**Net effect:** MIC moves from pin 3 → pin 4. SPK moves from pin 5 → pin 6. (One-pin shift for the audio signals.)

### J15 (VHF) / J20 (UHF) — Control/Data

| Pin | Connect to | Currently | Change required |
|-----|---|---|---|
| 1 | **U9/U10 TXD (pad 17)** | ~PTT (pad 5) | **rewire** |
| 2 | **U9/U10 RXD (pad 16)** | ~PD (pad 6) | **rewire** |
| 3 | **U9/U10 ~PTT (pad 5)** | H/L (pad 7) | **rewire** |
| 4 | **U9/U10 ~PD (pad 6)** | ~SQ (pad 1) | **rewire** |
| 5 | **U9/U10 H/L (pad 7)** | RXD (pad 16) | **rewire** |
| 6 | **U9/U10 ~SQ (pad 1)** | TXD (pad 17) | **rewire** |
| 7 | R18 (band ID) | R18 | ✓ no change |
| 8 | GND | GND | ✓ no change |

**Net effect:** UART pins move from 5/6 to 1/2 (and TXD/RXD swap, since SA818 TXD must mate with main badge RX). Control signals (PTT/PD/HL/SQ) shift from pins 1-4 to pins 3-6.

---

## Schematic Edit Steps

Do this for **both** carriers (sa818-v-carrier.kicad_sch and sa818-u-carrier.kicad_sch). The procedure is identical; only the designators differ (U9/J14/J15 on VHF; U10/J18/J20 on UHF).

### Step 1: Open the carrier schematic in KiCad

Open `hardware/sa818-v-carrier/sa818-v-carrier.kicad_sch` first. After completing it, repeat for `hardware/sa818-u-carrier/sa818-u-carrier.kicad_sch`.

### Step 2: Rewire J14/J18 (Power/Audio)

The SA818 module connects to J14/J18 via three signal wires (VDD on pin 1, MIC_IN on pin 3, AF_OUT on pin 5). Two of those need to move.

1. **Locate the wire connecting U9/U10 pad 18 (MIC_IN) to J14/J18 pin 3.**
2. Delete the wire segment that lands on J14/J18 pin 3.
3. Draw a new wire segment from the existing MIC_IN trace to J14/J18 pin 4.
4. Add a GND symbol on J14/J18 pin 3 (the now-orphaned pin).
5. **Locate the wire connecting U9/U10 pad 3 (AF_OUT) to J14/J18 pin 5.**
6. Delete the wire segment that lands on J14/J18 pin 5.
7. Draw a new wire segment from the existing AF_OUT trace to J14/J18 pin 6.
8. Add a GND symbol on J14/J18 pin 5 (the now-orphaned pin).
9. Remove the GND symbols that were originally on pins 4 and 6 (replaced by the signal wires now).

### Step 3: Rewire J15/J20 (Control/Data)

This is the bigger change. Six signal wires all need to land on different pins.

The fastest approach is to **delete all 6 signal wires between U9/U10 and J15/J20** and then redraw them per the new pin map. Don't change anything about U9/U10 — only the J15/J20 endpoints move.

| Signal | From U9/U10 pad | New J15/J20 pin |
|---|---|---|
| TXD | pad 17 | pin 1 |
| RXD | pad 16 | pin 2 |
| ~PTT | pad 5 | pin 3 |
| ~PD | pad 6 | pin 4 |
| H/L | pad 7 | pin 5 |
| ~SQ | pad 1 | pin 6 |

R18 stays connected to pin 7. GND stays on pin 8. No changes there.

> **Tip:** in KiCad, you can move a wire endpoint by clicking it and dragging, instead of deleting and redrawing. This is faster but more error-prone — ensure you don't accidentally connect to a different pin.

### Step 4: Run ERC

Save and run **Inspect → Electrical Rules Checker**. Expected: zero errors. If any pin shows up as disconnected or with multiple drivers, you've introduced a wiring error — fix before continuing.

### Step 5: Update PCB from Schematic

Open the PCB editor. **File → Update PCB from Schematic** (`F8`). KiCad will report changed connections — this is expected. Apply the changes.

The PCB will now have **rip-up ratsnest lines** for all the moved signals — they need to be re-routed.

---

## PCB Re-routing Steps

### Step 6: Identify affected traces

The original carrier PCB had short, direct traces from the SA818 module to J14/J15. With the new pin assignments, those traces need to land on different pads. Most likely you'll need to:

1. Delete the old traces between U9/U10 and J14/J15 (and J18/J20 on UHF).
2. Re-route from scratch.

### Step 7: Re-route signal traces

The carriers are simple boards (no high-speed signals on these pins, all are DC or low-speed UART). Standard 0.2mm trace width is fine.

**Recommended order:**
1. Re-route VDD (pin 1) and GND fills first (high-current paths).
2. Re-route audio signals (MIC_IN to pin 4, AF_OUT to pin 6) — short, direct paths from SA818 audio pins.
3. Re-route control signals (PTT, PD, HL, SQ) to pins 3-6.
4. Re-route UART (TXD to pin 1, RXD to pin 2) — these are long traces from the SA818's UART pins (pad 16/17) all the way to the front-edge connector pins 1/2.

> **Note on UART trace routing:** TXD and RXD currently route from pads 16/17 to J15/J20 pins 5/6 (closest pins). After rewiring, they need to route to pins 1/2 — likely longer traces. UART at 9600 baud is forgiving; trace length isn't a problem.

### Step 8: Run DRC

**Inspect → Design Rules Checker.** Resolve any errors. Should be clean — same design rules as before, just different signal-to-pad mappings.

### Step 9: Visual inspection

- All 6 signals on J15/J20 pins 1-6 connected to expected SA818 pads
- Audio signals on J14/J18 pins 4 and 6
- GND fills uninterrupted under all signal traces
- No orphan vias or stub traces from the old routing

---

## Validation: Cross-Project Consistency Check

After both carriers are updated, validate by comparing pad nets across the three KiCad projects.

### Step 10: Net-by-net cross-check

For each pin, the main badge net name must match what the carrier connects to functionally:

| Connector pin | Main badge net | VHF carrier connects to | UHF carrier connects to | Status |
|---|---|---|---|---|
| J7/J14/J18 pin 1 | SA818_VCC | U9 pad 8 (VDD) | U10 pad 8 (VDD) | should match |
| J7/J14/J18 pin 4 | MIC+ | U9 pad 18 (MIC_IN) | U10 pad 18 (MIC_IN) | should match (after fix) |
| J7/J14/J18 pin 6 | SPK+ | U9 pad 3 (AF_OUT) | U10 pad 3 (AF_OUT) | should match (after fix) |
| J8/J15/J20 pin 1 | SA818_RX | U9 pad 17 (TXD) | U10 pad 17 (TXD) | should match (after fix) |
| J8/J15/J20 pin 2 | SA818_TX | U9 pad 16 (RXD) | U10 pad 16 (RXD) | should match (after fix) |
| J8/J15/J20 pin 3 | SA818_PTT | U9 pad 5 (~PTT) | U10 pad 5 (~PTT) | should match (after fix) |
| J8/J15/J20 pin 4 | SA818_PD | U9 pad 6 (~PD) | U10 pad 6 (~PD) | should match (after fix) |
| J8/J15/J20 pin 5 | SA818_HL | U9 pad 7 (H/L) | U10 pad 7 (H/L) | should match (after fix) |
| J8/J15/J20 pin 6 | SA818_SQ | U9 pad 1 (~SQ) | U10 pad 1 (~SQ) | should match (after fix) |
| J8/J15/J20 pin 7 | SA818_ID | R18 → GND (VHF) / R18 DNP (UHF) | same | unchanged |
| J8/J15/J20 pin 8 | GND | GND | GND | unchanged |

Quick verification command (once both carriers are updated):

```bash
# From repo root, sanity check all three projects' pad nets agree
grep -A 2 'pad "[1-8]" thru_hole' hardware/main_badge/defcon-sstv-badge.kicad_pcb | grep 'net.*"SA818\|net.*"GND\|net.*"MIC\|net.*"SPK'
grep -A 1 'pad "[1-8]" thru_hole' hardware/sa818-v-carrier/sa818-v-carrier.kicad_pcb | grep 'pinfunction'
grep -A 1 'pad "[1-8]" thru_hole' hardware/sa818-u-carrier/sa818-u-carrier.kicad_pcb | grep 'pinfunction'
```

---

## Related Fix: UHF Carrier Band-ID Resistor

While verifying the rewiring, the UHF carrier was found to have **no R18 resistor at all** on the SA818_ID line (J20 pin 7). The previous documentation said "R18 DNP" but the schematic has no R18 instance.

Without R18, J20 pin 7 floats. Combined with the main badge's likely internal pull-down on GPIO39, **the UHF carrier reads identically to the VHF carrier** (both LOW), defeating the band-detection scheme.

### Fix

Add a **10kΩ pull-up resistor to SA818_VCC** on the UHF carrier, designated **R18** (matching the VHF carrier's designator for consistency).

| Carrier | R18 value | R18 connections | ID pin reads |
|---|---|---|---|
| VHF | 0Ω | J15 pin 7 ↔ GND | LOW |
| UHF | **10kΩ** | **J20 pin 7 ↔ SA818_VCC** | **HIGH** |

### Schematic edit steps (UHF carrier only)

1. Place a Resistor symbol (`Device:R`) near J20 pin 7.
2. **Set Reference manually to `R18`** (KiCad will auto-suggest R1; double-click the symbol → change Reference to `R18`). Don't run "Annotate Schematic" after this — it will try to renumber.
3. Set Value to `10k`.
4. Set Footprint to `Resistor_SMD:R_0402_1005Metric` (matches the VHF carrier's R18).
5. Wire R18 pin 1 to J20 pin 7 (the SA818_ID line).
6. Wire R18 pin 2 to **SA818_VCC** (the same net that connects to J18 pin 1 and U10 pad 8). The simplest route: tap into the existing VCC trace near U10 or C56/C57.
7. Save, run ERC, push F8 to PCB, route the new traces (short, simple — both endpoints are local to the carrier's right side).

### Caveat about timing

SA818_VCC is gated by the main badge's TPS22919 load switch. The ID pin is only valid **after** firmware drives SA818_PD HIGH and the SA818_VCC rail comes up. This is fine — the standard boot sequence is:

1. Power on RP2350B
2. Drive SA818_PD HIGH → TPS22919 enables → SA818_VCC = 3.3V
3. Wait ~1ms for rail to stabilize
4. Read SA818_ID GPIO → distinguishes VHF (LOW) from UHF (HIGH)
5. Initialize SA818 over UART

Document this requirement in the firmware design when that work begins.

---

## Why This Needs Doing

The main badge J7 and J8 schematic pin assignments deviate from the originally documented intent and from the carriers' current pin assignments. Probable cause: at some point during main badge layout, the connectors got physically rotated 180° on the PCB for routing/mechanical reasons, and during that rework the signals were reassigned to different schematic pins to keep traces short. The carriers were never updated to follow.

Detected on 2026-05-01 while spot-checking a wiring concern (RP2350B GPIO34 to TPS22919 ON pin to J8 pin 4). The trace through the main badge looked fine, but when the carrier-side pinouts were checked, every signal except VCC/GND/ID landed on the wrong pin.

ERC and DRC don't catch this because each KiCad project (main badge, VHF carrier, UHF carrier) has its own netlist — no cross-project validation exists.

**Lesson learned:** for projects with multi-board mating, define the connector pinout in **one** place and treat all boards' connectors as derived. Consider adding a "connectors-of-truth" doc that's updated *first*, before any schematic, when the pinout changes.

---

## Status Tracking

- [x] VHF carrier — schematic edits (J14, J15)
- [ ] VHF carrier — PCB re-route
- [ ] VHF carrier — DRC clean
- [x] UHF carrier — schematic edits (J18, J20)
- [ ] UHF carrier — add R18 = 10kΩ pull-up to SA818_VCC (band-ID fix)
- [ ] UHF carrier — PCB re-route
- [ ] UHF carrier — DRC clean
- [x] Cross-project net validation pass (verified by net trace 2026-05-01)
- [x] CLAUDE.md updated to reflect locked pinout
- [x] routing-guide.md updated
- [x] electrical-design.md updated

---

*Last updated: 2026-05-01*

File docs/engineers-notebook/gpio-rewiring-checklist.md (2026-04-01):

# GPIO Rewiring Checklist

Step-by-step checklist for reassigning U1 (RP2350B) GPIO connections in the KiCad schematic. All rewiring happens on the **MCU sheet** (mcu.kicad_sch). Other sheets use global labels that don't change names.

Reference: `docs/engineers-notebook/gpio-optimization.md` for rationale.

## Before You Start

- Save a backup of all .kicad_sch files
- Have `docs/u1-pinout.md` open for reference
- Work through one group at a time, checking off as you go

## Signals That DO NOT Move (no action needed)

These stay on the same GPIO — skip them:

| Signal | GPIO | Status |
|---|---|---|
| SPI_MISO | GPIO4 | No change |
| DISP_CS | GPIO5 | No change |
| CAM_D0 | GPIO8 | No change |
| CAM_D1 | GPIO9 | No change |
| CAM_D2 | GPIO10 | No change |
| CAM_D3 | GPIO11 | No change |
| CAM_D4 | GPIO12 | No change |
| CAM_D5 | GPIO13 | No change |
| CAM_D6 | GPIO14 | No change |
| CAM_D7 | GPIO15 | No change |
| CAM_PCLK | GPIO16 | No change |
| CAM_VSYNC | GPIO17 | No change |
| CAM_HREF | GPIO18 | No change |
| RX_AUDIO | GPIO40 | No change |

Also unchanged: USB_DM, USB_DP, SWCLK, SWDIO, RUN, all QSPI, crystal, VREG, power pins.

---

## Rewiring Checklist

Work through these groups in order. For each signal: disconnect the global label wire from the old GPIO pin on U1, and reconnect it to the new GPIO pin.

### Group 1: I2C Bus (move from top to right side)

- [x] **I2C_SDA**: disconnect from GPIO0 → reconnect to **GPIO44**
- [x] **I2C_SCL**: disconnect from GPIO1 → reconnect to **GPIO45**

### Group 2: I2S Audio (move to where I2C was)

- [x] **I2S_LRCK**: disconnect from GPIO25 → reconnect to **GPIO1**
- [x] **I2S_DIN**: disconnect from GPIO29 → reconnect to **GPIO2**
- [x] **I2S_BCK**: disconnect from GPIO24 → reconnect to **GPIO3**

### Group 3: SPI Bus (shift from GPIO2-3 to GPIO6-7)

- [x] **SPI_SCK**: disconnect from GPIO2 → reconnect to **GPIO6**
- [x] **SPI_MOSI**: disconnect from GPIO3 → reconnect to **GPIO7**

### Group 4: Display Control (scatter to new homes)

- [x] **DISP_DC**: disconnect from GPIO6 → reconnect to **GPIO19** (was no_connect, remove the NC marker first)
- [x] **DISP_RST**: disconnect from GPIO7 → reconnect to **GPIO43**
- [x] **DISP_BL**: disconnect from GPIO22 → reconnect to **GPIO29**
- [x] **SD_CS**: disconnect from GPIO23 → reconnect to **GPIO46**

### Group 5: LED Chain (move to top side)

- [x] **LED_DATA**: disconnect from GPIO47 → reconnect to **GPIO0**
- [x] Mark **GPIO47** as no_connect (add NC marker)

### Group 6: Camera XCLK (new signal)

- [x] Remove no_connect marker from **GPIO19** (if not already done in Group 4)
- [x] **CAM_XCLK**: create new global label, connect to **GPIO20** (was SAO1_GPIO1)

### Group 7: SAO Connectors (rearrange)

- [x] **SAO1_GPIO1**: disconnect from GPIO20 → reconnect to **GPIO27**
- [x] **SAO1_GPIO2**: disconnect from GPIO21 → reconnect to **GPIO28**
- [x] **SAO2_GPIO1**: disconnect from GPIO27 → reconnect to **GPIO41**
- [x] **SAO2_GPIO2**: disconnect from GPIO28 → reconnect to **GPIO42** (was no_connect, remove NC marker first)

### Group 8: D-pad Switches (consolidate to bottom-left)

- [x] **DPAD_UP**: disconnect from GPIO37 → reconnect to **GPIO21**
- [x] **DPAD_DOWN**: disconnect from GPIO38 → reconnect to **GPIO22**
- [x] **DPAD_LEFT**: disconnect from GPIO39 → reconnect to **GPIO23**
- [x] **DPAD_RIGHT**: disconnect from GPIO26 → reconnect to **GPIO24**
- [x] **DPAD_CENTER**: disconnect from GPIO41 → reconnect to **GPIO25**

### Group 9: Airplane Switch

- [x] **AIRPLANE**: disconnect from GPIO43 → reconnect to **GPIO26**

### Group 10: SA818 Radio (consolidate to right side)

- [x] **SA818_PTT**: disconnect from GPIO32 → reconnect to **GPIO33**
- [x] **SA818_PD**: disconnect from GPIO33 → reconnect to **GPIO34**
- [x] **SA818_HL**: disconnect from GPIO34 → reconnect to **GPIO35**
- [x] **SA818_TX**: disconnect from GPIO31 → reconnect to **GPIO36**
- [x] **SA818_RX**: disconnect from GPIO30 → reconnect to **GPIO37**
- [x] **SA818_SQ**: disconnect from GPIO36 → reconnect to **GPIO38**
- [x] **SA818_ID**: disconnect from GPIO35 → reconnect to **GPIO39**

**Warning:** SA818 signals are currently tangled (e.g., GPIO35 currently has SA818_ID but GPIO35's new signal is SA818_HL). Disconnect ALL seven SA818 labels first, then reconnect them all. Don't do them one at a time or you'll create conflicts.

### Group 11: PWR LED (move from upper-right to bottom)

- [x] **PWR_R**: disconnect from GPIO44 → reconnect to **GPIO30**
- [x] **PWR_G**: disconnect from GPIO45 → reconnect to **GPIO31**
- [x] **PWR_B**: disconnect from GPIO46 → reconnect to **GPIO32**

---

## Post-Rewiring Verification

- [x] Run **ERC** — should be clean (no unconnected pins, no missing connections)
- [x] Verify no GPIO has two signals (check for duplicate connections)
- [x] Verify GPIO19 has DISP_DC (not NC)
- [x] Verify GPIO20 has CAM_XCLK (new label)
- [x] Verify GPIO42 has SAO2_GPIO2 (was NC)
- [x] Verify GPIO47 is NC (was LED_DATA)
- [x] Count: 47 GPIOs assigned + 1 spare (GPIO47) = 48 total

## Quick Reference: Final GPIO Assignment

| GPIO | Signal | GPIO | Signal |
|---|---|---|---|
| 0 | LED_DATA | 24 | DPAD_RIGHT |
| 1 | I2S_LRCK | 25 | DPAD_CENTER |
| 2 | I2S_DIN | 26 | AIRPLANE |
| 3 | I2S_BCK | 27 | SAO1_GPIO1 |
| 4 | SPI_MISO | 28 | SAO1_GPIO2 |
| 5 | DISP_CS | 29 | DISP_BL |
| 6 | SPI_SCK | 30 | PWR_R |
| 7 | SPI_MOSI | 31 | PWR_G |
| 8-15 | CAM_D0-D7 | 32 | PWR_B |
| 16 | CAM_PCLK | 33 | SA818_PTT |
| 17 | CAM_VSYNC | 34 | SA818_PD |
| 18 | CAM_HREF | 35 | SA818_HL |
| 19 | DISP_DC | 36 | SA818_TX |
| 20 | CAM_XCLK | 37 | SA818_RX |
| 21 | DPAD_UP | 38 | SA818_SQ |
| 22 | DPAD_DOWN | 39 | SA818_ID |
| 23 | DPAD_LEFT | 40 | RX_AUDIO |
| | | 41 | SAO2_GPIO1 |
| | | 42 | SAO2_GPIO2 |
| | | 43 | DISP_RST |
| | | 44 | I2C_SDA |
| | | 45 | I2C_SCL |
| | | 46 | SD_CS |
| | | 47 | spare (NC) |

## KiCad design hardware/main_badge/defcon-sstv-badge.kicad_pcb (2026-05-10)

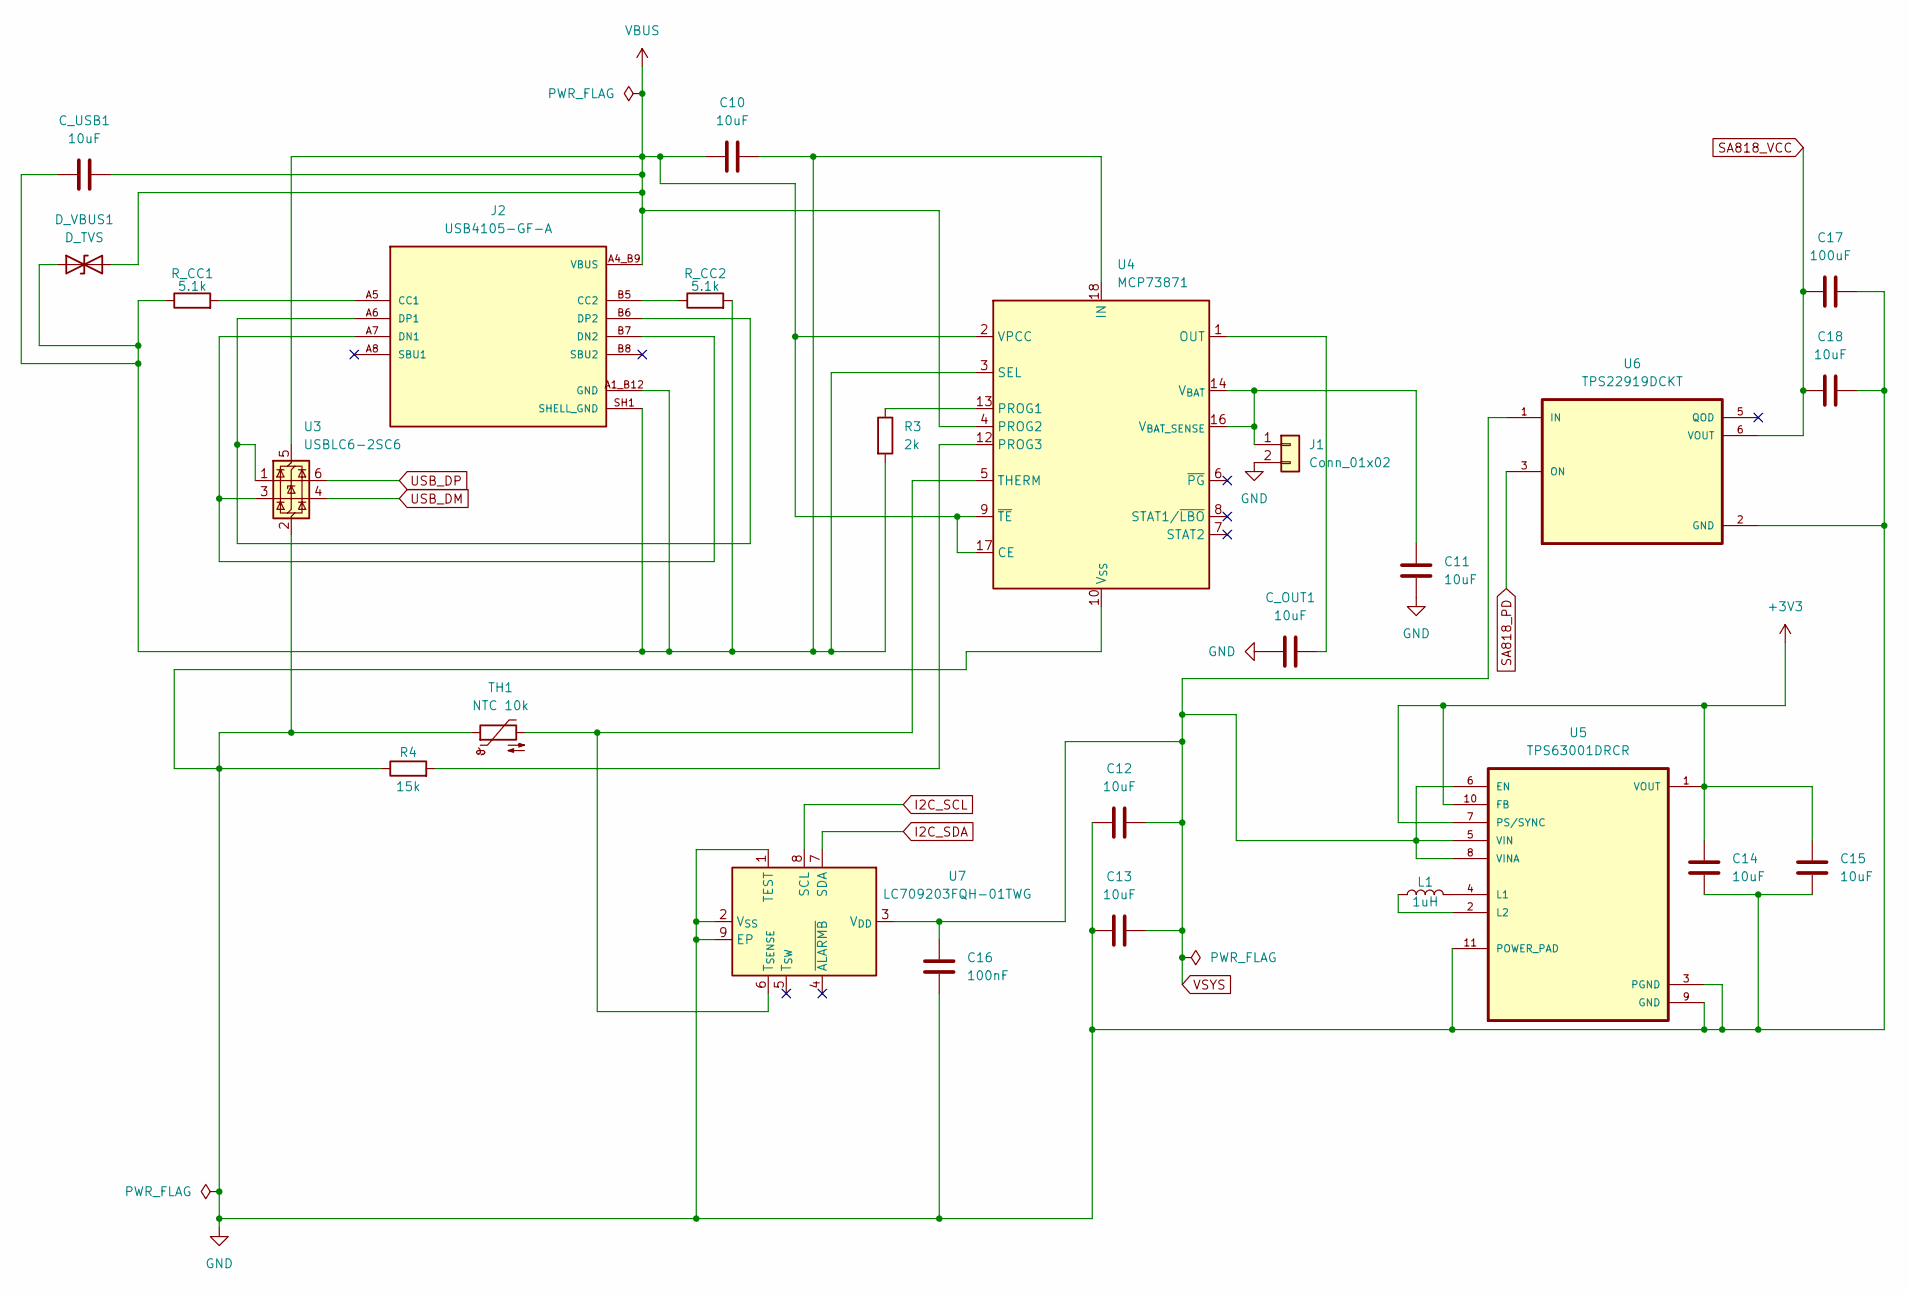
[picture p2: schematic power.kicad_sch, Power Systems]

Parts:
C10, C11, C12, C13, C14, C15: 10uF; C_0805_2012Metric
C16: 100nF; C_0402_1005Metric
C17: 100uF; C_1206_3216Metric
C18: 10uF; C_0603_1608Metric
C_OUT1: 10uF; C_0805_2012Metric
C_USB1: 10uF; C_0603_1608Metric
D_VBUS1: D_TVS; D_SOD-323
J1: Conn_01x02; JST_PH_B2B-PH-K_1x02_P2.00mm_Vertical
J2: USB4105-GF-A; GCT_USB4105-GF-A; PARTREV B4
L1: 1uH; L_Taiyo-Yuden_NR-30xx_HandSoldering
R3: 2k; R_0603_1608Metric
R4: 15k; R_0603_1608Metric
R_CC1, R_CC2: 5.1k; R_0402_1005Metric
TH1: NTC 10k; R_0603_1608Metric
U3: USBLC6-2SC6; SOT-23-6
U4: MCP73871; QFN-20-1EP_4x4mm_P0.5mm_EP2.5x2.5mm
U5: TPS63001DRCR; VREG_V62_16624-01YE
U6: TPS22919DCKT; SOT65P210X110-6N
U7: LC709203FQH-01TWG; WDFN-8-1EP_4x3mm_P0.65mm_EP2.4x1.8mm

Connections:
+3V3: C14.1, C15.1, U5.1 (VOUT), U5.7 (PS/SYNC), U5.10 (FB); also elsewhere on the board
I2C_SCL: U7.8 (SCL); also elsewhere on the board
I2C_SDA: U7.7 (SDA); also elsewhere on the board
unnamed: C_OUT1.1, U4.1 (OUT), U4.20 (OUT)
unnamed: C11.1, J1.1, U4.14 (V_{BAT}), U4.15 (V_{BAT}), U4.16 (V_{BAT_SENSE})
unnamed: J2.A5 (CC1), R_CC1.2
unnamed: J2.B5 (CC2), R_CC2.1
unnamed: J2.A7 (DN1), J2.B7 (DN2), U3.3 (I/O2)
unnamed: J2.A6 (DP1), J2.B6 (DP2), U3.1 (I/O1)
unnamed: R3.1, U4.13 (PROG1)
unnamed: R4.2, U4.12 (PROG3)
unnamed: TH1.2, U4.5 (THERM), U7.6 (T_{SENSE})
unnamed: L1.2, U5.4 (L1)
unnamed: L1.1, U5.2 (L2)
SA818_PD: U6.3 (ON); also elsewhere on the board
SA818_VCC: C17.1, C18.1, U6.6 (VOUT); also elsewhere on the board
USB_DM: U3.4 (I/O2); also elsewhere on the board
USB_DP: U3.6 (I/O1); also elsewhere on the board
VBUS: C10.1, C_USB1.2, D_VBUS1.2 (A2), J2.A4_B9 (VBUS), J2.B4_A9 (VBUS), U3.5 (VBUS), U4.2 (VPCC), U4.4 (PROG2), U4.9 (~TE), U4.17 (CE)
VSYS: C12.1, C13.2, C16.1, U5.5 (VIN), U5.6 (EN), U5.8 (VINA), U6.1 (IN), U7.3 (V_{DD})

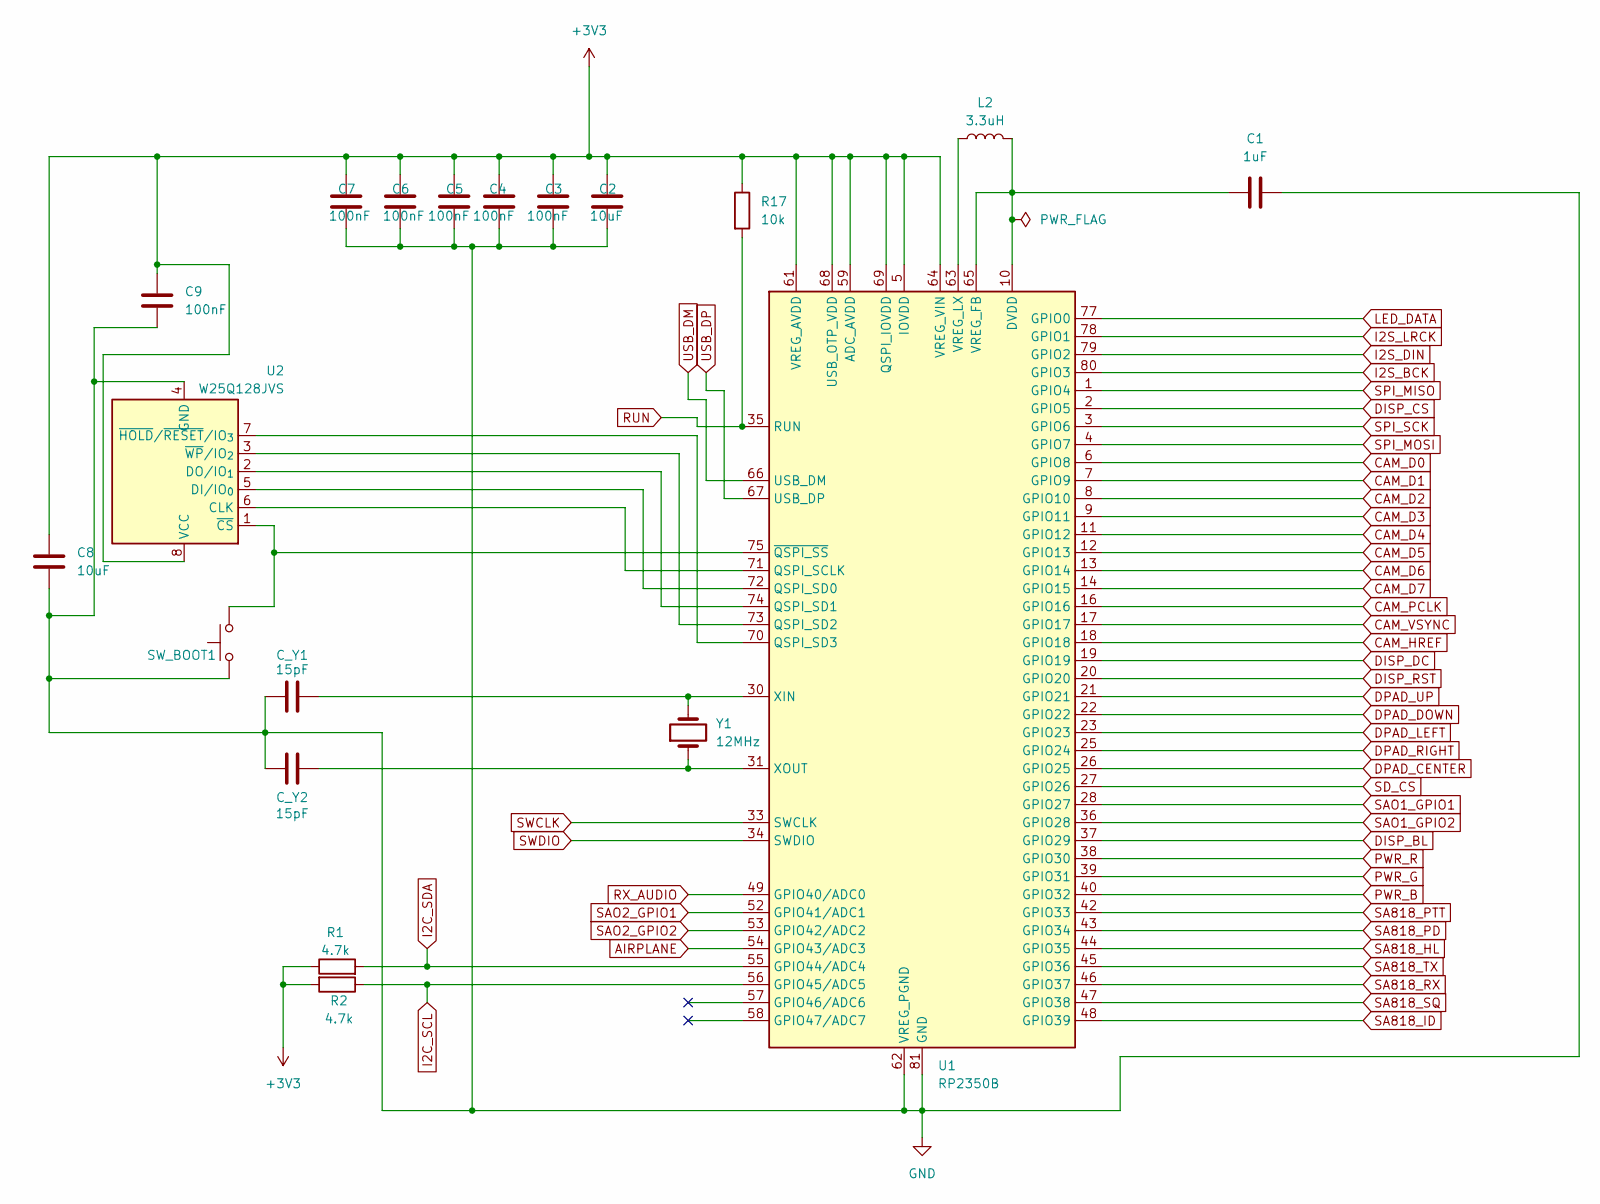
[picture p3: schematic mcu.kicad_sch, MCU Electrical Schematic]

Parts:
C1: 1uF; C_0402_1005Metric
C2: 10uF; C_0603_1608Metric
C3, C4, C5, C6, C7, C9: 100nF; C_0402_1005Metric
C8: 10uF; C_0805_2012Metric
C_Y1, C_Y2: 15pF; C_0402_1005Metric
L2: 3.3uH; L_Taiyo-Yuden_NR-30xx_HandSoldering
R1, R2: 4.7k; R_0603_1608Metric
R17: 10k; R_0603_1608Metric
SW_BOOT1: SW_Push; SW_SPST_CK_RS282G05A3
U1: RP2350B; QFN-80-1EP_10x10mm_P0.4mm_EP3.4x3.4mm
U2: W25Q128JVS; SOIC-8_5.3x5.3mm_P1.27mm
Y1: 12MHz; Crystal_SMD_3215-2Pin_3.2x1.5mm

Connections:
+3V3: C2.1, C3.1, C4.1, C5.1, C6.1, C7.1, C8.1, C9.1, R1.1, R2.2, R17.1, U1.5 (IOVDD), U1.15 (IOVDD), U1.24 (IOVDD), U1.29 (IOVDD), U1.41 (IOVDD), U1.50 (IOVDD), U1.59 (ADC_AVDD), U1.60 (IOVDD), U1.61 (VREG_AVDD), U1.64 (VREG_VIN), U1.68 (USB_OTP_VDD), U1.69 (QSPI_IOVDD), U1.76 (IOVDD), U2.8 (VCC); also elsewhere on the board
AIRPLANE: U1.54 (GPIO43/ADC3); also elsewhere on the board
CAM_D0: U1.6 (GPIO8); also elsewhere on the board
CAM_D1: U1.7 (GPIO9); also elsewhere on the board
CAM_D2: U1.8 (GPIO10); also elsewhere on the board
CAM_D3: U1.9 (GPIO11); also elsewhere on the board
CAM_D4: U1.11 (GPIO12); also elsewhere on the board
CAM_D5: U1.12 (GPIO13); also elsewhere on the board
CAM_D6: U1.13 (GPIO14); also elsewhere on the board
CAM_D7: U1.14 (GPIO15); also elsewhere on the board
CAM_HREF: U1.18 (GPIO18); also elsewhere on the board
CAM_PCLK: U1.16 (GPIO16); also elsewhere on the board
CAM_VSYNC: U1.17 (GPIO17); also elsewhere on the board
DISP_BL: U1.37 (GPIO29); also elsewhere on the board
DISP_CS: U1.2 (GPIO5); also elsewhere on the board
DISP_DC: U1.19 (GPIO19); also elsewhere on the board
DISP_RST: U1.20 (GPIO20); also elsewhere on the board
DPAD_CENTER: U1.26 (GPIO25); also elsewhere on the board
DPAD_DOWN: U1.22 (GPIO22); also elsewhere on the board
DPAD_LEFT: U1.23 (GPIO23); also elsewhere on the board
DPAD_RIGHT: U1.25 (GPIO24); also elsewhere on the board
DPAD_UP: U1.21 (GPIO21); also elsewhere on the board
I2C_SCL: R2.1, U1.56 (GPIO45/ADC5); also elsewhere on the board
I2C_SDA: R1.2, U1.55 (GPIO44/ADC4); also elsewhere on the board
I2S_BCK: U1.80 (GPIO3); also elsewhere on the board
I2S_DIN: U1.79 (GPIO2); also elsewhere on the board
I2S_LRCK: U1.78 (GPIO1); also elsewhere on the board
LED_DATA: U1.77 (GPIO0); also elsewhere on the board
unnamed: U1.71 (QSPI_SCLK), U2.6 (CLK)
unnamed: U1.72 (QSPI_SD0), U2.5 (DI/IO_{0})
unnamed: U1.74 (QSPI_SD1), U2.2 (DO/IO_{1})
unnamed: U1.73 (QSPI_SD2), U2.3 (~WP/IO_{2})
unnamed: U1.70 (QSPI_SD3), U2.7 (~HOLD/~RESET/IO_{3})
unnamed: C1.1, L2.2, U1.10 (DVDD), U1.32 (DVDD), U1.51 (DVDD), U1.65 (VREG_FB)
unnamed: L2.1, U1.63 (VREG_LX)
unnamed: C_Y1.2, U1.30 (XIN), Y1.2
unnamed: C_Y2.2, U1.31 (XOUT), Y1.1
unnamed: SW_BOOT1.2, U1.75 (~QSPI_SS), U2.1 (~CS)
PWR_B: U1.40 (GPIO32); also elsewhere on the board
PWR_G: U1.39 (GPIO31); also elsewhere on the board
PWR_R: U1.38 (GPIO30); also elsewhere on the board
RUN: R17.2, U1.35 (RUN); also elsewhere on the board
RX_AUDIO: U1.49 (GPIO40/ADC0); also elsewhere on the board
SA818_HL: U1.44 (GPIO35); also elsewhere on the board
SA818_ID: U1.48 (GPIO39); also elsewhere on the board
SA818_PD: U1.43 (GPIO34); also elsewhere on the board
SA818_PTT: U1.42 (GPIO33); also elsewhere on the board
SA818_RX: U1.46 (GPIO37); also elsewhere on the board
SA818_SQ: U1.47 (GPIO38); also elsewhere on the board
SA818_TX: U1.45 (GPIO36); also elsewhere on the board
SAO1_GPIO1: U1.28 (GPIO27); also elsewhere on the board
SAO1_GPIO2: U1.36 (GPIO28); also elsewhere on the board
SAO2_GPIO1: U1.52 (GPIO41/ADC1); also elsewhere on the board
SAO2_GPIO2: U1.53 (GPIO42/ADC2); also elsewhere on the board
SD_CS: U1.27 (GPIO26); also elsewhere on the board
SPI_MISO: U1.1 (GPIO4); also elsewhere on the board
SPI_MOSI: U1.4 (GPIO7); also elsewhere on the board
SPI_SCK: U1.3 (GPIO6); also elsewhere on the board
SWCLK: U1.33 (SWCLK); also elsewhere on the board
SWDIO: U1.34 (SWDIO); also elsewhere on the board
USB_DM: U1.66 (USB_DM); also elsewhere on the board
USB_DP: U1.67 (USB_DP); also elsewhere on the board

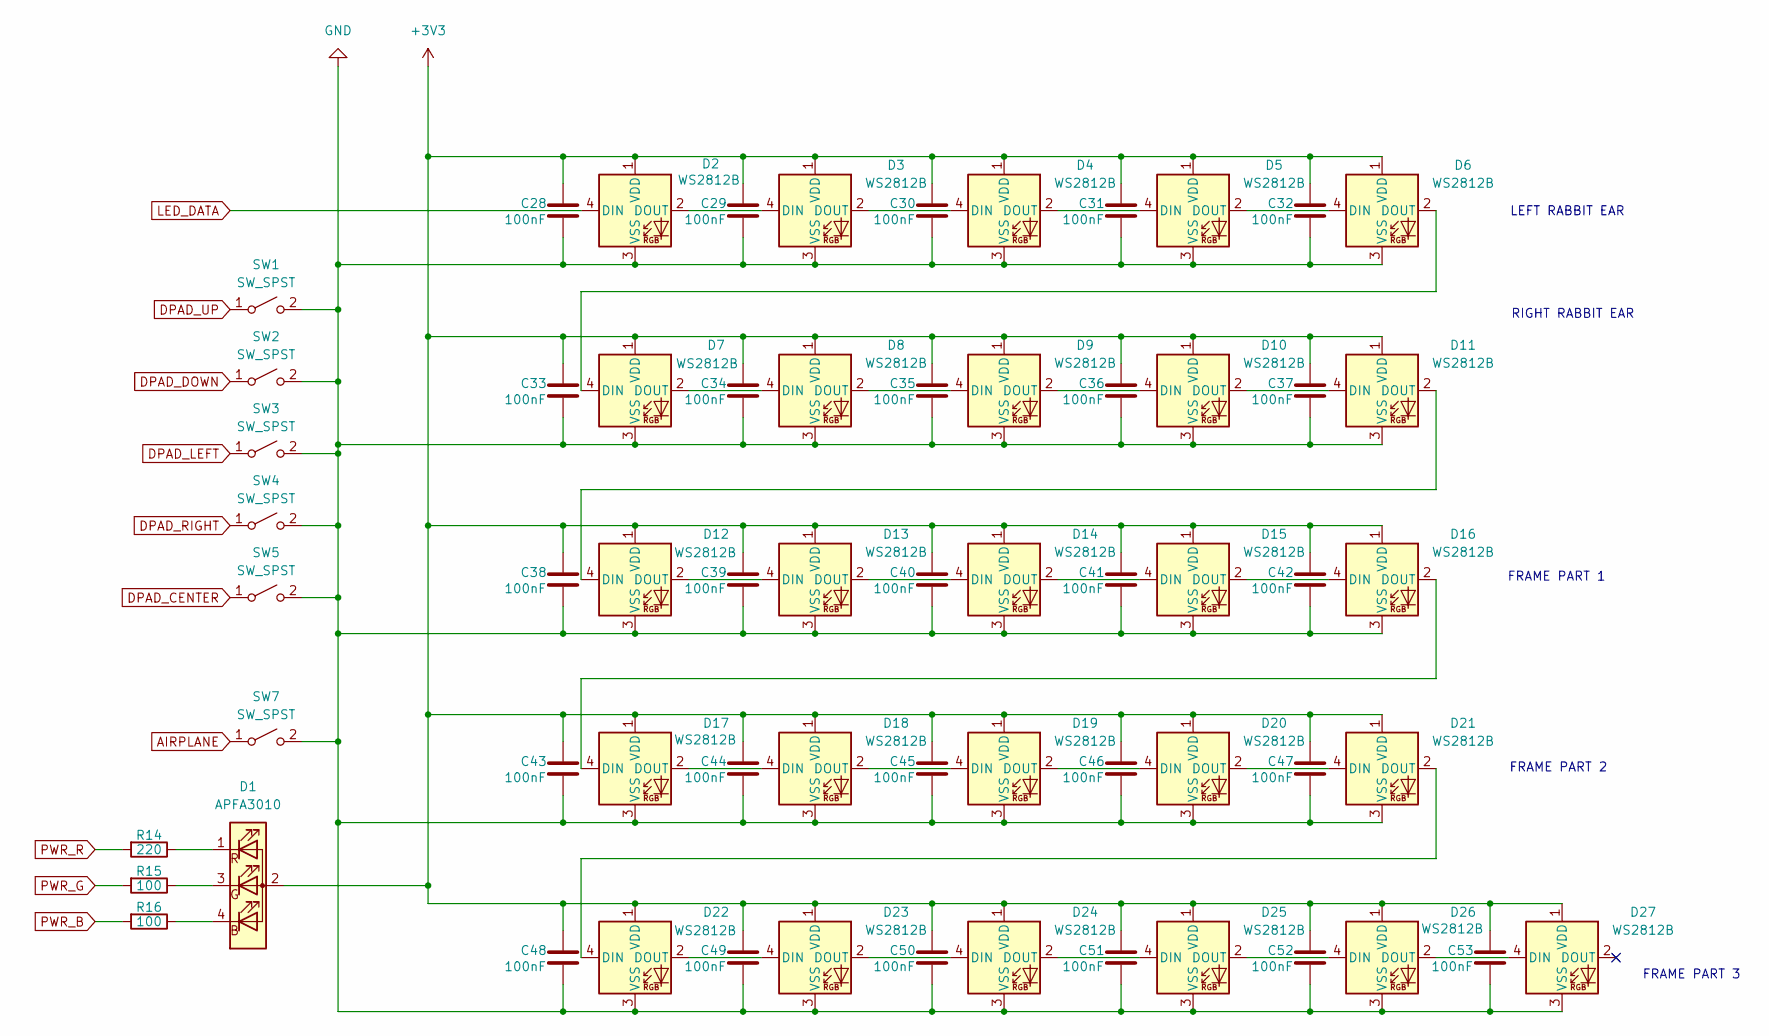
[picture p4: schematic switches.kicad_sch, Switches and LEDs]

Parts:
C28, C29, C30, C31, C32, C33, C34, C35, C36, C37, C38, C39, C40, C41, C42, C43, C44, C45, C46, C47, C48, C49, C50, C51, C52, C53: 100nF; C_0402_1005Metric
D1: APFA3010; LED_Kingbright_APFA3010_3x1.5mm_Horizontal
D2, D3, D4, D5, D6, D7, D8, D9, D10, D11: WS2812B; LED_WS2812B_PLCC4_5.0x5.0mm_P3.2mm
D12, D13, D14, D15, D16, D17, D18, D19, D20, D21, D22, D23, D24, D25, D26, D27: WS2812B; LED_WS2812B-2020_PLCC4_2.0x2.0mm
R14: 220; R_0603_1608Metric
R15, R16: 100; R_0603_1608Metric
SW1, SW2, SW3, SW4, SW5: SW_SPST; SW_PUSH_6mm_H5mm
SW7: SW_SPST; SW_Slide_SPDT_Angled_CK_OS102011MA1Q

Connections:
+3V3: C28.1, C29.1, C30.1, C31.1, C32.1, C33.1, C34.1, C35.1, C36.1, C37.1, C38.1, C39.1, C40.1, C41.1, C42.1, C43.1, C44.1, C45.1, C46.1, C47.1, C48.1, C49.1, C50.1, C51.1, C52.1, C53.1, D1.2 (A), D2.1 (VDD), D3.1 (VDD), D4.1 (VDD), D5.1 (VDD), D6.1 (VDD), D7.1 (VDD), D8.1 (VDD), D9.1 (VDD), D10.1 (VDD), D11.1 (VDD), D12.1 (VDD), D13.1 (VDD), D14.1 (VDD), D15.1 (VDD), D16.1 (VDD), D17.1 (VDD), D18.1 (VDD), D19.1 (VDD), D20.1 (VDD), D21.1 (VDD), D22.1 (VDD), D23.1 (VDD), D24.1 (VDD), D25.1 (VDD), D26.1 (VDD), D27.1 (VDD); also elsewhere on the board
AIRPLANE: SW7.1 (A); also elsewhere on the board
DPAD_CENTER: SW5.1 (A); also elsewhere on the board
DPAD_DOWN: SW2.1 (A); also elsewhere on the board
DPAD_LEFT: SW3.1 (A); also elsewhere on the board
DPAD_RIGHT: SW4.1 (A); also elsewhere on the board
DPAD_UP: SW1.1 (A); also elsewhere on the board
LED_DATA: D2.4 (DIN); also elsewhere on the board
unnamed: D1.4 (B), R16.1
unnamed: D1.3 (G), R15.1
unnamed: D1.1 (R), R14.1
unnamed: D2.2 (DOUT), D3.4 (DIN)
unnamed: D3.2 (DOUT), D4.4 (DIN)
unnamed: D4.2 (DOUT), D5.4 (DIN)
unnamed: D5.2 (DOUT), D6.4 (DIN)
unnamed: D6.2 (DOUT), D7.4 (DIN)
unnamed: D7.2 (DOUT), D8.4 (DIN)
unnamed: D8.2 (DOUT), D9.4 (DIN)
unnamed: D9.2 (DOUT), D10.4 (DIN)
unnamed: D10.2 (DOUT), D11.4 (DIN)
unnamed: D11.2 (DOUT), D12.4 (DIN)
unnamed: D12.2 (DOUT), D13.4 (DIN)
unnamed: D13.2 (DOUT), D14.4 (DIN)
unnamed: D14.2 (DOUT), D15.4 (DIN)
unnamed: D15.2 (DOUT), D16.4 (DIN)
unnamed: D16.2 (DOUT), D17.4 (DIN)
unnamed: D17.2 (DOUT), D18.4 (DIN)
unnamed: D18.2 (DOUT), D19.4 (DIN)
unnamed: D19.2 (DOUT), D20.4 (DIN)
unnamed: D20.2 (DOUT), D21.4 (DIN)
unnamed: D21.2 (DOUT), D22.4 (DIN)
unnamed: D22.2 (DOUT), D23.4 (DIN)
unnamed: D23.2 (DOUT), D24.4 (DIN)
unnamed: D24.2 (DOUT), D25.4 (DIN)
unnamed: D25.2 (DOUT), D26.4 (DIN)
unnamed: D26.2 (DOUT), D27.4 (DIN)
PWR_B: R16.2; also elsewhere on the board
PWR_G: R15.2; also elsewhere on the board
PWR_R: R14.2; also elsewhere on the board

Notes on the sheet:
FRAME PART 2
FRAME PART 3
LEFT RABBIT EAR
FRAME PART 1
RIGHT RABBIT EAR

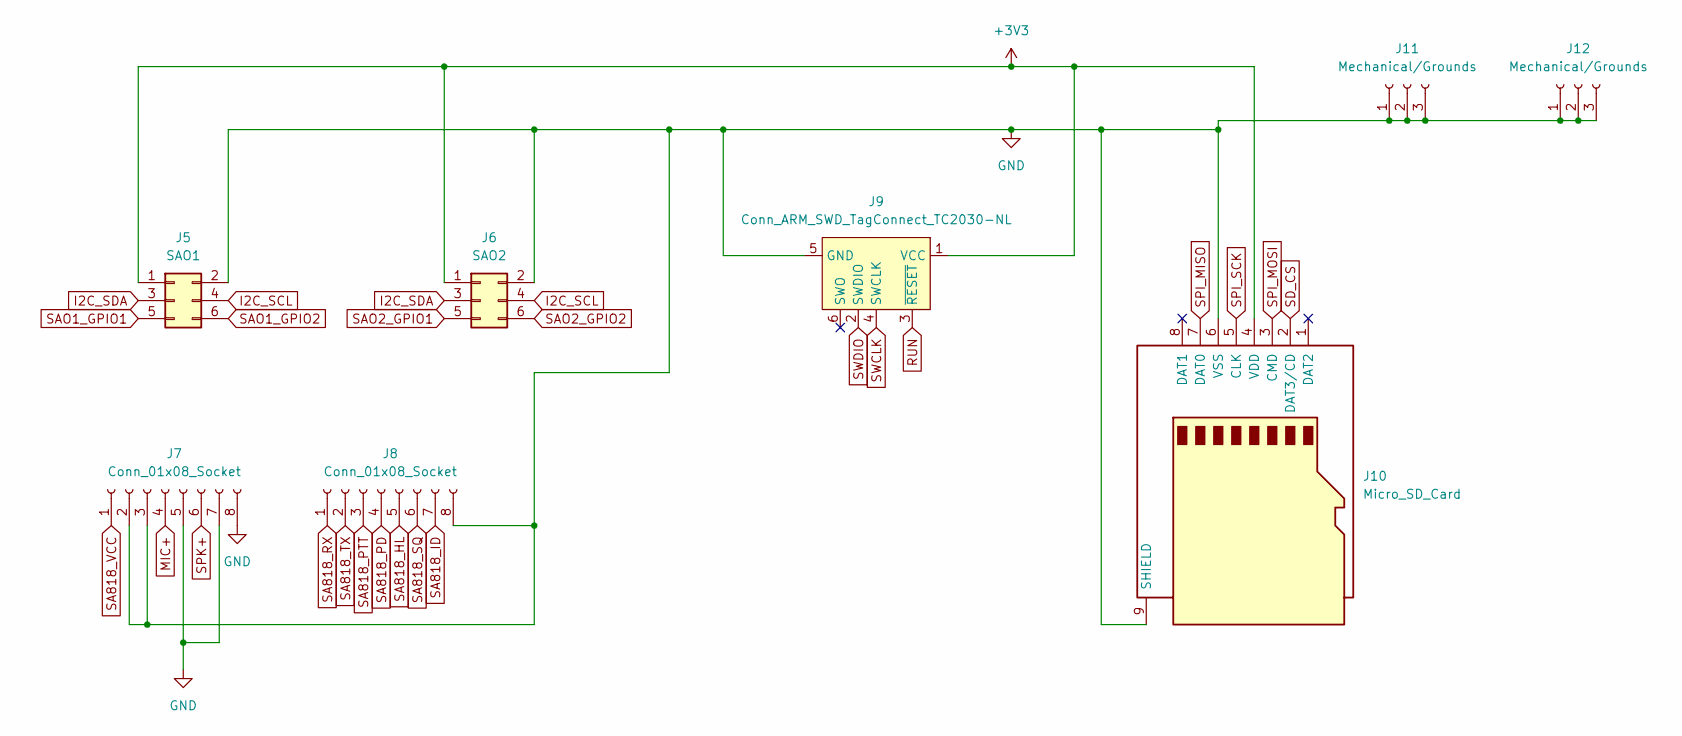
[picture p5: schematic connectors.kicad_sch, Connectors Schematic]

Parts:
J5: SAO1; PinHeader_2x03_P2.54mm_Vertical
J6: SAO2; PinHeader_2x03_P2.54mm_Vertical
J7, J8: Conn_01x08_Socket; PinSocket_1x08_P2.54mm_Vertical
J9: Conn_ARM_SWD_TagConnect_TC2030-NL; Tag-Connect_TC2030-IDC-NL_2x03_P1.27mm_Vertical
J10: Micro_SD_Card; microSD_HC_Molex_104031-0811
J11, J12: Mechanical/Grounds; PinSocket_1x03_P2.54mm_Vertical

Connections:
+3V3: J5.1, J6.1, J9.1 (VCC), J10.4 (VDD); also elsewhere on the board
I2C_SCL: J5.4, J6.4; also elsewhere on the board
I2C_SDA: J5.3, J6.3; also elsewhere on the board
MIC+: J7.4; also elsewhere on the board
RUN: J9.3 (~RESET); also elsewhere on the board
SA818_HL: J8.5; also elsewhere on the board
SA818_ID: J8.7; also elsewhere on the board
SA818_PD: J8.4; also elsewhere on the board
SA818_PTT: J8.3; also elsewhere on the board
SA818_RX: J8.1; also elsewhere on the board
SA818_SQ: J8.6; also elsewhere on the board
SA818_TX: J8.2; also elsewhere on the board
SA818_VCC: J7.1; also elsewhere on the board
SAO1_GPIO1: J5.5; also elsewhere on the board
SAO1_GPIO2: J5.6; also elsewhere on the board
SAO2_GPIO1: J6.5; also elsewhere on the board
SAO2_GPIO2: J6.6; also elsewhere on the board
SD_CS: J10.2 (DAT3/CD); also elsewhere on the board
SPI_MISO: J10.7 (DAT0); also elsewhere on the board
SPI_MOSI: J10.3 (CMD); also elsewhere on the board
SPI_SCK: J10.5 (CLK); also elsewhere on the board
SPK+: J7.6; also elsewhere on the board
SWCLK: J9.4 (SWCLK); also elsewhere on the board
SWDIO: J9.2 (SWDIO); also elsewhere on the board

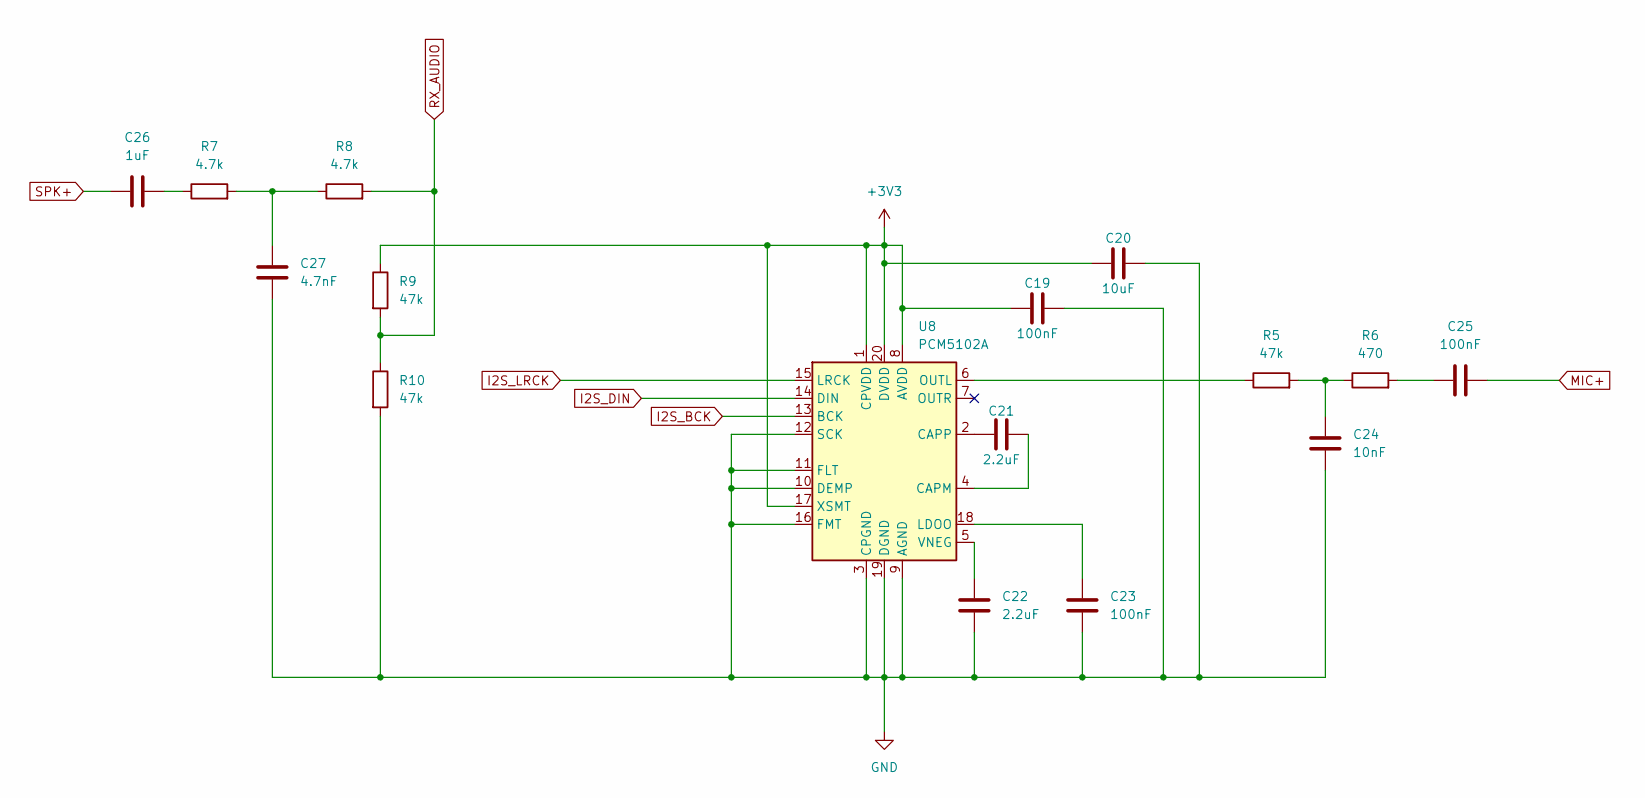
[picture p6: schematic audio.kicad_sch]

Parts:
C19, C23, C25: 100nF; C_0603_1608Metric
C20: 10uF; C_0805_2012Metric
C21, C22: 2.2uF; C_0603_1608Metric
C24: 10nF; C_0603_1608Metric
C26: 1uF; C_0603_1608Metric
C27: 4.7nF; C_0603_1608Metric
R5, R9, R10: 47k; R_0603_1608Metric
R6: 470; R_0603_1608Metric
R7, R8: 4.7k; R_0603_1608Metric
U8: PCM5102A; TSSOP-20_4.4x6.5mm_P0.65mm

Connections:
+3V3: C19.1, C20.1, R9.1, U8.1 (CPVDD), U8.8 (AVDD), U8.17 (XSMT), U8.20 (DVDD); also elsewhere on the board
I2S_BCK: U8.13 (BCK); also elsewhere on the board
I2S_DIN: U8.14 (DIN); also elsewhere on the board
I2S_LRCK: U8.15 (LRCK); also elsewhere on the board
MIC+: C25.2; also elsewhere on the board
unnamed: C24.1, R5.2, R6.1
unnamed: C25.1, R6.2
unnamed: C26.2, R7.1
unnamed: C27.1, R7.2, R8.1
unnamed: C21.2, U8.4 (CAPM)
unnamed: C21.1, U8.2 (CAPP)
unnamed: C23.1, U8.18 (LDOO)
unnamed: R5.1, U8.6 (OUTL)
unnamed: C22.1, U8.5 (VNEG)
RX_AUDIO: R8.2, R9.2, R10.1; also elsewhere on the board
SPK+: C26.1; also elsewhere on the board

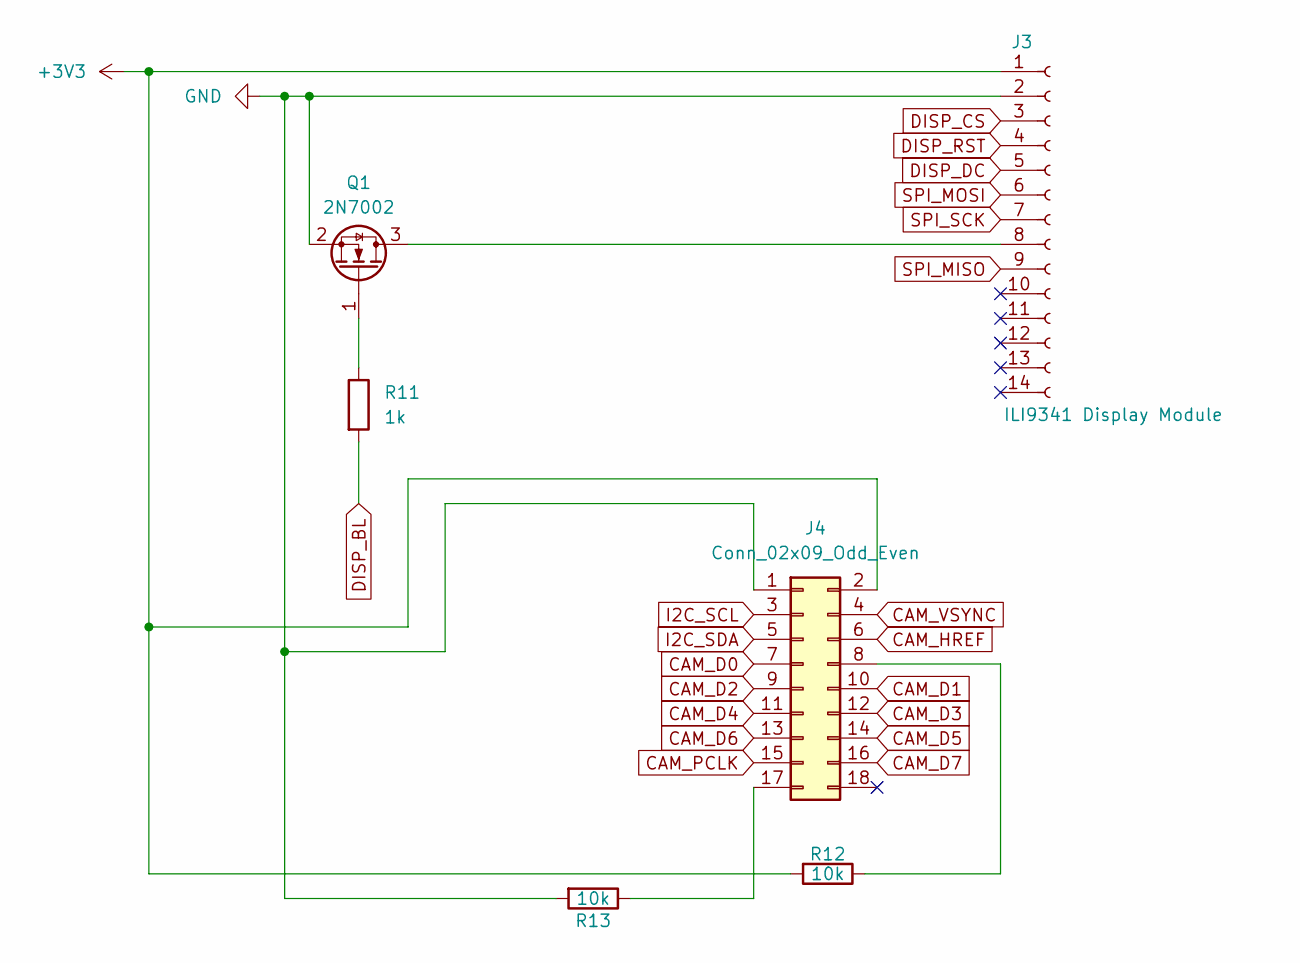
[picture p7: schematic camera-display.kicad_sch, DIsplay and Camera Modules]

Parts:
J3: ILI9341 Display Module; PinSocket_1x14_P2.54mm_Vertical
J4: Conn_02x09_Odd_Even; PinSocket_2x09_P2.54mm_Vertical
Q1: 2N7002; SOT-23
R11: 1k; R_0603_1608Metric
R12, R13: 10k; R_0603_1608Metric

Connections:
+3V3: J3.1, J4.2, R12.2; also elsewhere on the board
CAM_D0: J4.7; also elsewhere on the board
CAM_D1: J4.10; also elsewhere on the board
CAM_D2: J4.9; also elsewhere on the board
CAM_D3: J4.12; also elsewhere on the board
CAM_D4: J4.11; also elsewhere on the board
CAM_D5: J4.14; also elsewhere on the board
CAM_D6: J4.13; also elsewhere on the board
CAM_D7: J4.16; also elsewhere on the board
CAM_HREF: J4.6; also elsewhere on the board
CAM_PCLK: J4.15; also elsewhere on the board
CAM_VSYNC: J4.4; also elsewhere on the board
DISP_BL: R11.2; also elsewhere on the board
DISP_CS: J3.3; also elsewhere on the board
DISP_DC: J3.5; also elsewhere on the board
DISP_RST: J3.4; also elsewhere on the board
I2C_SCL: J4.3; also elsewhere on the board
I2C_SDA: J4.5; also elsewhere on the board
unnamed: J3.8, Q1.3 (D)
unnamed: J4.8, R12.1
unnamed: J4.17, R13.1
unnamed: Q1.1 (G), R11.1
SPI_MISO: J3.9; also elsewhere on the board
SPI_MOSI: J3.6; also elsewhere on the board
SPI_SCK: J3.7; also elsewhere on the board

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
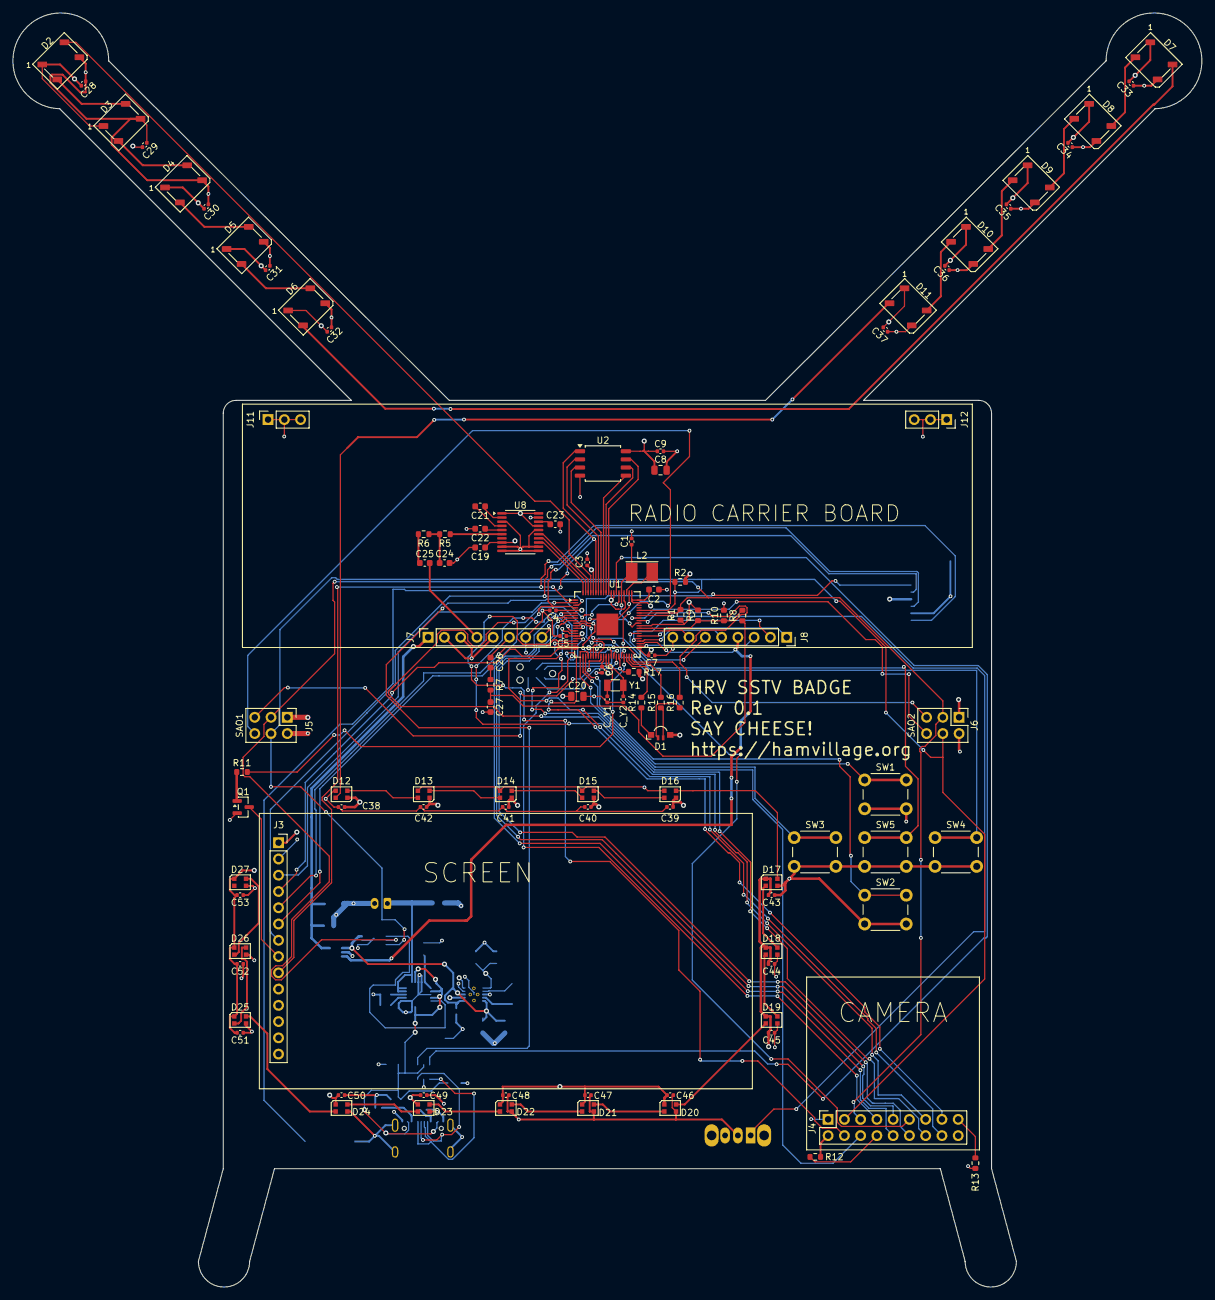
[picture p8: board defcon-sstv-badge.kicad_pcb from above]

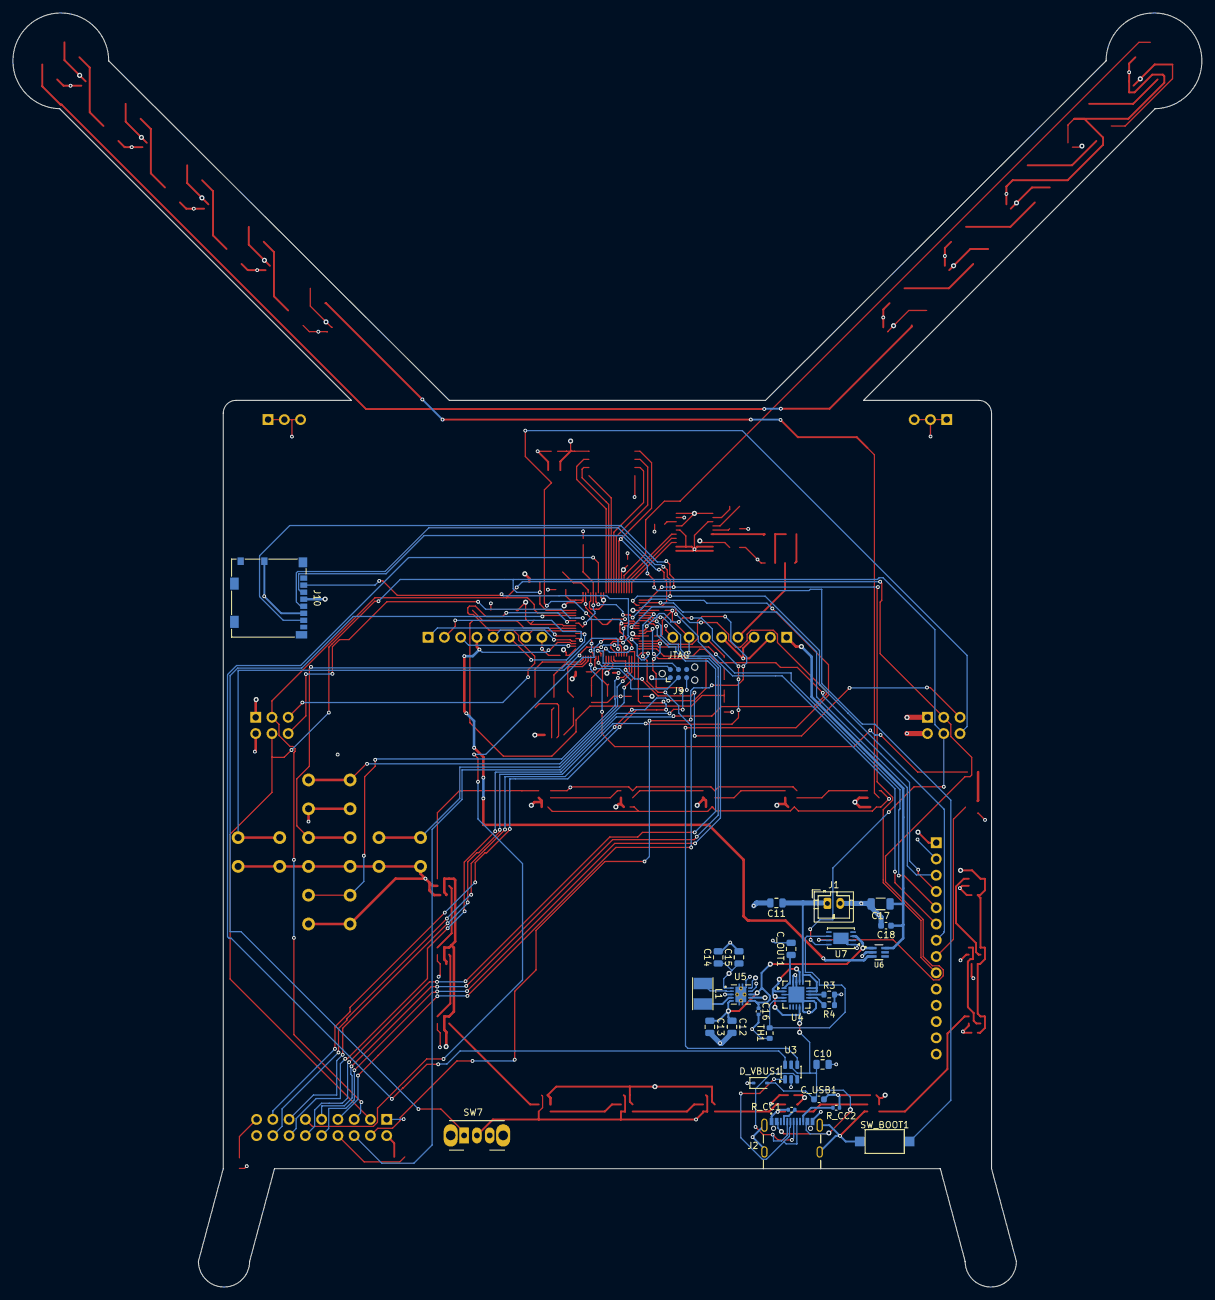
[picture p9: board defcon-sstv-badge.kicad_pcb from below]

Board: 4 copper layers, 185.7 x 199.0 mm, 136 parts (29 on the bottom side), 120 nets.

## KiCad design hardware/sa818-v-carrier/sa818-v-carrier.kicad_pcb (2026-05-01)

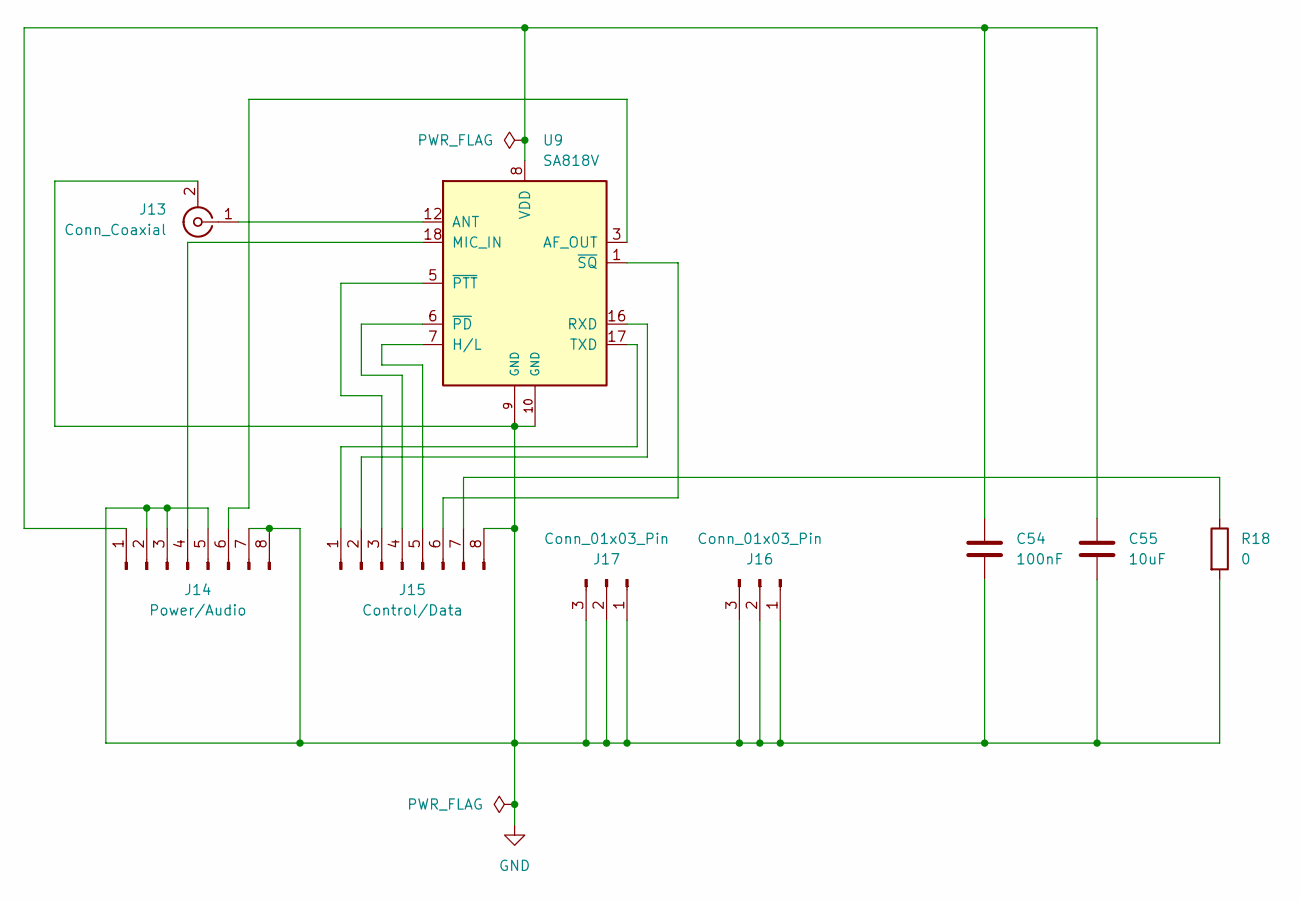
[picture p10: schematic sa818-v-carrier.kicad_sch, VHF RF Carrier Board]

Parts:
C54: 100nF; C_0402_1005Metric
C55: 10uF; C_0603_1608Metric
J13: Conn_Coaxial; SMA_Amphenol_132289_EdgeMount
J14: Power/Audio; PinHeader_1x08_P2.54mm_Vertical
J15: Control/Data; PinHeader_1x08_P2.54mm_Vertical
J16, J17: Conn_01x03_Pin; PinHeader_1x03_P2.54mm_Vertical
R18: 0; R_0402_1005Metric
U9: SA818V; VHF_UHF_Module_generic

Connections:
GND: C54.2, C55.2, J13.2 (Ext), J14.2, J14.3, J14.5, J14.7, J14.8, J15.8, J16.1, J16.2, J16.3, J17.1, J17.2, J17.3, R18.2, U9.9 (GND), U9.10 (GND)
unnamed: J13.1 (In), U9.12 (ANT)
unnamed: C54.1, C55.1, J14.1, U9.8 (VDD)
unnamed: J14.4, U9.18 (MIC_IN)
unnamed: J14.6, U9.3 (AF_OUT)
unnamed: J15.1, U9.17 (TXD)
unnamed: J15.2, U9.16 (RXD)
unnamed: J15.3, U9.5 (~PTT)
unnamed: J15.4, U9.6 (~PD)
unnamed: J15.5, U9.7 (H/L)
unnamed: J15.6, U9.1 (~SQ)
unnamed: J15.7, R18.1

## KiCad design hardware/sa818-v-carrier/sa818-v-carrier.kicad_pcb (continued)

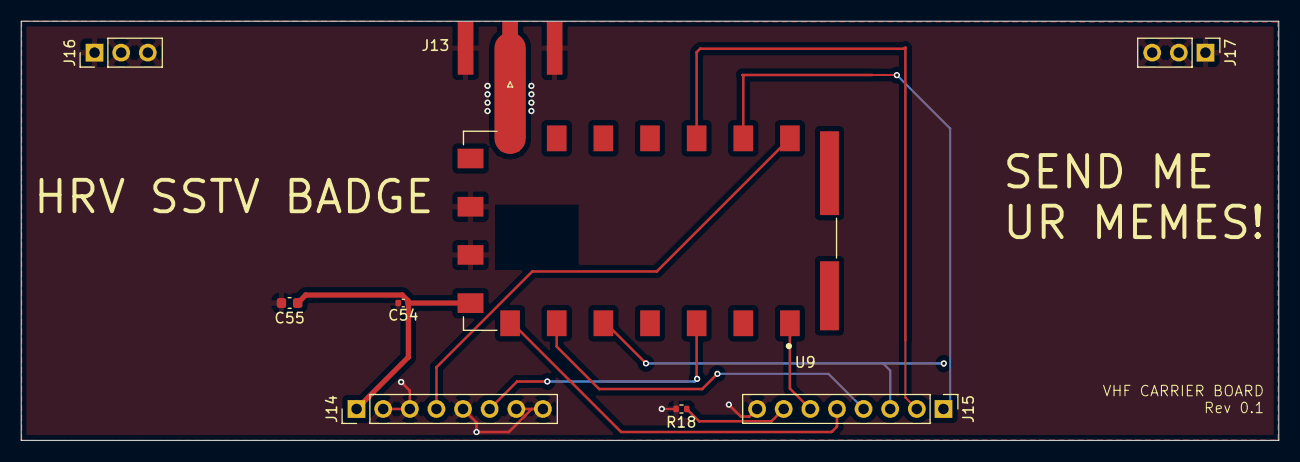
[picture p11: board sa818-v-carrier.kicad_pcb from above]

Board: 2 copper layers, 120.0 x 40.0 mm, 9 parts (0 on the bottom side), 12 nets.

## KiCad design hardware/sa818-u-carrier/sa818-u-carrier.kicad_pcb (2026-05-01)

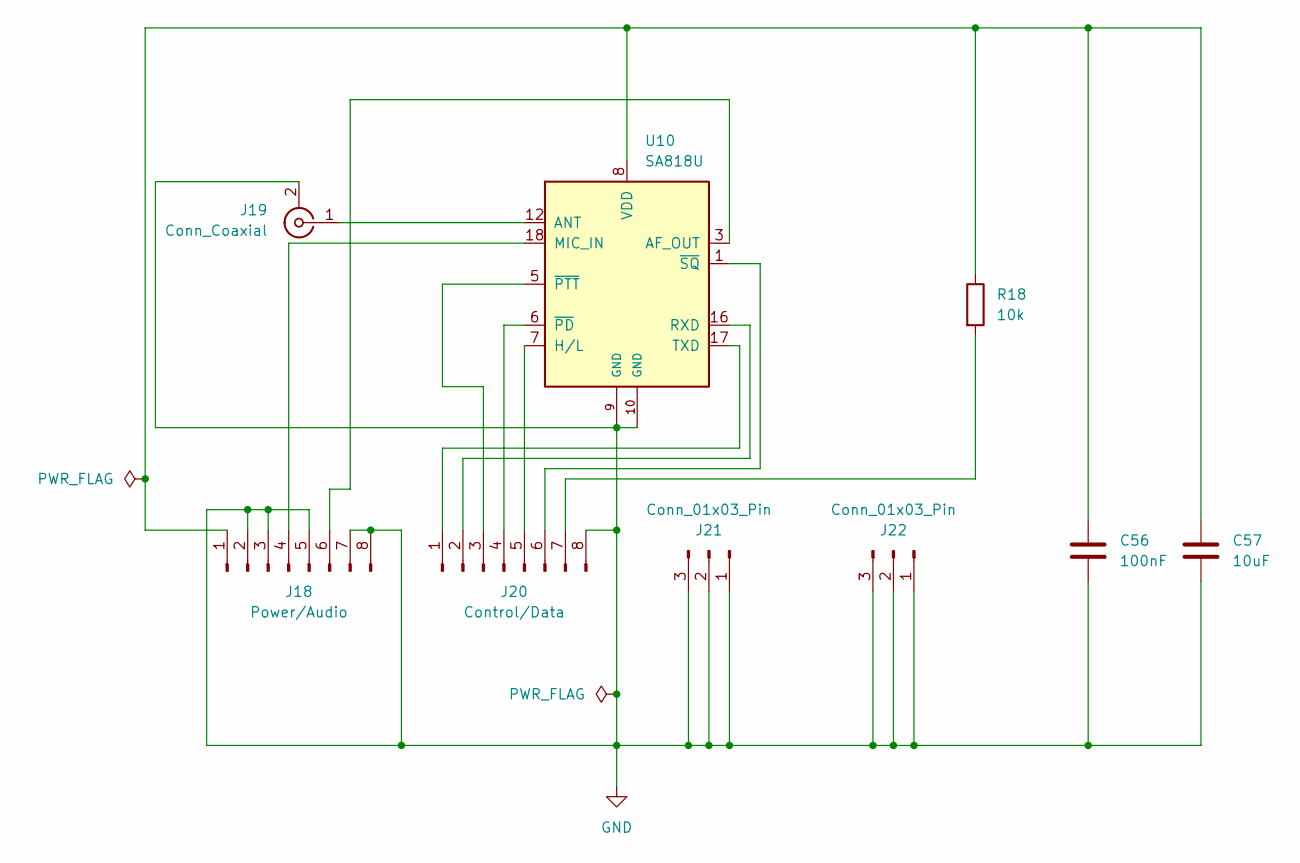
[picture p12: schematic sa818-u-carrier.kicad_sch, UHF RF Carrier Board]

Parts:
C56: 100nF; C_0402_1005Metric
C57: 10uF; C_0603_1608Metric
J18: Power/Audio; PinHeader_1x08_P2.54mm_Vertical
J19: Conn_Coaxial; SMA_Amphenol_132289_EdgeMount
J20: Control/Data; PinHeader_1x08_P2.54mm_Vertical
J21, J22: Conn_01x03_Pin; PinHeader_1x03_P2.54mm_Vertical
R18: 10k; R_0402_1005Metric
U10: SA818U; VHF_UHF_Module_generic

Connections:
GND: C56.2, C57.2, J18.2, J18.3, J18.5, J18.7, J18.8, J19.2 (Ext), J20.8, J21.1, J21.2, J21.3, J22.1, J22.2, J22.3, U10.9 (GND), U10.10 (GND)
unnamed: C56.1, C57.1, J18.1, R18.1, U10.8 (VDD)
unnamed: J18.4, U10.18 (MIC_IN)
unnamed: J18.6, U10.3 (AF_OUT)
unnamed: J19.1 (In), U10.12 (ANT)
unnamed: J20.1, U10.17 (TXD)
unnamed: J20.2, U10.16 (RXD)
unnamed: J20.3, U10.5 (~PTT)
unnamed: J20.4, U10.6 (~PD)
unnamed: J20.5, U10.7 (H/L)
unnamed: J20.6, U10.1 (~SQ)
unnamed: J20.7, R18.2

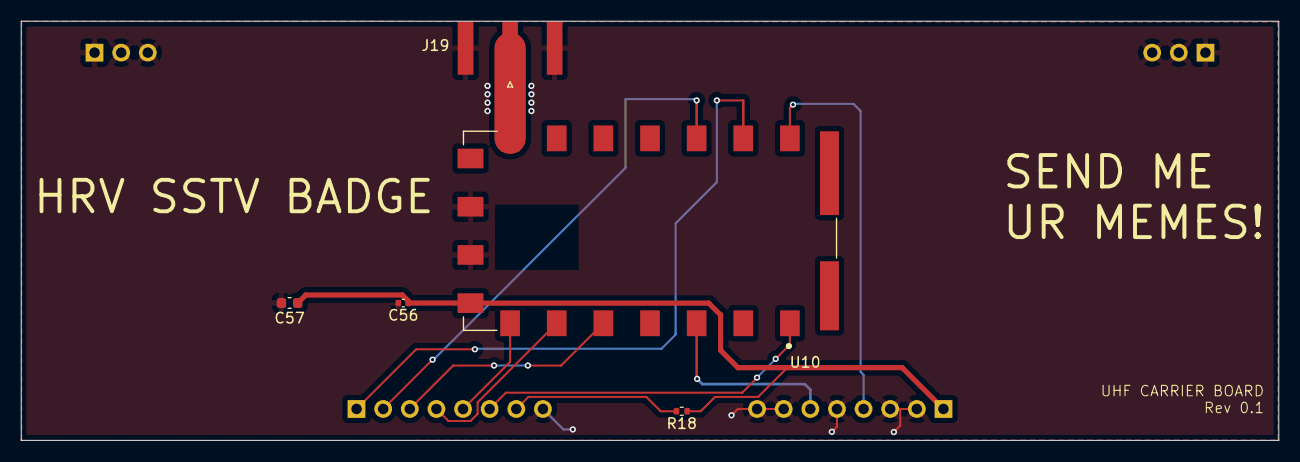
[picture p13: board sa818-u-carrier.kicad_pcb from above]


Board: 2 copper layers, 120.0 x 40.0 mm, 9 parts (4 on the bottom side), 12 nets.

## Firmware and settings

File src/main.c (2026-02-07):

/**
 * DEFCON SSTV Badge - Main Firmware Entry Point
 * 
 * This is your introduction to embedded C! Let's build this step by step.
 * 
 * Key embedded C concepts we'll learn:
 * 1. Memory-mapped I/O and registers
 * 2. Real-time constraints and timing
 * 3. Hardware abstraction layers (HAL)
 * 4. Resource sharing between dual cores
 * 5. Interrupt-driven programming
 */

#include "pico/stdlib.h"        // Core Pico SDK functions
#include "hardware/gpio.h"      // GPIO control functions
#include "hardware/spi.h"       // SPI peripheral control
#include "hardware/i2c.h"       // I2C peripheral control
#include "hardware/uart.h"      // UART peripheral control
#include "pico/multicore.h"     // Dual-core functions
#include <stdio.h>              // Standard I/O for printf

/**
 * Hardware Pin Definitions
 * 
 * In embedded C, we use #define for constants instead of variables.
 * This is because the preprocessor replaces these at compile time,
 * making the code more efficient - no RAM used for storage!
 */

// Status LED - we'll use the built-in LED first
#define STATUS_LED_PIN      25

// SA818 Radio Module Control (UART0)
#define SA818_UART_TX       4
#define SA818_UART_RX       5
#define SA818_UART_ID       uart0
#define SA818_BAUD_RATE     9600

// Display Interface (SPI1) - ST7789 TFT Controller
#define DISPLAY_CS          16      // Chip Select
#define DISPLAY_DC          19      // Data/Command
#define DISPLAY_RST         18      // Reset
#define DISPLAY_BL          20      // Backlight
#define DISPLAY_SPI_ID      spi1

// Camera Interface (I2C0) - OV2640 Camera
#define CAMERA_I2C_SDA      2
#define CAMERA_I2C_SCL      3
#define CAMERA_I2C_ID       i2c0
#define CAMERA_I2C_FREQ     100000  // 100kHz

// Audio Codec Interface (I2C1) - WM8960
#define CODEC_I2C_SDA       6
#define CODEC_I2C_SCL       7
#define CODEC_I2C_ID        i2c1
#define CODEC_I2C_FREQ      400000  // 400kHz

/**
 * Function Declarations
 * 
 * In C, we need to declare functions before using them.
 * This is different from Python where functions can be called
 * after they're defined in the same file.
 */
bool init_gpio(void);
bool init_uart(void);
bool init_spi(void);
bool init_i2c(void);
bool init_hardware_subsystems(void);
void core1_main(void);
void blink_status_led(int count, int delay_ms);

/**
 * Hardware Initialization Functions
 * 
 * In embedded systems, we break initialization into logical groups.
 * Each function returns bool - true for success, false for failure.
 * This is a common embedded C pattern for error handling.
 */

bool init_gpio(void) {
    printf("Initializing GPIO...\n");
    
    // Status LED
    gpio_init(STATUS_LED_PIN);
    gpio_set_dir(STATUS_LED_PIN, GPIO_OUT);
    gpio_put(STATUS_LED_PIN, 0);  // Start with LED off
    
    // Display control pins
    gpio_init(DISPLAY_CS);
    gpio_set_dir(DISPLAY_CS, GPIO_OUT);
    gpio_put(DISPLAY_CS, 1);      // CS high = not selected
    
    gpio_init(DISPLAY_DC);
    gpio_set_dir(DISPLAY_DC, GPIO_OUT);
    
    gpio_init(DISPLAY_RST);
    gpio_set_dir(DISPLAY_RST, GPIO_OUT);
    gpio_put(DISPLAY_RST, 1);     // Not in reset
    
    gpio_init(DISPLAY_BL);
    gpio_set_dir(DISPLAY_BL, GPIO_OUT);
    gpio_put(DISPLAY_BL, 0);      // Backlight off initially
    
    printf("  ✓ GPIO initialized\n");
    return true;
}

bool init_uart(void) {
    printf("Initializing UART for SA818 radio...\n");
    
    // Initialize UART with our baud rate
    uart_init(SA818_UART_ID, SA818_BAUD_RATE);
    
    // Set the GPIO pin functions for UART
    gpio_set_function(SA818_UART_TX, GPIO_FUNC_UART);
    gpio_set_function(SA818_UART_RX, GPIO_FUNC_UART);
    
    // Optional: Configure UART parameters (8N1 is default)
    uart_set_hw_flow(SA818_UART_ID, false, false);  // No hardware flow control
    uart_set_format(SA818_UART_ID, 8, 1, UART_PARITY_NONE);
    
    printf("  ✓ UART0 initialized at %d baud\n", SA818_BAUD_RATE);
    return true;
}

bool init_spi(void) {
    printf("Initializing SPI for display...\n");
    
    // Initialize SPI at 10MHz (safe speed for display)
    spi_init(DISPLAY_SPI_ID, 10 * 1000 * 1000);
    
    // Set GPIO functions for SPI pins
    // Note: CS pin is handled manually as GPIO
    gpio_set_function(16, GPIO_FUNC_SPI);  // MISO (not used for display)
    gpio_set_function(17, GPIO_FUNC_SPI);  // CS (but we use manual CS)
    gpio_set_function(18, GPIO_FUNC_SPI);  // SCK
    gpio_set_function(19, GPIO_FUNC_SPI);  // MOSI
    
    printf("  ✓ SPI1 initialized at 10 MHz\n");
    return true;
}

bool init_i2c(void) {
    printf("Initializing I2C buses...\n");
    
    // I2C0 for camera
    i2c_init(CAMERA_I2C_ID, CAMERA_I2C_FREQ);
    gpio_set_function(CAMERA_I2C_SDA, GPIO_FUNC_I2C);
    gpio_set_function(CAMERA_I2C_SCL, GPIO_FUNC_I2C);
    gpio_pull_up(CAMERA_I2C_SDA);  // Enable pull-ups for I2C
    gpio_pull_up(CAMERA_I2C_SCL);
    
    // I2C1 for audio codec
    i2c_init(CODEC_I2C_ID, CODEC_I2C_FREQ);
    gpio_set_function(CODEC_I2C_SDA, GPIO_FUNC_I2C);
    gpio_set_function(CODEC_I2C_SCL, GPIO_FUNC_I2C);
    gpio_pull_up(CODEC_I2C_SDA);
    gpio_pull_up(CODEC_I2C_SCL);
    
    printf("  ✓ I2C0 initialized at %d Hz (camera)\n", CAMERA_I2C_FREQ);
    printf("  ✓ I2C1 initialized at %d Hz (codec)\n", CODEC_I2C_FREQ);
    return true;
}

bool init_hardware_subsystems(void) {
    printf("\n=== DEFCON SSTV Badge Hardware Initialization ===\n");
    
    // Initialize each subsystem - if any fails, we stop
    if (!init_gpio()) {
        printf("❌ GPIO initialization failed!\n");
        return false;
    }
    
    if (!init_uart()) {
        printf("❌ UART initialization failed!\n");
        return false;
    }
    
    if (!init_spi()) {
        printf("❌ SPI initialization failed!\n");
        return false;
    }
    
    if (!init_i2c()) {
        printf("❌ I2C initialization failed!\n");
        return false;
    }
    
    // Success pattern - blink LED 3 times
    blink_status_led(3, 200);
    printf("✅ All hardware subsystems initialized successfully!\n\n");
    return true;
}

/**
 * Utility function for visual feedback
 * Shows how embedded C handles timing and hardware control
 */
void blink_status_led(int count, int delay_ms) {
    for (int i = 0; i < count; i++) {
        gpio_put(STATUS_LED_PIN, 1);
        sleep_ms(delay_ms);
        gpio_put(STATUS_LED_PIN, 0);
        sleep_ms(delay_ms);
    }
}

/**
 * Core 1 Entry Point
 * 
 * The RP2350 has dual ARM Cortex-M33 cores. We'll use:
 * - Core 0: UI, file system, system management
 * - Core 1: SSTV processing, audio, camera, radio
 */
void core1_main(void) {
    printf("Core 1 started - will handle SSTV processing\n");
    
    // For now, just indicate core 1 is alive
    while (true) {
        sleep_ms(5000);  // Sleep for 5 seconds
        printf("Core 1 heartbeat - SSTV processing ready\n");
    }
}

/**
 * Main Function - Core 0 Entry Point
 * 
 * This is where execution begins when the RP2350 starts up.
 * The boot process goes: Boot ROM → Boot2 → main()
 */
int main() {
    // Initialize USB serial for debugging
    // This is crucial for embedded development - always set up debug output first!
    stdio_init_all();
    
    // Give USB time to enumerate
    sleep_ms(2000);
    
    printf("\n🚀 DEFCON SSTV Badge Starting Up...\n");
    printf("ARM GCC Version: %s\n", __VERSION__);
    printf("Pico SDK Version: %s\n", PICO_SDK_VERSION_STRING);
    printf("Target: RP2350 (ARM Cortex-M33 dual core)\n");
    
    // Initialize all hardware subsystems
    if (!init_hardware_subsystems()) {
        printf("💥 Hardware initialization failed - system halted\n");
        // In embedded systems, if hardware init fails, we usually halt
        while (true) {
            blink_status_led(1, 100);  // Fast blink = error
            sleep_ms(1000);
        }
    }
    
    // Launch Core 1 for signal processing
    printf("🚀 Launching Core 1 for SSTV processing...\n");
    multicore_launch_core1(core1_main);
    
    // Core 0 main loop - handles UI and system management
    printf("📱 Core 0 main loop - handling UI and system management\n");
    
    int loop_counter = 0;
    while (true) {
        // Heartbeat LED - slow pulse
        gpio_put(STATUS_LED_PIN, 1);
        sleep_ms(100);
        gpio_put(STATUS_LED_PIN, 0);
        sleep_ms(1900);
        
        // Periodic status message
        loop_counter++;
        if (loop_counter % 10 == 0) {
            printf("Core 0 heartbeat - system running normally (loop %d)\n", loop_counter);
        }
    }
    
    return 0;  // Never reached in embedded systems
}

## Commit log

2026-02-08 mcu power layout
2026-02-08 add oscilator
    [mcu.kicad_sch]
2026-02-08 add flash reader
    [mcu.kicad_sch]
2026-02-08 ignore kicad backup files
2026-02-08 add bootloader switch
    [mcu.kicad_sch]
2026-02-08 add I2C pullups
    [mcu.kicad_sch]
2026-02-09 add charging controller
2026-02-09 add buck/boost
    [defcon-sstv-badge.kicad_sch, mcu.kicad_sch, power.kicad_sch]
2026-02-09 add TPS22919 for powering off the radio
    [power.kicad_sch]
2026-02-09 add battery fuel gauge
    [power.kicad_sch]
2026-02-09 RX Filter
    [audio.kicad_sch, defcon-sstv-badge.kicad_sch, power.kicad_sch]
2026-02-09 TX Filter pt. 2
    [audio.kicad_sch]
2026-02-10 camera/display sheet
    [camera-display.kicad_sch, defcon-sstv-badge.kicad_sch]
2026-02-10 Buttons and LEDs
    [defcon-sstv-badge.kicad_sch, switches.kicad_sch]
2026-02-11 MCP GPIO pins to labels
    [mcu.kicad_sch]
2026-02-16 all design sheets complete, ERC clean
    [audio.kicad_sch, camera-display.kicad_sch, connectors.kicad_sch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]
2026-02-16 add BOM
    [defcon-sstv-badge-bom.csv]
2026-02-16 update BOM and documentation
    [defcon-sstv-badge-bom.csv, mcu.kicad_sch, power.kicad_sch]
2026-02-16 add carrier boards for SA818 modules
    [SA818-U_Carrier.kicad_sch, connectors.kicad_sch, defcon-sstv-badge-bom.csv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]
2026-02-16 add raw BOM
2026-02-16 add footprints and break carrier boards out into standalone projects
    [SA818-U_Carrier.kicad_sch, audio.kicad_sch, camera-display.kicad_sch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]
2026-02-17 vhf board layout
    [SA818-U_Carrier.kicad_sch, SA818-V_Carrier.kicad_sch, sa818-u-carrier.kicad_pcb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]
2026-03-16 VHF Carrier Board
    [sa818-u-carrier.kicad_pcb, sa818-v-carrier.kicad_pcb, sa818-v-carrier.kicad_sch]
2026-03-16 UHF carrier board
    [sa818-u-carrier.kicad_pcb]
2026-03-16 move main badge files to subdirectory
    [defcon-sstv-badge-bom.csv, defcon-sstv-badge.kicad_pcb, defcon-sstv-badge.kicad_sch]
2026-03-22 main board done except for placing LEDs and drawing ears... I think
    [camera-display.kicad_sch, defcon-sstv-badge.kicad_pcb, mcu.kicad_sch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]
2026-03-22 screen LEDs placed, photo button removed
    [defcon-sstv-badge.kicad_pcb, mcu.kicad_sch, switches.kicad_sch]
2026-03-23 main badge final updates
    [defcon-sstv-badge.kicad_pcb, switches.kicad_sch]
2026-03-23 update text on carrier boards
    [sa818-u-carrier.kicad_pcb, sa818-v-carrier.kicad_pcb]
2026-03-23 update the PCB for tv cabinet feet
    [defcon-sstv-badge.kicad_pcb]
2026-03-23 inital power cap placement
    [defcon-sstv-badge.kicad_pcb]
2026-03-23 most of the load capacitors
    [defcon-sstv-badge.kicad_pcb]
2026-03-25 USB port and chip routed
    [defcon-sstv-badge.kicad_pcb, mcu.kicad_sch]
2026-03-25 U5 routing complete
    [defcon-sstv-badge.kicad_pcb]
2026-03-29 work in progress power subsystems routing
    [defcon-sstv-badge.kicad_pcb, power.kicad_sch]
2026-03-31 traces all fubar, might delete them all and start over.
    [defcon-sstv-badge.kicad_pcb, mcu.kicad_sch]
2026-04-01 clean PCB, prior to rewiring for clean board design
    [defcon-sstv-badge.kicad_pcb]
2026-04-01 updated MCU pin layout
    [mcu.kicad_sch]
2026-04-27 wip routing
    [defcon-sstv-badge-clean.kicad_pcb, defcon-sstv-badge.backup.kicad_pcb, mcu.kicad_sch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]
2026-04-27 more routing, 29 to go...
    [camera-display.kicad_sch, defcon-sstv-badge.kicad_pcb]
2026-05-01 routing. 2 nodes to go...
    [defcon-sstv-badge.kicad_pcb]
2026-05-01 all traces complete, but lots of DRC warnings to fix
    [defcon-sstv-badge.kicad_pcb]
2026-05-01 connect J7 pin 8 to GND
    [connectors.kicad_sch, defcon-sstv-badge.kicad_pcb]
2026-05-01 routing and component bug fixes
    [sa818-u-carrier.kicad_pcb, sa818-u-carrier.kicad_sch, sa818-v-carrier.kicad_pcb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]
2026-05-10 main board finished, no DRC errors
    [defcon-sstv-badge.kicad_pcb]
